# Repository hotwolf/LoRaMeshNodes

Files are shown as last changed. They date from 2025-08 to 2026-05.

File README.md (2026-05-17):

# LoRaMeshNodes
A collection of DIY LoRa mesh nodes:

- [MSNvA (Mobile Solar Node Variant A)](https://github.com/hotwolf/LoRaMeshNodes/tree/main/MSNvA)

  MSNvA
- [MSNvB (Mobile Solar Node Variant B)](https://github.com/hotwolf/LoRaMeshNodes/tree/main/MSNvB)

  MSNvB
- [MNvA  (Mobile Node Variant A)](https://github.com/hotwolf/LoRaMeshNodes/tree/main/MNvA)

  MNvA
- [MNvB  (Mobile Node Variant B)](https://github.com/hotwolf/LoRaMeshNodes/tree/main/MNvB)

  MNvB
- [SSNvA (Stationary Solar Node Variant A)](https://github.com/hotwolf/LoRaMeshNodes/tree/main/SSNvA)

  SSNvA
- [SSNvB (Stationary Solar Node Variant B)](https://github.com/hotwolf/LoRaMeshNodes/tree/main/SSNvB)

  SSNvB
- [SSNvD (Stationary Solar Node Variant D)](https://github.com/hotwolf/LoRaMeshNodes/tree/main/SSNvD)

  SSNvD

And tools:

- [LiFePo4Charger (A 1S 32700 LiFePO4 battery charger)](https://github.com/hotwolf/LoRaMeshNodes/tree/main/LiFePo4Charger)

  LiFePo4Charger

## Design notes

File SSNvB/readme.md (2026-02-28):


# LoRaMeshNodes
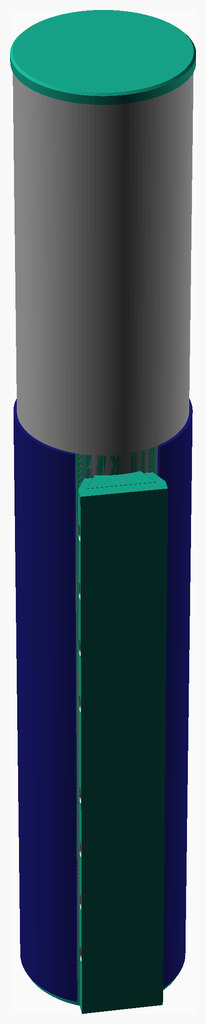
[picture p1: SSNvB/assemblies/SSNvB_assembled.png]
Main Assembly


<span></span>

---
## Table of Contents
1. [Parts list](#Parts_list)
1. [SSNvB Pipe Assembly](#SSNvB_pipe_assembly)
1. [SSNvB Solar Assembly](#SSNvB_solar_assembly)
1. [SSNvB Battery Cable Clamp Assembly](#SSNvB_battery_cable_clamp_assembly)
1. [SSNvB Battery Frame Assembly](#SSNvB_battery_frame_assembly)
1. [SSNvB Battery Assembly](#SSNvB_battery_assembly)
1. [SSNvB Radio Frame Assembly](#SSNvB_radio_frame_assembly)
1. [SSNvB Radio Assembly](#SSNvB_radio_assembly)
1. [SSNvB Antenna Assembly](#SSNvB_antenna_assembly)
1. [SSNvB Core Assembly](#SSNvB_core_assembly)
1. [SSNvB Assembly](#SSNvB_assembly)

<span></span>
[Top](#TOP)

---

## Parts list
| <span style="writing-mode: vertical-rl; text-orientation: mixed;">SSNvB&nbsp;Pipe</span> | <span style="writing-mode: vertical-rl; text-orientation: mixed;">SSNvB&nbsp;Solar</span> | <span style="writing-mode: vertical-rl; text-orientation: mixed;">SSNvB&nbsp;Battery&nbsp;Cable&nbsp;Clamp</span> | <span style="writing-mode: vertical-rl; text-orientation: mixed;">SSNvB&nbsp;Battery&nbsp;Frame</span> | <span style="writing-mode: vertical-rl; text-orientation: mixed;">SSNvB&nbsp;Battery</span> | <span style="writing-mode: vertical-rl; text-orientation: mixed;">SSNvB&nbsp;Radio&nbsp;Frame</span> | <span style="writing-mode: vertical-rl; text-orientation: mixed;">SSNvB&nbsp;Radio</span> | <span style="writing-mode: vertical-rl; text-orientation: mixed;">SSNvB&nbsp;Antenna</span> | <span style="writing-mode: vertical-rl; text-orientation: mixed;">SSNvB&nbsp;Core</span> | <span style="writing-mode: vertical-rl; text-orientation: mixed;">SSNvB</span> | <span style="writing-mode: vertical-rl; text-orientation: mixed;">TOTALS</span> |  |
|---:|---:|---:|---:|---:|---:|---:|---:|---:|---:|---:|:---|
|  |  |  |  |  |  |  |  |  |  | | **Vitamins** |
| &nbsp;&nbsp;.&nbsp; | &nbsp;&nbsp;.&nbsp; | &nbsp;&nbsp;.&nbsp; | &nbsp;&nbsp;.&nbsp; | &nbsp;&nbsp;1&nbsp; | &nbsp;&nbsp;.&nbsp; | &nbsp;&nbsp;.&nbsp; | &nbsp;&nbsp;.&nbsp; | &nbsp;&nbsp;.&nbsp; | &nbsp;&nbsp;.&nbsp; |  &nbsp;&nbsp;1&nbsp; | &nbsp;&nbsp; 1S 3.2V battery protection board |
| &nbsp;&nbsp;.&nbsp; | &nbsp;&nbsp;.&nbsp; | &nbsp;&nbsp;.&nbsp; | &nbsp;&nbsp;.&nbsp; | &nbsp;&nbsp;.&nbsp; | &nbsp;&nbsp;.&nbsp; | &nbsp;&nbsp;.&nbsp; | &nbsp;&nbsp;1&nbsp; | &nbsp;&nbsp;.&nbsp; | &nbsp;&nbsp;.&nbsp; |  &nbsp;&nbsp;1&nbsp; | &nbsp;&nbsp; Antenna with N-connector |
| &nbsp;&nbsp;.&nbsp; | &nbsp;&nbsp;.&nbsp; | &nbsp;&nbsp;.&nbsp; | &nbsp;&nbsp;.&nbsp; | &nbsp;&nbsp;1&nbsp; | &nbsp;&nbsp;.&nbsp; | &nbsp;&nbsp;.&nbsp; | &nbsp;&nbsp;.&nbsp; | &nbsp;&nbsp;.&nbsp; | &nbsp;&nbsp;.&nbsp; |  &nbsp;&nbsp;1&nbsp; | &nbsp;&nbsp; Battery negative contact |
| &nbsp;&nbsp;.&nbsp; | &nbsp;&nbsp;.&nbsp; | &nbsp;&nbsp;.&nbsp; | &nbsp;&nbsp;.&nbsp; | &nbsp;&nbsp;1&nbsp; | &nbsp;&nbsp;.&nbsp; | &nbsp;&nbsp;.&nbsp; | &nbsp;&nbsp;.&nbsp; | &nbsp;&nbsp;.&nbsp; | &nbsp;&nbsp;.&nbsp; |  &nbsp;&nbsp;1&nbsp; | &nbsp;&nbsp; Battery positive contact |
| &nbsp;&nbsp;1&nbsp; | &nbsp;&nbsp;.&nbsp; | &nbsp;&nbsp;.&nbsp; | &nbsp;&nbsp;.&nbsp; | &nbsp;&nbsp;.&nbsp; | &nbsp;&nbsp;.&nbsp; | &nbsp;&nbsp;.&nbsp; | &nbsp;&nbsp;.&nbsp; | &nbsp;&nbsp;.&nbsp; | &nbsp;&nbsp;.&nbsp; |  &nbsp;&nbsp;1&nbsp; | &nbsp;&nbsp; Conduit diameter 40mmlength 470mm |
| &nbsp;&nbsp;.&nbsp; | &nbsp;&nbsp;3&nbsp; | &nbsp;&nbsp;.&nbsp; | &nbsp;&nbsp;.&nbsp; | &nbsp;&nbsp;.&nbsp; | &nbsp;&nbsp;.&nbsp; | &nbsp;&nbsp;.&nbsp; | &nbsp;&nbsp;.&nbsp; | &nbsp;&nbsp;.&nbsp; | &nbsp;&nbsp;.&nbsp; |  &nbsp;&nbsp;3&nbsp; | &nbsp;&nbsp; Flexible Solar Panel 198x100mm² 6V 1W |
| &nbsp;&nbsp;.&nbsp; | &nbsp;&nbsp;.&nbsp; | &nbsp;&nbsp;.&nbsp; | &nbsp;&nbsp;.&nbsp; | &nbsp;&nbsp;.&nbsp; | &nbsp;&nbsp;.&nbsp; | &nbsp;&nbsp;1&nbsp; | &nbsp;&nbsp;.&nbsp; | &nbsp;&nbsp;.&nbsp; | &nbsp;&nbsp;.&nbsp; |  &nbsp;&nbsp;1&nbsp; | &nbsp;&nbsp; Heltec T144 |
| &nbsp;&nbsp;.&nbsp; | &nbsp;&nbsp;.&nbsp; | &nbsp;&nbsp;.&nbsp; | &nbsp;&nbsp;.&nbsp; | &nbsp;&nbsp;1&nbsp; | &nbsp;&nbsp;.&nbsp; | &nbsp;&nbsp;.&nbsp; | &nbsp;&nbsp;.&nbsp; | &nbsp;&nbsp;.&nbsp; | &nbsp;&nbsp;.&nbsp; |  &nbsp;&nbsp;1&nbsp; | &nbsp;&nbsp; Li-Ion/LiFePo4 32700 3.2v |
| &nbsp;&nbsp;.&nbsp; | &nbsp;&nbsp;.&nbsp; | &nbsp;&nbsp;.&nbsp; | &nbsp;&nbsp;.&nbsp; | &nbsp;&nbsp;1&nbsp; | &nbsp;&nbsp;.&nbsp; | &nbsp;&nbsp;.&nbsp; | &nbsp;&nbsp;.&nbsp; | &nbsp;&nbsp;.&nbsp; | &nbsp;&nbsp;.&nbsp; |  &nbsp;&nbsp;1&nbsp; | &nbsp;&nbsp; MPPT Solar Charge Controller |
| &nbsp;&nbsp;.&nbsp; | &nbsp;&nbsp;.&nbsp; | &nbsp;&nbsp;2&nbsp; | &nbsp;&nbsp;.&nbsp; | &nbsp;&nbsp;.&nbsp; | &nbsp;&nbsp;.&nbsp; | &nbsp;&nbsp;.&nbsp; | &nbsp;&nbsp;.&nbsp; | &nbsp;&nbsp;.&nbsp; | &nbsp;&nbsp;.&nbsp; |  &nbsp;&nbsp;2&nbsp; | &nbsp;&nbsp; Nut M3 x 2.4mm  |
| &nbsp;&nbsp;.&nbsp; | &nbsp;&nbsp;.&nbsp; | &nbsp;&nbsp;.&nbsp; | &nbsp;&nbsp;.&nbsp; | &nbsp;&nbsp;2&nbsp; | &nbsp;&nbsp;.&nbsp; | &nbsp;&nbsp;.&nbsp; | &nbsp;&nbsp;.&nbsp; | &nbsp;&nbsp;.&nbsp; | &nbsp;&nbsp;.&nbsp; |  &nbsp;&nbsp;2&nbsp; | &nbsp;&nbsp; Screw M3 pan x 10mm |
| &nbsp;&nbsp;.&nbsp; | &nbsp;&nbsp;.&nbsp; | &nbsp;&nbsp;.&nbsp; | &nbsp;&nbsp;.&nbsp; | &nbsp;&nbsp;2&nbsp; | &nbsp;&nbsp;.&nbsp; | &nbsp;&nbsp;.&nbsp; | &nbsp;&nbsp;.&nbsp; | &nbsp;&nbsp;.&nbsp; | &nbsp;&nbsp;.&nbsp; |  &nbsp;&nbsp;2&nbsp; | &nbsp;&nbsp; Washer  M3 x 7mm x 0.5mm |
| &nbsp;&nbsp;1&nbsp; | &nbsp;&nbsp;3&nbsp; | &nbsp;&nbsp;2&nbsp; | &nbsp;&nbsp;.&nbsp; | &nbsp;&nbsp;9&nbsp; | &nbsp;&nbsp;.&nbsp; | &nbsp;&nbsp;1&nbsp; | &nbsp;&nbsp;1&nbsp; | &nbsp;&nbsp;.&nbsp; | &nbsp;&nbsp;.&nbsp; | &nbsp;&nbsp;17&nbsp; | &nbsp;&nbsp;Total vitamins count |
|  |  |  |  |  |  |  |  |  |  | | **3D printed parts** |
| &nbsp;&nbsp;2&nbsp; | &nbsp;&nbsp;.&nbsp; | &nbsp;&nbsp;.&nbsp; | &nbsp;&nbsp;.&nbsp; | &nbsp;&nbsp;.&nbsp; | &nbsp;&nbsp;.&nbsp; | &nbsp;&nbsp;.&nbsp; | &nbsp;&nbsp;.&nbsp; | &nbsp;&nbsp;.&nbsp; | &nbsp;&nbsp;.&nbsp; |  &nbsp;&nbsp;2&nbsp; | &nbsp;&nbsp;SSNvB_EndcapThread.stl |
| &nbsp;&nbsp;1&nbsp; | &nbsp;&nbsp;.&nbsp; | &nbsp;&nbsp;.&nbsp; | &nbsp;&nbsp;.&nbsp; | &nbsp;&nbsp;.&nbsp; | &nbsp;&nbsp;.&nbsp; | &nbsp;&nbsp;.&nbsp; | &nbsp;&nbsp;.&nbsp; | &nbsp;&nbsp;.&nbsp; | &nbsp;&nbsp;.&nbsp; |  &nbsp;&nbsp;1&nbsp; | &nbsp;&nbsp;SSNvB_LIEncMount.stl |
| &nbsp;&nbsp;1&nbsp; | &nbsp;&nbsp;.&nbsp; | &nbsp;&nbsp;.&nbsp; | &nbsp;&nbsp;.&nbsp; | &nbsp;&nbsp;.&nbsp; | &nbsp;&nbsp;.&nbsp; | &nbsp;&nbsp;.&nbsp; | &nbsp;&nbsp;.&nbsp; | &nbsp;&nbsp;.&nbsp; | &nbsp;&nbsp;.&nbsp; |  &nbsp;&nbsp;1&nbsp; | &nbsp;&nbsp;SSNvB_LOEncMount.stl |
| &nbsp;&nbsp;1&nbsp; | &nbsp;&nbsp;.&nbsp; | &nbsp;&nbsp;.&nbsp; | &nbsp;&nbsp;.&nbsp; | &nbsp;&nbsp;.&nbsp; | &nbsp;&nbsp;.&nbsp; | &nbsp;&nbsp;.&nbsp; | &nbsp;&nbsp;.&nbsp; | &nbsp;&nbsp;.&nbsp; | &nbsp;&nbsp;.&nbsp; |  &nbsp;&nbsp;1&nbsp; | &nbsp;&nbsp;SSNvB_UIEncMount.stl |
| &nbsp;&nbsp;1&nbsp; | &nbsp;&nbsp;.&nbsp; | &nbsp;&nbsp;.&nbsp; | &nbsp;&nbsp;.&nbsp; | &nbsp;&nbsp;.&nbsp; | &nbsp;&nbsp;.&nbsp; | &nbsp;&nbsp;.&nbsp; | &nbsp;&nbsp;.&nbsp; | &nbsp;&nbsp;.&nbsp; | &nbsp;&nbsp;.&nbsp; |  &nbsp;&nbsp;1&nbsp; | &nbsp;&nbsp;SSNvB_UOEncMount.stl |
| &nbsp;&nbsp;.&nbsp; | &nbsp;&nbsp;.&nbsp; | &nbsp;&nbsp;.&nbsp; | &nbsp;&nbsp;.&nbsp; | &nbsp;&nbsp;.&nbsp; | &nbsp;&nbsp;.&nbsp; | &nbsp;&nbsp;.&nbsp; | &nbsp;&nbsp;1&nbsp; | &nbsp;&nbsp;.&nbsp; | &nbsp;&nbsp;.&nbsp; |  &nbsp;&nbsp;1&nbsp; | &nbsp;&nbsp;SSNvB_antenna.stl |
| &nbsp;&nbsp;.&nbsp; | &nbsp;&nbsp;.&nbsp; | &nbsp;&nbsp;.&nbsp; | &nbsp;&nbsp;.&nbsp; | &nbsp;&nbsp;.&nbsp; | &nbsp;&nbsp;.&nbsp; | &nbsp;&nbsp;.&nbsp; | &nbsp;&nbsp;.&nbsp; | &nbsp;&nbsp;.&nbsp; | &nbsp;&nbsp;1&nbsp; |  &nbsp;&nbsp;1&nbsp; | &nbsp;&nbsp;SSNvB_antennaMountFastener.stl |
| &nbsp;&nbsp;1&nbsp; | &nbsp;&nbsp;.&nbsp; | &nbsp;&nbsp;.&nbsp; | &nbsp;&nbsp;.&nbsp; | &nbsp;&nbsp;.&nbsp; | &nbsp;&nbsp;.&nbsp; | &nbsp;&nbsp;.&nbsp; | &nbsp;&nbsp;.&nbsp; | &nbsp;&nbsp;.&nbsp; | &nbsp;&nbsp;.&nbsp; |  &nbsp;&nbsp;1&nbsp; | &nbsp;&nbsp;SSNvB_antennaMountThread.stl |
| &nbsp;&nbsp;.&nbsp; | &nbsp;&nbsp;.&nbsp; | &nbsp;&nbsp;1&nbsp; | &nbsp;&nbsp;.&nbsp; | &nbsp;&nbsp;.&nbsp; | &nbsp;&nbsp;.&nbsp; | &nbsp;&nbsp;.&nbsp; | &nbsp;&nbsp;.&nbsp; | &nbsp;&nbsp;.&nbsp; | &nbsp;&nbsp;.&nbsp; |  &nbsp;&nbsp;1&nbsp; | &nbsp;&nbsp;SSNvB_battery_cable_clamp.stl |
| &nbsp;&nbsp;.&nbsp; | &nbsp;&nbsp;.&nbsp; | &nbsp;&nbsp;.&nbsp; | &nbsp;&nbsp;1&nbsp; | &nbsp;&nbsp;.&nbsp; | &nbsp;&nbsp;.&nbsp; | &nbsp;&nbsp;.&nbsp; | &nbsp;&nbsp;.&nbsp; | &nbsp;&nbsp;.&nbsp; | &nbsp;&nbsp;.&nbsp; |  &nbsp;&nbsp;1&nbsp; | &nbsp;&nbsp;SSNvB_battery_frame_part1.stl |
| &nbsp;&nbsp;.&nbsp; | &nbsp;&nbsp;.&nbsp; | &nbsp;&nbsp;.&nbsp; | &nbsp;&nbsp;1&nbsp; | &nbsp;&nbsp;.&nbsp; | &nbsp;&nbsp;.&nbsp; | &nbsp;&nbsp;.&nbsp; | &nbsp;&nbsp;.&nbsp; | &nbsp;&nbsp;.&nbsp; | &nbsp;&nbsp;.&nbsp; |  &nbsp;&nbsp;1&nbsp; | &nbsp;&nbsp;SSNvB_battery_frame_part2.stl |
| &nbsp;&nbsp;.&nbsp; | &nbsp;&nbsp;.&nbsp; | &nbsp;&nbsp;.&nbsp; | &nbsp;&nbsp;.&nbsp; | &nbsp;&nbsp;.&nbsp; | &nbsp;&nbsp;.&nbsp; | &nbsp;&nbsp;.&nbsp; | &nbsp;&nbsp;.&nbsp; | &nbsp;&nbsp;.&nbsp; | &nbsp;&nbsp;1&nbsp; |  &nbsp;&nbsp;1&nbsp; | &nbsp;&nbsp;SSNvB_lEndcap.stl |
| &nbsp;&nbsp;.&nbsp; | &nbsp;&nbsp;.&nbsp; | &nbsp;&nbsp;.&nbsp; | &nbsp;&nbsp;.&nbsp; | &nbsp;&nbsp;.&nbsp; | &nbsp;&nbsp;1&nbsp; | &nbsp;&nbsp;.&nbsp; | &nbsp;&nbsp;.&nbsp; | &nbsp;&nbsp;.&nbsp; | &nbsp;&nbsp;.&nbsp; |  &nbsp;&nbsp;1&nbsp; | &nbsp;&nbsp;SSNvB_radio_frame_part1.stl |
| &nbsp;&nbsp;.&nbsp; | &nbsp;&nbsp;.&nbsp; | &nbsp;&nbsp;.&nbsp; | &nbsp;&nbsp;.&nbsp; | &nbsp;&nbsp;.&nbsp; | &nbsp;&nbsp;1&nbsp; | &nbsp;&nbsp;.&nbsp; | &nbsp;&nbsp;.&nbsp; | &nbsp;&nbsp;.&nbsp; | &nbsp;&nbsp;.&nbsp; |  &nbsp;&nbsp;1&nbsp; | &nbsp;&nbsp;SSNvB_radio_frame_part2.stl |
| &nbsp;&nbsp;.&nbsp; | &nbsp;&nbsp;.&nbsp; | &nbsp;&nbsp;.&nbsp; | &nbsp;&nbsp;.&nbsp; | &nbsp;&nbsp;.&nbsp; | &nbsp;&nbsp;.&nbsp; | &nbsp;&nbsp;.&nbsp; | &nbsp;&nbsp;.&nbsp; | &nbsp;&nbsp;.&nbsp; | &nbsp;&nbsp;1&nbsp; |  &nbsp;&nbsp;1&nbsp; | &nbsp;&nbsp;SSNvB_uEndcap.stl |
| &nbsp;&nbsp;7&nbsp; | &nbsp;&nbsp;.&nbsp; | &nbsp;&nbsp;1&nbsp; | &nbsp;&nbsp;2&nbsp; | &nbsp;&nbsp;.&nbsp; | &nbsp;&nbsp;2&nbsp; | &nbsp;&nbsp;.&nbsp; | &nbsp;&nbsp;1&nbsp; | &nbsp;&nbsp;.&nbsp; | &nbsp;&nbsp;3&nbsp; | &nbsp;&nbsp;16&nbsp; | &nbsp;&nbsp;Total 3D printed parts count |

<span></span>
[Top](#TOP)

---

## SSNvB Pipe Assembly
### Vitamins
|Qty|Description|
|---:|:---|
|1| Conduit diameter 40mmlength 470mm|

### 3D Printed parts

| 2 x [SSNvB_EndcapThread.stl](stls/SSNvB_EndcapThread.stl) | 1 x [SSNvB_LIEncMount.stl](stls/SSNvB_LIEncMount.stl) | 1 x [SSNvB_LOEncMount.stl](stls/SSNvB_LOEncMount.stl) |
|---|---|---|
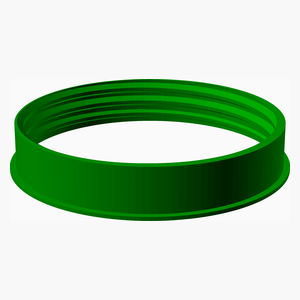
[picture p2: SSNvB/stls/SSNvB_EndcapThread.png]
SSNvB_EndcapThread.stl
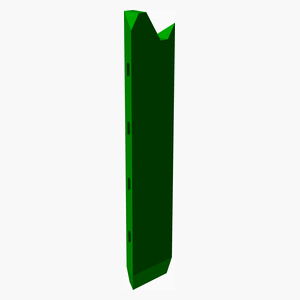
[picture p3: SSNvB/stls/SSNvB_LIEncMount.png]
SSNvB_LIEncMount.stl
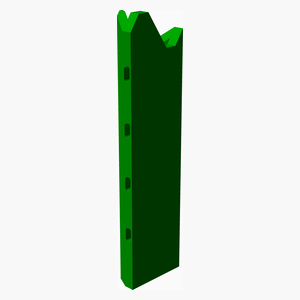
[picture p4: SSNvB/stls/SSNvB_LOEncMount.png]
SSNvB_LOEncMount.stl
|  |  |  

| 1 x [SSNvB_UIEncMount.stl](stls/SSNvB_UIEncMount.stl) | 1 x [SSNvB_UOEncMount.stl](stls/SSNvB_UOEncMount.stl) | 1 x [SSNvB_antennaMountThread.stl](stls/SSNvB_antennaMountThread.stl) |
|---|---|---|
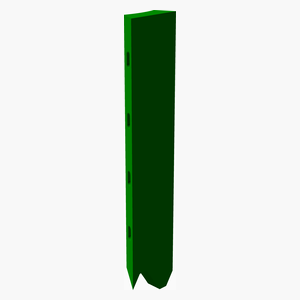
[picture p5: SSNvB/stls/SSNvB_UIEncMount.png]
SSNvB_UIEncMount.stl
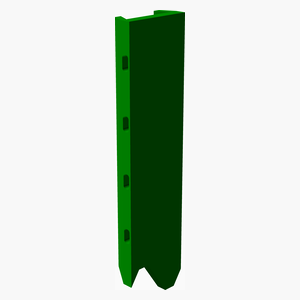
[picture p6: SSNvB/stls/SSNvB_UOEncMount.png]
SSNvB_UOEncMount.stl
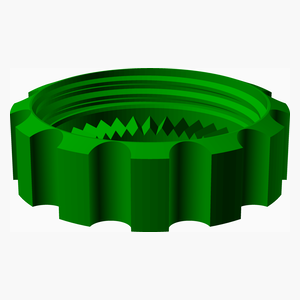
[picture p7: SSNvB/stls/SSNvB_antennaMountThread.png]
SSNvB_antennaMountThread.stl
|  |  |  

### Assembly instructions
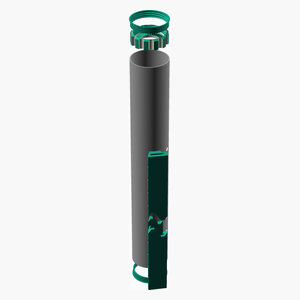
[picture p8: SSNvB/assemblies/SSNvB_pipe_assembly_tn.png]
SSNvB_pipe_assembly


1. Cut the DN75 pipe to the desired length
2. Drill 10mm holes for the solar panel connectors
3. Glue in the antenna holder and the two end cap threads
4. Glue on enclosure mount

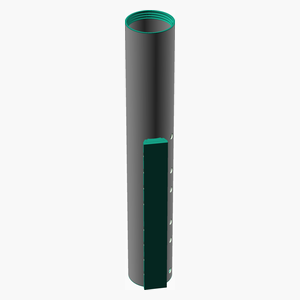
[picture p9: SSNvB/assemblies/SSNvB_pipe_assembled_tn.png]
SSNvB_pipe_assembled


<span></span>
[Top](#TOP)

---

## SSNvB Solar Assembly
### Vitamins
|Qty|Description|
|---:|:---|
|3| Flexible Solar Panel 198x100mm² 6V 1W|

### Sub-assemblies

| 1 x SSNvB_pipe_assembly |
|---|
| SSNvB_pipe_assembled 

### Assembly instructions
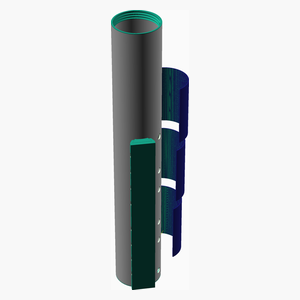
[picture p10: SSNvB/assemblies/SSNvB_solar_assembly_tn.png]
SSNvB_solar_assembly


1. Solder wires onto the solar panels terminals
2. Glue solar panels around the pipe 

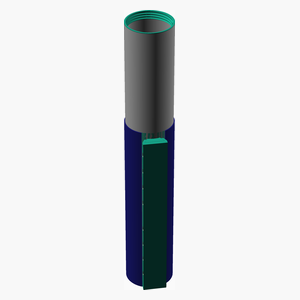
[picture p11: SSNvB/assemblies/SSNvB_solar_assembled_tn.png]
SSNvB_solar_assembled


<span></span>
[Top](#TOP)

---

## SSNvB Battery Cable Clamp Assembly
### Vitamins
|Qty|Description|
|---:|:---|
|2| Nut M3 x 2.4mm |

### 3D Printed parts

| 1 x [SSNvB_battery_cable_clamp.stl](stls/SSNvB_battery_cable_clamp.stl) |
|---|
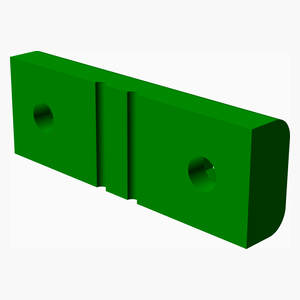
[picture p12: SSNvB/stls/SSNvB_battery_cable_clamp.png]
SSNvB_battery_cable_clamp.stl
|  

### Assembly instructions
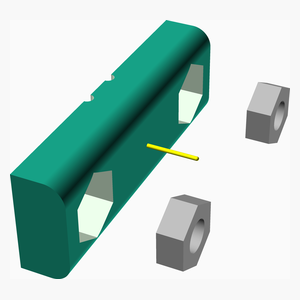
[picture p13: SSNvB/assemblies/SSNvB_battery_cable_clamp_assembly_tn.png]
SSNvB_battery_cable_clamp_assembly


Insert two M3 waschers into the cable clamp

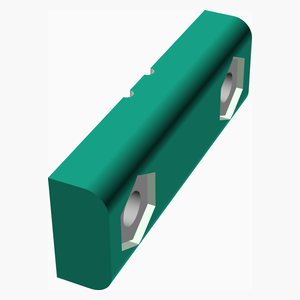
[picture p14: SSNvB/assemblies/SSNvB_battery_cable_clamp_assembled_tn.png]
SSNvB_battery_cable_clamp_assembled


<span></span>
[Top](#TOP)

---

## SSNvB Battery Frame Assembly
### 3D Printed parts

| 1 x [SSNvB_battery_frame_part1.stl](stls/SSNvB_battery_frame_part1.stl) | 1 x [SSNvB_battery_frame_part2.stl](stls/SSNvB_battery_frame_part2.stl) |
|---|---|
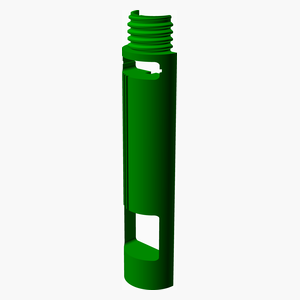
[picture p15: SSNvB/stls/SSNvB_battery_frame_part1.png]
SSNvB_battery_frame_part1.stl
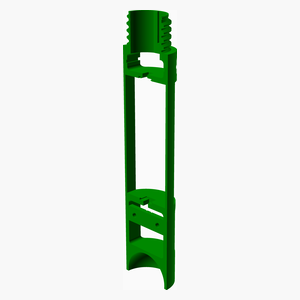
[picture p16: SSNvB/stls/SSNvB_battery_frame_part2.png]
SSNvB_battery_frame_part2.stl
|  |  

### Assembly instructions
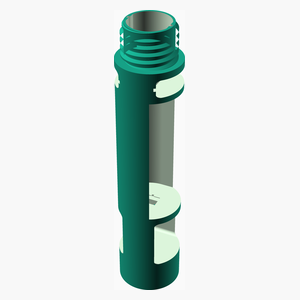
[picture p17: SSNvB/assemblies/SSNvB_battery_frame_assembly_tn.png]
SSNvB_battery_frame_assembly


Glue the two pieces of the frame together

SSNvB_battery_frame_assembled

<span></span>
[Top](#TOP)

---

## SSNvB Battery Assembly
### Vitamins
|Qty|Description|
|---:|:---|
|1| 1S 3.2V battery protection board|
|1| Battery negative contact|
|1| Battery positive contact|
|1| Li-Ion/LiFePo4 32700 3.2v|
|1| MPPT Solar Charge Controller|
|2| Screw M3 pan x 10mm|
|2| Washer  M3 x 7mm x 0.5mm|

### Sub-assemblies

| 1 x SSNvB_battery_cable_clamp_assembly | 1 x SSNvB_battery_frame_assembly |
|---|---|
| SSNvB_battery_cable_clamp_assembled | SSNvB_battery_frame_assembled 

### Assembly instructions
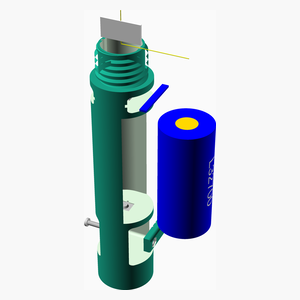
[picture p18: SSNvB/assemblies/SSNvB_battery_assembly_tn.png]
SSNvB_battery_assembly


Solder and assemble components

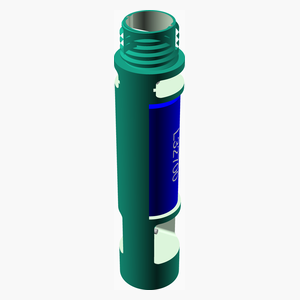
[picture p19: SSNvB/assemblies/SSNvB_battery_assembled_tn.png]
SSNvB_battery_assembled


<span></span>
[Top](#TOP)

---

## SSNvB Radio Frame Assembly
### 3D Printed parts

| 1 x [SSNvB_radio_frame_part1.stl](stls/SSNvB_radio_frame_part1.stl) | 1 x [SSNvB_radio_frame_part2.stl](stls/SSNvB_radio_frame_part2.stl) |
|---|---|
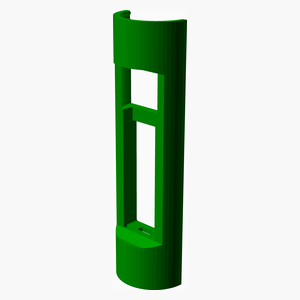
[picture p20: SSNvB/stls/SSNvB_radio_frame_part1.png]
SSNvB_radio_frame_part1.stl
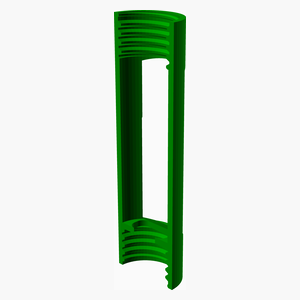
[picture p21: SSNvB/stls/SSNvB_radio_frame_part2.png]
SSNvB_radio_frame_part2.stl
|  |  

### Assembly instructions
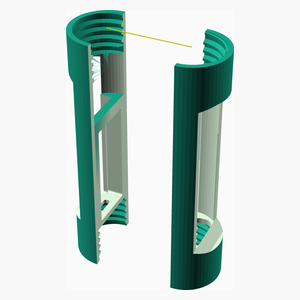
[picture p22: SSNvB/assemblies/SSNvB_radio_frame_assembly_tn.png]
SSNvB_radio_frame_assembly


1. Glue the two parts of the radio frame together

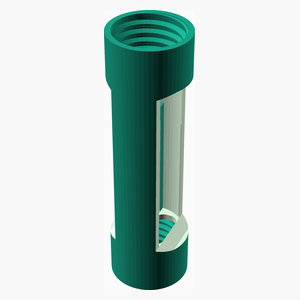
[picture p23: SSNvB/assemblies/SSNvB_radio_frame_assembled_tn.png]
SSNvB_radio_frame_assembled


<span></span>
[Top](#TOP)

---

## SSNvB Radio Assembly
### Vitamins
|Qty|Description|
|---:|:---|
|1| Heltec T144|

### Sub-assemblies

| 1 x SSNvB_radio_frame_assembly |
|---|
| SSNvB_radio_frame_assembled 

### Assembly instructions
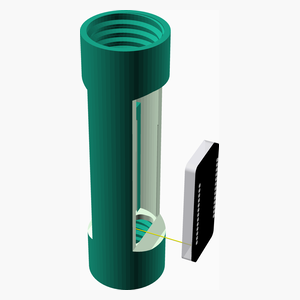
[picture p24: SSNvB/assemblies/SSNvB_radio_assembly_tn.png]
SSNvB_radio_assembly


1. Attach the cable clamp with two M3 screws
2. Insert the Heltec T114
3. Attach the power cable
4. Tighten cable clamp

SSNvB_radio_assembled

<span></span>
[Top](#TOP)

---

## SSNvB Antenna Assembly
### Vitamins
|Qty|Description|
|---:|:---|
|1| Antenna with N-connector|

### 3D Printed parts

| 1 x [SSNvB_antenna.stl](stls/SSNvB_antenna.stl) |
|---|
| SSNvB_antenna.stl 

### Assembly instructions
SSNvB_antenna_assembly

1. Attach the antenna to the frame.  

SSNvB_antenna_assembled

<span></span>
[Top](#TOP)

---

## SSNvB Core Assembly
### Sub-assemblies

| 1 x SSNvB_antenna_assembly | 1 x SSNvB_battery_assembly | 1 x SSNvB_radio_assembly |
|---|---|---|
| SSNvB_antenna_assembled | SSNvB_battery_assembled | SSNvB_radio_assembled 

### Assembly instructions
SSNvB_core_assembly

1. Attach antenna, radio and battery frame

SSNvB_core_assembled

<span></span>
[Top](#TOP)

---

## SSNvB Assembly
### 3D Printed parts

| 1 x [SSNvB_antennaMountFastener.stl](stls/SSNvB_antennaMountFastener.stl) | 1 x [SSNvB_lEndcap.stl](stls/SSNvB_lEndcap.stl) | 1 x [SSNvB_uEndcap.stl](stls/SSNvB_uEndcap.stl) |
|---|---|---|
| SSNvB_antennaMountFastener.stl | SSNvB_lEndcap.stl | SSNvB_uEndcap.stl 

### Sub-assemblies

| 1 x SSNvB_core_assembly | 1 x SSNvB_solar_assembly |
|---|---|
| SSNvB_core_assembled | SSNvB_solar_assembled 

### Assembly instructions
SSNvB_assembly

1. Slide the antenna and radio into the top end of the pole
2. Screw in antenna fastener
3. Attach the power cable of the antenna to the MPPT controller
4. Attach the end caps

SSNvB_assembled

<span></span>
[Top](#TOP)

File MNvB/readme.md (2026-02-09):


# LoRaMeshNodes
These are the assembly instructions for the Mobile Node (Variant A) (MNvA),
a portable [Meshtastic](https://meshtastic.org) or
[MeshCore](https://meshcore.co.uk) node.

Main Assembly

<span></span>

---
## Table of Contents
1. [Parts list](#Parts_list)
1. [MNvB LEnc Assembly](#MNvB_lEnc_assembly)
1. [MNvB Assembly](#MNvB_assembly)

<span></span>
[Top](#TOP)

---

## Parts list
| <span style="writing-mode: vertical-rl; text-orientation: mixed;">MNvB&nbsp;LEnc</span> | <span style="writing-mode: vertical-rl; text-orientation: mixed;">MNvB</span> | <span style="writing-mode: vertical-rl; text-orientation: mixed;">TOTALS</span> |  |
|---:|---:|---:|:---|
|  |  | | **Vitamins** |
| &nbsp;&nbsp;.&nbsp; | &nbsp;&nbsp;1&nbsp; |  &nbsp;&nbsp;1&nbsp; | &nbsp;&nbsp; 1S 3.7V battery protection board |
| &nbsp;&nbsp;.&nbsp; | &nbsp;&nbsp;1&nbsp; |  &nbsp;&nbsp;1&nbsp; | &nbsp;&nbsp; Antenna 20cm LoRa Antenna |
| &nbsp;&nbsp;.&nbsp; | &nbsp;&nbsp;1&nbsp; |  &nbsp;&nbsp;1&nbsp; | &nbsp;&nbsp; Cell Samsung 25R 18650 LION |
| &nbsp;&nbsp;.&nbsp; | &nbsp;&nbsp;1&nbsp; |  &nbsp;&nbsp;1&nbsp; | &nbsp;&nbsp; Heltec T144 |
| &nbsp;&nbsp;2&nbsp; | &nbsp;&nbsp;.&nbsp; |  &nbsp;&nbsp;2&nbsp; | &nbsp;&nbsp; Nut M3 x 2.4mm  |
| &nbsp;&nbsp;.&nbsp; | &nbsp;&nbsp;1&nbsp; |  &nbsp;&nbsp;1&nbsp; | &nbsp;&nbsp; Nut M6.25 x 1.8mm  |
| &nbsp;&nbsp;.&nbsp; | &nbsp;&nbsp;2&nbsp; |  &nbsp;&nbsp;2&nbsp; | &nbsp;&nbsp; Screw M3 dome x 10mm |
| &nbsp;&nbsp;.&nbsp; | &nbsp;&nbsp;1&nbsp; |  &nbsp;&nbsp;1&nbsp; | &nbsp;&nbsp; Washer star M6.4 x 0.6mm |
| &nbsp;&nbsp;2&nbsp; | &nbsp;&nbsp;8&nbsp; | &nbsp;&nbsp;10&nbsp; | &nbsp;&nbsp;Total vitamins count |
|  |  | | **3D printed parts** |
| &nbsp;&nbsp;.&nbsp; | &nbsp;&nbsp;1&nbsp; |  &nbsp;&nbsp;1&nbsp; | &nbsp;&nbsp;MNvB_buttons.stl |
| &nbsp;&nbsp;1&nbsp; | &nbsp;&nbsp;.&nbsp; |  &nbsp;&nbsp;1&nbsp; | &nbsp;&nbsp;MNvB_lEnc.stl |
| &nbsp;&nbsp;.&nbsp; | &nbsp;&nbsp;1&nbsp; |  &nbsp;&nbsp;1&nbsp; | &nbsp;&nbsp;MNvB_uEnc.stl |
| &nbsp;&nbsp;1&nbsp; | &nbsp;&nbsp;2&nbsp; | &nbsp;&nbsp;3&nbsp; | &nbsp;&nbsp;Total 3D printed parts count |

<span></span>
[Top](#TOP)

---

## MNvB LEnc Assembly
### Vitamins
|Qty|Description|
|---:|:---|
|2| Nut M3 x 2.4mm |

### 3D Printed parts

| 1 x [MNvB_lEnc.stl](stls/MNvB_lEnc.stl) |
|---|
| MNvB_lEnc.stl 

### Assembly instructions
MNvB_lEnc_assembly

Insert nuts during print

MNvB_lEnc_assembled

<span></span>
[Top](#TOP)

---

## MNvB Assembly
### Vitamins
|Qty|Description|
|---:|:---|
|1| 1S 3.7V battery protection board|
|1| Antenna 20cm LoRa Antenna|
|1| Cell Samsung 25R 18650 LION|
|1| Heltec T144|
|1| Nut M6.25 x 1.8mm |
|2| Screw M3 dome x 10mm|
|1| Washer star M6.4 x 0.6mm|

### 3D Printed parts

| 1 x [MNvB_buttons.stl](stls/MNvB_buttons.stl) | 1 x [MNvB_uEnc.stl](stls/MNvB_uEnc.stl) |
|---|---|
| MNvB_buttons.stl | MNvB_uEnc.stl 

### Sub-assemblies

| 1 x MNvB_lEnc_assembly |
|---|
| MNvB_lEnc_assembled 

### Assembly instructions
MNvB_assembly

Insert components, attach top and fasten screws.

MNvB_assembled

<span></span>
[Top](#TOP)

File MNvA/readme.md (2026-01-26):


# LoRaMeshNodes
These are the assembly instructions for the Mobile Node (Variant A) (MNvA),
a portable [Meshtastic](https://meshtastic.org) or
[MeshCore](https://meshcore.co.uk) node.

Main Assembly

<span></span>

---
## Table of Contents
1. [Parts list](#Parts_list)
1. [MNvA LEnc Assembly](#MNvA_lEnc_assembly)
1. [MNvA Assembly](#MNvA_assembly)

<span></span>
[Top](#TOP)

---

## Parts list
| <span style="writing-mode: vertical-rl; text-orientation: mixed;">MNvA&nbsp;LEnc</span> | <span style="writing-mode: vertical-rl; text-orientation: mixed;">MNvA</span> | <span style="writing-mode: vertical-rl; text-orientation: mixed;">TOTALS</span> |  |
|---:|---:|---:|:---|
|  |  | | **Vitamins** |
| &nbsp;&nbsp;.&nbsp; | &nbsp;&nbsp;1&nbsp; |  &nbsp;&nbsp;1&nbsp; | &nbsp;&nbsp; Antenna 20cm LoRa Antenna |
| &nbsp;&nbsp;.&nbsp; | &nbsp;&nbsp;1&nbsp; |  &nbsp;&nbsp;1&nbsp; | &nbsp;&nbsp; Heltec T144 |
| &nbsp;&nbsp;.&nbsp; | &nbsp;&nbsp;1&nbsp; |  &nbsp;&nbsp;1&nbsp; | &nbsp;&nbsp; Lithium-Polymer-Akku 3,7V 3000mAh |
| &nbsp;&nbsp;2&nbsp; | &nbsp;&nbsp;.&nbsp; |  &nbsp;&nbsp;2&nbsp; | &nbsp;&nbsp; Nut M3 x 2.4mm  |
| &nbsp;&nbsp;.&nbsp; | &nbsp;&nbsp;1&nbsp; |  &nbsp;&nbsp;1&nbsp; | &nbsp;&nbsp; Nut M6.25 x 1.8mm  |
| &nbsp;&nbsp;.&nbsp; | &nbsp;&nbsp;2&nbsp; |  &nbsp;&nbsp;2&nbsp; | &nbsp;&nbsp; Screw M3 dome x 10mm |
| &nbsp;&nbsp;.&nbsp; | &nbsp;&nbsp;1&nbsp; |  &nbsp;&nbsp;1&nbsp; | &nbsp;&nbsp; Washer star M6.4 x 0.6mm |
| &nbsp;&nbsp;2&nbsp; | &nbsp;&nbsp;7&nbsp; | &nbsp;&nbsp;9&nbsp; | &nbsp;&nbsp;Total vitamins count |
|  |  | | **3D printed parts** |
| &nbsp;&nbsp;.&nbsp; | &nbsp;&nbsp;1&nbsp; |  &nbsp;&nbsp;1&nbsp; | &nbsp;&nbsp;MNvA_buttons.stl |
| &nbsp;&nbsp;1&nbsp; | &nbsp;&nbsp;.&nbsp; |  &nbsp;&nbsp;1&nbsp; | &nbsp;&nbsp;MNvA_lEnc.stl |
| &nbsp;&nbsp;.&nbsp; | &nbsp;&nbsp;1&nbsp; |  &nbsp;&nbsp;1&nbsp; | &nbsp;&nbsp;MNvA_uEnc.stl |
| &nbsp;&nbsp;1&nbsp; | &nbsp;&nbsp;2&nbsp; | &nbsp;&nbsp;3&nbsp; | &nbsp;&nbsp;Total 3D printed parts count |

<span></span>
[Top](#TOP)

---

## MNvA LEnc Assembly
### Vitamins
|Qty|Description|
|---:|:---|
|2| Nut M3 x 2.4mm |

### 3D Printed parts

| 1 x [MNvA_lEnc.stl](stls/MNvA_lEnc.stl) |
|---|
| MNvA_lEnc.stl 

### Assembly instructions
MNvA_lEnc_assembly

Insert nuts during print

MNvA_lEnc_assembled

<span></span>
[Top](#TOP)

---

## MNvA Assembly
### Vitamins
|Qty|Description|
|---:|:---|
|1| Antenna 20cm LoRa Antenna|
|1| Heltec T144|
|1| Lithium-Polymer-Akku 3,7V 3000mAh|
|1| Nut M6.25 x 1.8mm |
|2| Screw M3 dome x 10mm|
|1| Washer star M6.4 x 0.6mm|

### 3D Printed parts

| 1 x [MNvA_buttons.stl](stls/MNvA_buttons.stl) | 1 x [MNvA_uEnc.stl](stls/MNvA_uEnc.stl) |
|---|---|
| MNvA_buttons.stl | MNvA_uEnc.stl 

### Sub-assemblies

| 1 x MNvA_lEnc_assembly |
|---|
| MNvA_lEnc_assembled 

### Assembly instructions
MNvA_assembly

Insert components, attach top and fasten screws.

MNvA_assembled

<span></span>
[Top](#TOP)

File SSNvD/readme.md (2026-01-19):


# LoRaMeshNodes
Main Assembly

<span></span>

---
## Table of Contents
1. [Parts list](#Parts_list)
1. [SSNvD Spacer Assembly](#SSNvD_spacer_assembly)
1. [SSNvD Solar Mount Assembly](#SSNvD_solar_mount_assembly)
1. [SSNvD Battery Cable Clamp Assembly](#SSNvD_battery_cable_clamp_assembly)
1. [SSNvD Battery Frame Assembly](#SSNvD_battery_frame_assembly)
1. [SSNvD Battery Assembly](#SSNvD_battery_assembly)
1. [SSNvD Radio Frame Assembly](#SSNvD_radio_frame_assembly)
1. [SSNvD Radio Assembly](#SSNvD_radio_assembly)
1. [SSNvD Antenna Frame Assembly](#SSNvD_antenna_frame_assembly)
1. [SSNvD Antenna Assembly](#SSNvD_antenna_assembly)
1. [SSNvD Top Assembly](#SSNvD_top_assembly)
1. [SSNvD Pole Assembly](#SSNvD_pole_assembly)
1. [SSNvD Assembly](#SSNvD_assembly)

<span></span>
[Top](#TOP)

---

## Parts list
| <span style="writing-mode: vertical-rl; text-orientation: mixed;">2 x SSNvD&nbsp;Spacer</span> | <span style="writing-mode: vertical-rl; text-orientation: mixed;">SSNvD&nbsp;Solar&nbsp;Mount</span> | <span style="writing-mode: vertical-rl; text-orientation: mixed;">SSNvD&nbsp;Battery&nbsp;Cable&nbsp;Clamp</span> | <span style="writing-mode: vertical-rl; text-orientation: mixed;">SSNvD&nbsp;Battery&nbsp;Frame</span> | <span style="writing-mode: vertical-rl; text-orientation: mixed;">SSNvD&nbsp;Battery</span> | <span style="writing-mode: vertical-rl; text-orientation: mixed;">SSNvD&nbsp;Radio&nbsp;Frame</span> | <span style="writing-mode: vertical-rl; text-orientation: mixed;">SSNvD&nbsp;Radio</span> | <span style="writing-mode: vertical-rl; text-orientation: mixed;">SSNvD&nbsp;Antenna&nbsp;Frame</span> | <span style="writing-mode: vertical-rl; text-orientation: mixed;">SSNvD&nbsp;Antenna</span> | <span style="writing-mode: vertical-rl; text-orientation: mixed;">SSNvD&nbsp;Top</span> | <span style="writing-mode: vertical-rl; text-orientation: mixed;">SSNvD&nbsp;Pole</span> | <span style="writing-mode: vertical-rl; text-orientation: mixed;">SSNvD</span> | <span style="writing-mode: vertical-rl; text-orientation: mixed;">TOTALS</span> |  |
|---:|---:|---:|---:|---:|---:|---:|---:|---:|---:|---:|---:|---:|:---|
|  |  |  |  |  |  |  |  |  |  |  |  | | **Vitamins** |
| &nbsp;&nbsp;.&nbsp; | &nbsp;&nbsp;.&nbsp; | &nbsp;&nbsp;.&nbsp; | &nbsp;&nbsp;.&nbsp; | &nbsp;&nbsp;1&nbsp; | &nbsp;&nbsp;.&nbsp; | &nbsp;&nbsp;.&nbsp; | &nbsp;&nbsp;.&nbsp; | &nbsp;&nbsp;.&nbsp; | &nbsp;&nbsp;.&nbsp; | &nbsp;&nbsp;.&nbsp; | &nbsp;&nbsp;.&nbsp; |  &nbsp;&nbsp;1&nbsp; | &nbsp;&nbsp; 1S 3.2V battery protection board |
| &nbsp;&nbsp;.&nbsp; | &nbsp;&nbsp;.&nbsp; | &nbsp;&nbsp;.&nbsp; | &nbsp;&nbsp;.&nbsp; | &nbsp;&nbsp;.&nbsp; | &nbsp;&nbsp;.&nbsp; | &nbsp;&nbsp;.&nbsp; | &nbsp;&nbsp;.&nbsp; | &nbsp;&nbsp;1&nbsp; | &nbsp;&nbsp;.&nbsp; | &nbsp;&nbsp;.&nbsp; | &nbsp;&nbsp;.&nbsp; |  &nbsp;&nbsp;1&nbsp; | &nbsp;&nbsp; Antenna with N-connector |
| &nbsp;&nbsp;.&nbsp; | &nbsp;&nbsp;.&nbsp; | &nbsp;&nbsp;.&nbsp; | &nbsp;&nbsp;.&nbsp; | &nbsp;&nbsp;1&nbsp; | &nbsp;&nbsp;.&nbsp; | &nbsp;&nbsp;.&nbsp; | &nbsp;&nbsp;.&nbsp; | &nbsp;&nbsp;.&nbsp; | &nbsp;&nbsp;.&nbsp; | &nbsp;&nbsp;.&nbsp; | &nbsp;&nbsp;.&nbsp; |  &nbsp;&nbsp;1&nbsp; | &nbsp;&nbsp; Battery negative contact |
| &nbsp;&nbsp;.&nbsp; | &nbsp;&nbsp;.&nbsp; | &nbsp;&nbsp;.&nbsp; | &nbsp;&nbsp;.&nbsp; | &nbsp;&nbsp;1&nbsp; | &nbsp;&nbsp;.&nbsp; | &nbsp;&nbsp;.&nbsp; | &nbsp;&nbsp;.&nbsp; | &nbsp;&nbsp;.&nbsp; | &nbsp;&nbsp;.&nbsp; | &nbsp;&nbsp;.&nbsp; | &nbsp;&nbsp;.&nbsp; |  &nbsp;&nbsp;1&nbsp; | &nbsp;&nbsp; Battery positive contact |
| &nbsp;&nbsp;.&nbsp; | &nbsp;&nbsp;.&nbsp; | &nbsp;&nbsp;.&nbsp; | &nbsp;&nbsp;.&nbsp; | &nbsp;&nbsp;.&nbsp; | &nbsp;&nbsp;.&nbsp; | &nbsp;&nbsp;.&nbsp; | &nbsp;&nbsp;.&nbsp; | &nbsp;&nbsp;.&nbsp; | &nbsp;&nbsp;.&nbsp; | &nbsp;&nbsp;1&nbsp; | &nbsp;&nbsp;.&nbsp; |  &nbsp;&nbsp;1&nbsp; | &nbsp;&nbsp; Conduit diameter 40mmlength 300mm |
| &nbsp;&nbsp;.&nbsp; | &nbsp;&nbsp;.&nbsp; | &nbsp;&nbsp;.&nbsp; | &nbsp;&nbsp;.&nbsp; | &nbsp;&nbsp;.&nbsp; | &nbsp;&nbsp;.&nbsp; | &nbsp;&nbsp;1&nbsp; | &nbsp;&nbsp;.&nbsp; | &nbsp;&nbsp;.&nbsp; | &nbsp;&nbsp;.&nbsp; | &nbsp;&nbsp;.&nbsp; | &nbsp;&nbsp;.&nbsp; |  &nbsp;&nbsp;1&nbsp; | &nbsp;&nbsp; Heltec T144 |
| &nbsp;&nbsp;.&nbsp; | &nbsp;&nbsp;.&nbsp; | &nbsp;&nbsp;.&nbsp; | &nbsp;&nbsp;.&nbsp; | &nbsp;&nbsp;1&nbsp; | &nbsp;&nbsp;.&nbsp; | &nbsp;&nbsp;.&nbsp; | &nbsp;&nbsp;.&nbsp; | &nbsp;&nbsp;.&nbsp; | &nbsp;&nbsp;.&nbsp; | &nbsp;&nbsp;.&nbsp; | &nbsp;&nbsp;.&nbsp; |  &nbsp;&nbsp;1&nbsp; | &nbsp;&nbsp; Li-Ion/LiFePo4 32700 3.2v |
| &nbsp;&nbsp;.&nbsp; | &nbsp;&nbsp;.&nbsp; | &nbsp;&nbsp;.&nbsp; | &nbsp;&nbsp;.&nbsp; | &nbsp;&nbsp;1&nbsp; | &nbsp;&nbsp;.&nbsp; | &nbsp;&nbsp;.&nbsp; | &nbsp;&nbsp;.&nbsp; | &nbsp;&nbsp;.&nbsp; | &nbsp;&nbsp;.&nbsp; | &nbsp;&nbsp;.&nbsp; | &nbsp;&nbsp;.&nbsp; |  &nbsp;&nbsp;1&nbsp; | &nbsp;&nbsp; MPPT Solar Charge Controller |
| &nbsp;&nbsp;.&nbsp; | &nbsp;&nbsp;.&nbsp; | &nbsp;&nbsp;2&nbsp; | &nbsp;&nbsp;.&nbsp; | &nbsp;&nbsp;.&nbsp; | &nbsp;&nbsp;.&nbsp; | &nbsp;&nbsp;.&nbsp; | &nbsp;&nbsp;.&nbsp; | &nbsp;&nbsp;.&nbsp; | &nbsp;&nbsp;.&nbsp; | &nbsp;&nbsp;.&nbsp; | &nbsp;&nbsp;.&nbsp; |  &nbsp;&nbsp;2&nbsp; | &nbsp;&nbsp; Nut M3 x 2.4mm  |
| &nbsp;&nbsp;.&nbsp; | &nbsp;&nbsp;3&nbsp; | &nbsp;&nbsp;.&nbsp; | &nbsp;&nbsp;.&nbsp; | &nbsp;&nbsp;.&nbsp; | &nbsp;&nbsp;.&nbsp; | &nbsp;&nbsp;.&nbsp; | &nbsp;&nbsp;.&nbsp; | &nbsp;&nbsp;.&nbsp; | &nbsp;&nbsp;.&nbsp; | &nbsp;&nbsp;.&nbsp; | &nbsp;&nbsp;.&nbsp; |  &nbsp;&nbsp;3&nbsp; | &nbsp;&nbsp; Nut M4 x 3.2mm  |
| &nbsp;&nbsp;.&nbsp; | &nbsp;&nbsp;.&nbsp; | &nbsp;&nbsp;.&nbsp; | &nbsp;&nbsp;.&nbsp; | &nbsp;&nbsp;2&nbsp; | &nbsp;&nbsp;.&nbsp; | &nbsp;&nbsp;.&nbsp; | &nbsp;&nbsp;.&nbsp; | &nbsp;&nbsp;.&nbsp; | &nbsp;&nbsp;.&nbsp; | &nbsp;&nbsp;.&nbsp; | &nbsp;&nbsp;.&nbsp; |  &nbsp;&nbsp;2&nbsp; | &nbsp;&nbsp; Screw M3 pan x 10mm |
| &nbsp;&nbsp;.&nbsp; | &nbsp;&nbsp;3&nbsp; | &nbsp;&nbsp;.&nbsp; | &nbsp;&nbsp;.&nbsp; | &nbsp;&nbsp;.&nbsp; | &nbsp;&nbsp;.&nbsp; | &nbsp;&nbsp;.&nbsp; | &nbsp;&nbsp;.&nbsp; | &nbsp;&nbsp;.&nbsp; | &nbsp;&nbsp;.&nbsp; | &nbsp;&nbsp;.&nbsp; | &nbsp;&nbsp;.&nbsp; |  &nbsp;&nbsp;3&nbsp; | &nbsp;&nbsp; Screw M4 pan x 16mm |
| &nbsp;&nbsp;.&nbsp; | &nbsp;&nbsp;.&nbsp; | &nbsp;&nbsp;.&nbsp; | &nbsp;&nbsp;.&nbsp; | &nbsp;&nbsp;2&nbsp; | &nbsp;&nbsp;.&nbsp; | &nbsp;&nbsp;.&nbsp; | &nbsp;&nbsp;.&nbsp; | &nbsp;&nbsp;.&nbsp; | &nbsp;&nbsp;.&nbsp; | &nbsp;&nbsp;.&nbsp; | &nbsp;&nbsp;.&nbsp; |  &nbsp;&nbsp;2&nbsp; | &nbsp;&nbsp; Washer  M3 x 7mm x 0.5mm |
| &nbsp;&nbsp;.&nbsp; | &nbsp;&nbsp;3&nbsp; | &nbsp;&nbsp;.&nbsp; | &nbsp;&nbsp;.&nbsp; | &nbsp;&nbsp;.&nbsp; | &nbsp;&nbsp;.&nbsp; | &nbsp;&nbsp;.&nbsp; | &nbsp;&nbsp;.&nbsp; | &nbsp;&nbsp;.&nbsp; | &nbsp;&nbsp;.&nbsp; | &nbsp;&nbsp;.&nbsp; | &nbsp;&nbsp;.&nbsp; |  &nbsp;&nbsp;3&nbsp; | &nbsp;&nbsp; Washer  M4 x 9mm x 0.8mm |
| &nbsp;&nbsp;.&nbsp; | &nbsp;&nbsp;2&nbsp; | &nbsp;&nbsp;.&nbsp; | &nbsp;&nbsp;.&nbsp; | &nbsp;&nbsp;.&nbsp; | &nbsp;&nbsp;.&nbsp; | &nbsp;&nbsp;.&nbsp; | &nbsp;&nbsp;.&nbsp; | &nbsp;&nbsp;.&nbsp; | &nbsp;&nbsp;.&nbsp; | &nbsp;&nbsp;.&nbsp; | &nbsp;&nbsp;.&nbsp; |  &nbsp;&nbsp;2&nbsp; | &nbsp;&nbsp; Ziptie 3.6mm x 178mm min length |
| &nbsp;&nbsp;2&nbsp; | &nbsp;&nbsp;.&nbsp; | &nbsp;&nbsp;.&nbsp; | &nbsp;&nbsp;.&nbsp; | &nbsp;&nbsp;.&nbsp; | &nbsp;&nbsp;.&nbsp; | &nbsp;&nbsp;.&nbsp; | &nbsp;&nbsp;.&nbsp; | &nbsp;&nbsp;.&nbsp; | &nbsp;&nbsp;.&nbsp; | &nbsp;&nbsp;.&nbsp; | &nbsp;&nbsp;.&nbsp; |  &nbsp;&nbsp;2&nbsp; | &nbsp;&nbsp; Ziptie 3.6mm x 197mm min length |
| &nbsp;&nbsp;2&nbsp; | &nbsp;&nbsp;11&nbsp; | &nbsp;&nbsp;2&nbsp; | &nbsp;&nbsp;.&nbsp; | &nbsp;&nbsp;9&nbsp; | &nbsp;&nbsp;.&nbsp; | &nbsp;&nbsp;1&nbsp; | &nbsp;&nbsp;.&nbsp; | &nbsp;&nbsp;1&nbsp; | &nbsp;&nbsp;.&nbsp; | &nbsp;&nbsp;1&nbsp; | &nbsp;&nbsp;.&nbsp; | &nbsp;&nbsp;27&nbsp; | &nbsp;&nbsp;Total vitamins count |
|  |  |  |  |  |  |  |  |  |  |  |  | | **3D printed parts** |
| &nbsp;&nbsp;.&nbsp; | &nbsp;&nbsp;.&nbsp; | &nbsp;&nbsp;.&nbsp; | &nbsp;&nbsp;.&nbsp; | &nbsp;&nbsp;.&nbsp; | &nbsp;&nbsp;.&nbsp; | &nbsp;&nbsp;.&nbsp; | &nbsp;&nbsp;1&nbsp; | &nbsp;&nbsp;.&nbsp; | &nbsp;&nbsp;.&nbsp; | &nbsp;&nbsp;.&nbsp; | &nbsp;&nbsp;.&nbsp; |  &nbsp;&nbsp;1&nbsp; | &nbsp;&nbsp;SSNvD_antenna_part1.stl |
| &nbsp;&nbsp;.&nbsp; | &nbsp;&nbsp;.&nbsp; | &nbsp;&nbsp;.&nbsp; | &nbsp;&nbsp;.&nbsp; | &nbsp;&nbsp;.&nbsp; | &nbsp;&nbsp;.&nbsp; | &nbsp;&nbsp;.&nbsp; | &nbsp;&nbsp;1&nbsp; | &nbsp;&nbsp;.&nbsp; | &nbsp;&nbsp;.&nbsp; | &nbsp;&nbsp;.&nbsp; | &nbsp;&nbsp;.&nbsp; |  &nbsp;&nbsp;1&nbsp; | &nbsp;&nbsp;SSNvD_antenna_part2.stl |
| &nbsp;&nbsp;.&nbsp; | &nbsp;&nbsp;.&nbsp; | &nbsp;&nbsp;.&nbsp; | &nbsp;&nbsp;.&nbsp; | &nbsp;&nbsp;.&nbsp; | &nbsp;&nbsp;.&nbsp; | &nbsp;&nbsp;.&nbsp; | &nbsp;&nbsp;.&nbsp; | &nbsp;&nbsp;1&nbsp; | &nbsp;&nbsp;.&nbsp; | &nbsp;&nbsp;.&nbsp; | &nbsp;&nbsp;.&nbsp; |  &nbsp;&nbsp;1&nbsp; | &nbsp;&nbsp;SSNvD_antenna_top.stl |
| &nbsp;&nbsp;.&nbsp; | &nbsp;&nbsp;.&nbsp; | &nbsp;&nbsp;1&nbsp; | &nbsp;&nbsp;.&nbsp; | &nbsp;&nbsp;.&nbsp; | &nbsp;&nbsp;.&nbsp; | &nbsp;&nbsp;.&nbsp; | &nbsp;&nbsp;.&nbsp; | &nbsp;&nbsp;.&nbsp; | &nbsp;&nbsp;.&nbsp; | &nbsp;&nbsp;.&nbsp; | &nbsp;&nbsp;.&nbsp; |  &nbsp;&nbsp;1&nbsp; | &nbsp;&nbsp;SSNvD_battery_cable_clamp.stl |
| &nbsp;&nbsp;.&nbsp; | &nbsp;&nbsp;.&nbsp; | &nbsp;&nbsp;.&nbsp; | &nbsp;&nbsp;1&nbsp; | &nbsp;&nbsp;.&nbsp; | &nbsp;&nbsp;.&nbsp; | &nbsp;&nbsp;.&nbsp; | &nbsp;&nbsp;.&nbsp; | &nbsp;&nbsp;.&nbsp; | &nbsp;&nbsp;.&nbsp; | &nbsp;&nbsp;.&nbsp; | &nbsp;&nbsp;.&nbsp; |  &nbsp;&nbsp;1&nbsp; | &nbsp;&nbsp;SSNvD_battery_frame_part1.stl |
| &nbsp;&nbsp;.&nbsp; | &nbsp;&nbsp;.&nbsp; | &nbsp;&nbsp;.&nbsp; | &nbsp;&nbsp;1&nbsp; | &nbsp;&nbsp;.&nbsp; | &nbsp;&nbsp;.&nbsp; | &nbsp;&nbsp;.&nbsp; | &nbsp;&nbsp;.&nbsp; | &nbsp;&nbsp;.&nbsp; | &nbsp;&nbsp;.&nbsp; | &nbsp;&nbsp;.&nbsp; | &nbsp;&nbsp;.&nbsp; |  &nbsp;&nbsp;1&nbsp; | &nbsp;&nbsp;SSNvD_battery_frame_part2.stl |
| &nbsp;&nbsp;.&nbsp; | &nbsp;&nbsp;.&nbsp; | &nbsp;&nbsp;.&nbsp; | &nbsp;&nbsp;.&nbsp; | &nbsp;&nbsp;.&nbsp; | &nbsp;&nbsp;.&nbsp; | &nbsp;&nbsp;.&nbsp; | &nbsp;&nbsp;.&nbsp; | &nbsp;&nbsp;.&nbsp; | &nbsp;&nbsp;.&nbsp; | &nbsp;&nbsp;.&nbsp; | &nbsp;&nbsp;1&nbsp; |  &nbsp;&nbsp;1&nbsp; | &nbsp;&nbsp;SSNvD_end_cap.stl |
| &nbsp;&nbsp;.&nbsp; | &nbsp;&nbsp;.&nbsp; | &nbsp;&nbsp;.&nbsp; | &nbsp;&nbsp;.&nbsp; | &nbsp;&nbsp;.&nbsp; | &nbsp;&nbsp;.&nbsp; | &nbsp;&nbsp;.&nbsp; | &nbsp;&nbsp;.&nbsp; | &nbsp;&nbsp;.&nbsp; | &nbsp;&nbsp;.&nbsp; | &nbsp;&nbsp;1&nbsp; | &nbsp;&nbsp;.&nbsp; |  &nbsp;&nbsp;1&nbsp; | &nbsp;&nbsp;SSNvD_end_cap_ring.stl |
| &nbsp;&nbsp;.&nbsp; | &nbsp;&nbsp;.&nbsp; | &nbsp;&nbsp;.&nbsp; | &nbsp;&nbsp;.&nbsp; | &nbsp;&nbsp;.&nbsp; | &nbsp;&nbsp;1&nbsp; | &nbsp;&nbsp;.&nbsp; | &nbsp;&nbsp;.&nbsp; | &nbsp;&nbsp;.&nbsp; | &nbsp;&nbsp;.&nbsp; | &nbsp;&nbsp;.&nbsp; | &nbsp;&nbsp;.&nbsp; |  &nbsp;&nbsp;1&nbsp; | &nbsp;&nbsp;SSNvD_radio_frame_part1.stl |
| &nbsp;&nbsp;.&nbsp; | &nbsp;&nbsp;.&nbsp; | &nbsp;&nbsp;.&nbsp; | &nbsp;&nbsp;.&nbsp; | &nbsp;&nbsp;.&nbsp; | &nbsp;&nbsp;1&nbsp; | &nbsp;&nbsp;.&nbsp; | &nbsp;&nbsp;.&nbsp; | &nbsp;&nbsp;.&nbsp; | &nbsp;&nbsp;.&nbsp; | &nbsp;&nbsp;.&nbsp; | &nbsp;&nbsp;.&nbsp; |  &nbsp;&nbsp;1&nbsp; | &nbsp;&nbsp;SSNvD_radio_frame_part2.stl |
| &nbsp;&nbsp;.&nbsp; | &nbsp;&nbsp;1&nbsp; | &nbsp;&nbsp;.&nbsp; | &nbsp;&nbsp;.&nbsp; | &nbsp;&nbsp;.&nbsp; | &nbsp;&nbsp;.&nbsp; | &nbsp;&nbsp;.&nbsp; | &nbsp;&nbsp;.&nbsp; | &nbsp;&nbsp;.&nbsp; | &nbsp;&nbsp;.&nbsp; | &nbsp;&nbsp;.&nbsp; | &nbsp;&nbsp;.&nbsp; |  &nbsp;&nbsp;1&nbsp; | &nbsp;&nbsp;SSNvD_solar_mount.stl |
| &nbsp;&nbsp;2&nbsp; | &nbsp;&nbsp;.&nbsp; | &nbsp;&nbsp;.&nbsp; | &nbsp;&nbsp;.&nbsp; | &nbsp;&nbsp;.&nbsp; | &nbsp;&nbsp;.&nbsp; | &nbsp;&nbsp;.&nbsp; | &nbsp;&nbsp;.&nbsp; | &nbsp;&nbsp;.&nbsp; | &nbsp;&nbsp;.&nbsp; | &nbsp;&nbsp;.&nbsp; | &nbsp;&nbsp;.&nbsp; |  &nbsp;&nbsp;2&nbsp; | &nbsp;&nbsp;SSNvD_spacer.stl |
| &nbsp;&nbsp;2&nbsp; | &nbsp;&nbsp;1&nbsp; | &nbsp;&nbsp;1&nbsp; | &nbsp;&nbsp;2&nbsp; | &nbsp;&nbsp;.&nbsp; | &nbsp;&nbsp;2&nbsp; | &nbsp;&nbsp;.&nbsp; | &nbsp;&nbsp;2&nbsp; | &nbsp;&nbsp;1&nbsp; | &nbsp;&nbsp;.&nbsp; | &nbsp;&nbsp;1&nbsp; | &nbsp;&nbsp;1&nbsp; | &nbsp;&nbsp;13&nbsp; | &nbsp;&nbsp;Total 3D printed parts count |

<span></span>
[Top](#TOP)

---

## 2 x SSNvD Spacer Assembly
### Vitamins
|Qty|Description|
|---:|:---|
|2| Ziptie 3.6mm x 197mm min length|

### 3D Printed parts

| 2 x [SSNvD_spacer.stl](stls/SSNvD_spacer.stl) |
|---|
| SSNvD_spacer.stl 

### Assembly instructions
SSNvD_spacer_assembly

1. Insert spacer when mounting the router with zipties

SSNvD_spacer_assembled

<span></span>
[Top](#TOP)

---

## SSNvD Solar Mount Assembly
### Vitamins
|Qty|Description|
|---:|:---|
|3| Nut M4 x 3.2mm |
|3| Screw M4 pan x 16mm|
|3| Washer  M4 x 9mm x 0.8mm|
|2| Ziptie 3.6mm x 178mm min length|

### 3D Printed parts

| 1 x [SSNvD_solar_mount.stl](stls/SSNvD_solar_mount.stl) |
|---|
| SSNvD_solar_mount.stl 

### Assembly instructions
SSNvD_solar_mount_assembly

1. Inset M4 nuts
2. Attach solar penel
3. Insert zipties

SSNvD_solar_mount_assembled

<span></span>
[Top](#TOP)

---

## SSNvD Battery Cable Clamp Assembly
### Vitamins
|Qty|Description|
|---:|:---|
|2| Nut M3 x 2.4mm |

### 3D Printed parts

| 1 x [SSNvD_battery_cable_clamp.stl](stls/SSNvD_battery_cable_clamp.stl) |
|---|
| SSNvD_battery_cable_clamp.stl 

### Assembly instructions
SSNvD_battery_cable_clamp_assembly

Insert two M3 waschers into the cable clamp

SSNvD_battery_cable_clamp_assembled

<span></span>
[Top](#TOP)

---

## SSNvD Battery Frame Assembly
### 3D Printed parts

| 1 x [SSNvD_battery_frame_part1.stl](stls/SSNvD_battery_frame_part1.stl) | 1 x [SSNvD_battery_frame_part2.stl](stls/SSNvD_battery_frame_part2.stl) |
|---|---|
| SSNvD_battery_frame_part1.stl | SSNvD_battery_frame_part2.stl 

### Assembly instructions
SSNvD_battery_frame_assembly

Glue the two pieces of the frame together

SSNvD_battery_frame_assembled

<span></span>
[Top](#TOP)

---

## SSNvD Battery Assembly
### Vitamins
|Qty|Description|
|---:|:---|
|1| 1S 3.2V battery protection board|
|1| Battery negative contact|
|1| Battery positive contact|
|1| Li-Ion/LiFePo4 32700 3.2v|
|1| MPPT Solar Charge Controller|
|2| Screw M3 pan x 10mm|
|2| Washer  M3 x 7mm x 0.5mm|

### Sub-assemblies

| 1 x SSNvD_battery_cable_clamp_assembly | 1 x SSNvD_battery_frame_assembly |
|---|---|
| SSNvD_battery_cable_clamp_assembled | SSNvD_battery_frame_assembled 

### Assembly instructions
SSNvD_battery_assembly

Solder and assemble components

SSNvD_battery_assembled

<span></span>
[Top](#TOP)

---

## SSNvD Radio Frame Assembly
### 3D Printed parts

| 1 x [SSNvD_radio_frame_part1.stl](stls/SSNvD_radio_frame_part1.stl) | 1 x [SSNvD_radio_frame_part2.stl](stls/SSNvD_radio_frame_part2.stl) |
|---|---|
| SSNvD_radio_frame_part1.stl | SSNvD_radio_frame_part2.stl 

### Assembly instructions
SSNvD_radio_frame_assembly

1. Glue the two parts of the radio frame together

SSNvD_radio_frame_assembled

<span></span>
[Top](#TOP)

---

## SSNvD Radio Assembly
### Vitamins
|Qty|Description|
|---:|:---|
|1| Heltec T144|

### Sub-assemblies

| 1 x SSNvD_radio_frame_assembly |
|---|
| SSNvD_radio_frame_assembled 

### Assembly instructions
SSNvD_radio_assembly

1. Attach the cable clamp with two M3 screws
2. Insert the Heltec T114
3. Attach the power cable
4. Tighten cable clamp

SSNvD_radio_assembled

<span></span>
[Top](#TOP)

---

## SSNvD Antenna Frame Assembly
### 3D Printed parts

| 1 x [SSNvD_antenna_part1.stl](stls/SSNvD_antenna_part1.stl) | 1 x [SSNvD_antenna_part2.stl](stls/SSNvD_antenna_part2.stl) |
|---|---|
| SSNvD_antenna_part1.stl | SSNvD_antenna_part2.stl 

### Assembly instructions
SSNvD_antenna_frame_assembly

1. Glue the two parts of the antenna frame together

SSNvD_antenna_frame_assembled

<span></span>
[Top](#TOP)

---

## SSNvD Antenna Assembly
### Vitamins
|Qty|Description|
|---:|:---|
|1| Antenna with N-connector|

### 3D Printed parts

| 1 x [SSNvD_antenna_top.stl](stls/SSNvD_antenna_top.stl) |
|---|
| SSNvD_antenna_top.stl 

### Sub-assemblies

| 1 x SSNvD_antenna_frame_assembly |
|---|
| SSNvD_antenna_frame_assembled 

### Assembly instructions
SSNvD_antenna_assembly

1. Attach the antenna to the frame.  
2. Wrap teflon tape around the bottom of the antenna rod.  
3. Push the top cover over the antenna.  

SSNvD_antenna_assembled

<span></span>
[Top](#TOP)

---

## SSNvD Top Assembly
### Sub-assemblies

| 1 x SSNvD_antenna_assembly | 1 x SSNvD_battery_assembly | 1 x SSNvD_radio_assembly |
|---|---|---|
| SSNvD_antenna_assembled | SSNvD_battery_assembled | SSNvD_radio_assembled 

### Assembly instructions
SSNvD_top_assembly

SSNvD_top_assembled

<span></span>
[Top](#TOP)

---

## SSNvD Pole Assembly
### Vitamins
|Qty|Description|
|---:|:---|
|1| Conduit diameter 40mmlength 300mm|

### 3D Printed parts

| 1 x [SSNvD_end_cap_ring.stl](stls/SSNvD_end_cap_ring.stl) |
|---|
| SSNvD_end_cap_ring.stl 

### Assembly instructions
SSNvD_pole_assembly

1. Cut the M40 counduit to the desired length (mun. 30cm)
2. Glue the end cap ring into the bottom of the conduit 

SSNvD_pole_assembled

<span></span>
[Top](#TOP)

---

## SSNvD Assembly
### 3D Printed parts

| 1 x [SSNvD_end_cap.stl](stls/SSNvD_end_cap.stl) |
|---|
| SSNvD_end_cap.stl 

### Sub-assemblies

| 1 x SSNvD_pole_assembly | 1 x SSNvD_solar_mount_assembly | 2 x SSNvD_spacer_assembly |
|---|---|---|
| SSNvD_pole_assembled | SSNvD_solar_mount_assembled | SSNvD_spacer_assembled 

| 1 x SSNvD_top_assembly |
|---|
| SSNvD_top_assembled 

### Assembly instructions
SSNvD_assembly

1. Slide the antenna and radio into the top end of the pole
2. Attach the power cable of the antenna to the battery assembly
3. Slide the battery assembly into the bottom end of the pole
4. Attach the solar panel to the MPPT controller
5. Attach the panel to the panel mount
6. Attach the panel mount to the pole with zipties

SSNvD_assembled

<span></span>
[Top](#TOP)

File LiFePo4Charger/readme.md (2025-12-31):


# LoRaMeshNodes
Main Assembly

<span></span>

---
## Table of Contents
1. [Parts list](#Parts_list)
1. [LiFePo4Charger Assembly](#LiFePo4Charger_assembly)

<span></span>
[Top](#TOP)

---

## Parts list
| <span style="writing-mode: vertical-rl; text-orientation: mixed;">LiFePo4Charger</span> | <span style="writing-mode: vertical-rl; text-orientation: mixed;">TOTALS</span> |  |
|---:|---:|:---|
|  | | **Vitamins** |
| &nbsp;&nbsp;1&nbsp; |  &nbsp;&nbsp;1&nbsp; | &nbsp;&nbsp; Battery negative contact |
| &nbsp;&nbsp;1&nbsp; |  &nbsp;&nbsp;1&nbsp; | &nbsp;&nbsp; Battery positive contact |
| &nbsp;&nbsp;1&nbsp; |  &nbsp;&nbsp;1&nbsp; | &nbsp;&nbsp; Li-Ion/LiFePo4 32700 3.2v |
| &nbsp;&nbsp;1&nbsp; |  &nbsp;&nbsp;1&nbsp; | &nbsp;&nbsp; LiFePo4 USB Charger |
| &nbsp;&nbsp;2&nbsp; |  &nbsp;&nbsp;2&nbsp; | &nbsp;&nbsp; Nut M3 x 2.4mm  |
| &nbsp;&nbsp;2&nbsp; |  &nbsp;&nbsp;2&nbsp; | &nbsp;&nbsp; Screw M3 dome x 20mm |
| &nbsp;&nbsp;8&nbsp; | &nbsp;&nbsp;8&nbsp; | &nbsp;&nbsp;Total vitamins count |
|  | | **3D printed parts** |
| &nbsp;&nbsp;1&nbsp; |  &nbsp;&nbsp;1&nbsp; | &nbsp;&nbsp;LiFePoCharger_frame_part1.stl |
| &nbsp;&nbsp;1&nbsp; |  &nbsp;&nbsp;1&nbsp; | &nbsp;&nbsp;LiFePoCharger_frame_part2.stl |
| &nbsp;&nbsp;2&nbsp; | &nbsp;&nbsp;2&nbsp; | &nbsp;&nbsp;Total 3D printed parts count |

<span></span>
[Top](#TOP)

---

## LiFePo4Charger Assembly
### Vitamins
|Qty|Description|
|---:|:---|
|1| Battery negative contact|
|1| Battery positive contact|
|1| Li-Ion/LiFePo4 32700 3.2v|
|1| LiFePo4 USB Charger|
|2| Nut M3 x 2.4mm |
|2| Screw M3 dome x 20mm|

### 3D Printed parts

| 1 x [LiFePoCharger_frame_part1.stl](stls/LiFePoCharger_frame_part1.stl) | 1 x [LiFePoCharger_frame_part2.stl](stls/LiFePoCharger_frame_part2.stl) |
|---|---|
| LiFePoCharger_frame_part1.stl | LiFePoCharger_frame_part2.stl 

### Assembly instructions
LiFePo4Charger_assembly

Assemble as shown

LiFePo4Charger_assembled

<span></span>
[Top](#TOP)

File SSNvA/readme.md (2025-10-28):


# LoRaMeshNodes
Main Assembly

<span></span>

---
## Table of Contents
1. [Parts list](#Parts_list)
1. [SSNvA Solar Mount Assembly](#SSNvA_solar_mount_assembly)
1. [SSNvA Battery Cable Clamp Assembly](#SSNvA_battery_cable_clamp_assembly)
1. [SSNvA Battery Frame Assembly](#SSNvA_battery_frame_assembly)
1. [SSNvA Battery Assembly](#SSNvA_battery_assembly)
1. [SSNvA Radio Frame Assembly](#SSNvA_radio_frame_assembly)
1. [SSNvA Radio Assembly](#SSNvA_radio_assembly)
1. [SSNvA Antenna Frame Assembly](#SSNvA_antenna_frame_assembly)
1. [SSNvA Antenna Assembly](#SSNvA_antenna_assembly)
1. [SSNvA Top Assembly](#SSNvA_top_assembly)
1. [SSNvA Pole Assembly](#SSNvA_pole_assembly)
1. [SSNvA Assembly](#SSNvA_assembly)

<span></span>
[Top](#TOP)

---

## Parts list
| <span style="writing-mode: vertical-rl; text-orientation: mixed;">SSNvA&nbsp;Solar&nbsp;Mount</span> | <span style="writing-mode: vertical-rl; text-orientation: mixed;">2 x SSNvA&nbsp;Battery&nbsp;Cable&nbsp;Clamp</span> | <span style="writing-mode: vertical-rl; text-orientation: mixed;">SSNvA&nbsp;Battery&nbsp;Frame</span> | <span style="writing-mode: vertical-rl; text-orientation: mixed;">SSNvA&nbsp;Battery</span> | <span style="writing-mode: vertical-rl; text-orientation: mixed;">SSNvA&nbsp;Radio&nbsp;Frame</span> | <span style="writing-mode: vertical-rl; text-orientation: mixed;">SSNvA&nbsp;Radio</span> | <span style="writing-mode: vertical-rl; text-orientation: mixed;">SSNvA&nbsp;Antenna&nbsp;Frame</span> | <span style="writing-mode: vertical-rl; text-orientation: mixed;">SSNvA&nbsp;Antenna</span> | <span style="writing-mode: vertical-rl; text-orientation: mixed;">SSNvA&nbsp;Top</span> | <span style="writing-mode: vertical-rl; text-orientation: mixed;">SSNvA&nbsp;Pole</span> | <span style="writing-mode: vertical-rl; text-orientation: mixed;">SSNvA</span> | <span style="writing-mode: vertical-rl; text-orientation: mixed;">TOTALS</span> |  |
|---:|---:|---:|---:|---:|---:|---:|---:|---:|---:|---:|---:|:---|
|  |  |  |  |  |  |  |  |  |  |  | | **Vitamins** |
| &nbsp;&nbsp;.&nbsp; | &nbsp;&nbsp;.&nbsp; | &nbsp;&nbsp;.&nbsp; | &nbsp;&nbsp;1&nbsp; | &nbsp;&nbsp;.&nbsp; | &nbsp;&nbsp;.&nbsp; | &nbsp;&nbsp;.&nbsp; | &nbsp;&nbsp;.&nbsp; | &nbsp;&nbsp;.&nbsp; | &nbsp;&nbsp;.&nbsp; | &nbsp;&nbsp;.&nbsp; |  &nbsp;&nbsp;1&nbsp; | &nbsp;&nbsp; 1S 3.2V battery protection board |
| &nbsp;&nbsp;.&nbsp; | &nbsp;&nbsp;.&nbsp; | &nbsp;&nbsp;.&nbsp; | &nbsp;&nbsp;.&nbsp; | &nbsp;&nbsp;.&nbsp; | &nbsp;&nbsp;.&nbsp; | &nbsp;&nbsp;.&nbsp; | &nbsp;&nbsp;1&nbsp; | &nbsp;&nbsp;.&nbsp; | &nbsp;&nbsp;.&nbsp; | &nbsp;&nbsp;.&nbsp; |  &nbsp;&nbsp;1&nbsp; | &nbsp;&nbsp; Antenna with N-connector |
| &nbsp;&nbsp;.&nbsp; | &nbsp;&nbsp;.&nbsp; | &nbsp;&nbsp;.&nbsp; | &nbsp;&nbsp;1&nbsp; | &nbsp;&nbsp;.&nbsp; | &nbsp;&nbsp;.&nbsp; | &nbsp;&nbsp;.&nbsp; | &nbsp;&nbsp;.&nbsp; | &nbsp;&nbsp;.&nbsp; | &nbsp;&nbsp;.&nbsp; | &nbsp;&nbsp;.&nbsp; |  &nbsp;&nbsp;1&nbsp; | &nbsp;&nbsp; Battery negative contact |
| &nbsp;&nbsp;.&nbsp; | &nbsp;&nbsp;.&nbsp; | &nbsp;&nbsp;.&nbsp; | &nbsp;&nbsp;1&nbsp; | &nbsp;&nbsp;.&nbsp; | &nbsp;&nbsp;.&nbsp; | &nbsp;&nbsp;.&nbsp; | &nbsp;&nbsp;.&nbsp; | &nbsp;&nbsp;.&nbsp; | &nbsp;&nbsp;.&nbsp; | &nbsp;&nbsp;.&nbsp; |  &nbsp;&nbsp;1&nbsp; | &nbsp;&nbsp; Battery positive contact |
| &nbsp;&nbsp;.&nbsp; | &nbsp;&nbsp;.&nbsp; | &nbsp;&nbsp;.&nbsp; | &nbsp;&nbsp;.&nbsp; | &nbsp;&nbsp;.&nbsp; | &nbsp;&nbsp;.&nbsp; | &nbsp;&nbsp;.&nbsp; | &nbsp;&nbsp;.&nbsp; | &nbsp;&nbsp;.&nbsp; | &nbsp;&nbsp;1&nbsp; | &nbsp;&nbsp;.&nbsp; |  &nbsp;&nbsp;1&nbsp; | &nbsp;&nbsp; Conduit diameter 40mmlength 2000mm |
| &nbsp;&nbsp;.&nbsp; | &nbsp;&nbsp;.&nbsp; | &nbsp;&nbsp;.&nbsp; | &nbsp;&nbsp;.&nbsp; | &nbsp;&nbsp;.&nbsp; | &nbsp;&nbsp;1&nbsp; | &nbsp;&nbsp;.&nbsp; | &nbsp;&nbsp;.&nbsp; | &nbsp;&nbsp;.&nbsp; | &nbsp;&nbsp;.&nbsp; | &nbsp;&nbsp;.&nbsp; |  &nbsp;&nbsp;1&nbsp; | &nbsp;&nbsp; Heltec T144 |
| &nbsp;&nbsp;.&nbsp; | &nbsp;&nbsp;.&nbsp; | &nbsp;&nbsp;.&nbsp; | &nbsp;&nbsp;1&nbsp; | &nbsp;&nbsp;.&nbsp; | &nbsp;&nbsp;.&nbsp; | &nbsp;&nbsp;.&nbsp; | &nbsp;&nbsp;.&nbsp; | &nbsp;&nbsp;.&nbsp; | &nbsp;&nbsp;.&nbsp; | &nbsp;&nbsp;.&nbsp; |  &nbsp;&nbsp;1&nbsp; | &nbsp;&nbsp; Li-Ion/LiFePo4 32700 3.2v |
| &nbsp;&nbsp;.&nbsp; | &nbsp;&nbsp;.&nbsp; | &nbsp;&nbsp;.&nbsp; | &nbsp;&nbsp;1&nbsp; | &nbsp;&nbsp;.&nbsp; | &nbsp;&nbsp;.&nbsp; | &nbsp;&nbsp;.&nbsp; | &nbsp;&nbsp;.&nbsp; | &nbsp;&nbsp;.&nbsp; | &nbsp;&nbsp;.&nbsp; | &nbsp;&nbsp;.&nbsp; |  &nbsp;&nbsp;1&nbsp; | &nbsp;&nbsp; MPPT Solar Charge Controller |
| &nbsp;&nbsp;.&nbsp; | &nbsp;&nbsp;4&nbsp; | &nbsp;&nbsp;.&nbsp; | &nbsp;&nbsp;.&nbsp; | &nbsp;&nbsp;.&nbsp; | &nbsp;&nbsp;2&nbsp; | &nbsp;&nbsp;.&nbsp; | &nbsp;&nbsp;.&nbsp; | &nbsp;&nbsp;.&nbsp; | &nbsp;&nbsp;.&nbsp; | &nbsp;&nbsp;.&nbsp; |  &nbsp;&nbsp;6&nbsp; | &nbsp;&nbsp; Nut M3 x 2.4mm  |
| &nbsp;&nbsp;3&nbsp; | &nbsp;&nbsp;.&nbsp; | &nbsp;&nbsp;.&nbsp; | &nbsp;&nbsp;.&nbsp; | &nbsp;&nbsp;.&nbsp; | &nbsp;&nbsp;.&nbsp; | &nbsp;&nbsp;.&nbsp; | &nbsp;&nbsp;.&nbsp; | &nbsp;&nbsp;.&nbsp; | &nbsp;&nbsp;.&nbsp; | &nbsp;&nbsp;.&nbsp; |  &nbsp;&nbsp;3&nbsp; | &nbsp;&nbsp; Nut M4 x 3.2mm  |
| &nbsp;&nbsp;.&nbsp; | &nbsp;&nbsp;.&nbsp; | &nbsp;&nbsp;.&nbsp; | &nbsp;&nbsp;1&nbsp; | &nbsp;&nbsp;.&nbsp; | &nbsp;&nbsp;.&nbsp; | &nbsp;&nbsp;.&nbsp; | &nbsp;&nbsp;.&nbsp; | &nbsp;&nbsp;.&nbsp; | &nbsp;&nbsp;.&nbsp; | &nbsp;&nbsp;.&nbsp; |  &nbsp;&nbsp;1&nbsp; | &nbsp;&nbsp; Nut M6 x 5mm  |
| &nbsp;&nbsp;.&nbsp; | &nbsp;&nbsp;.&nbsp; | &nbsp;&nbsp;.&nbsp; | &nbsp;&nbsp;2&nbsp; | &nbsp;&nbsp;.&nbsp; | &nbsp;&nbsp;.&nbsp; | &nbsp;&nbsp;.&nbsp; | &nbsp;&nbsp;.&nbsp; | &nbsp;&nbsp;.&nbsp; | &nbsp;&nbsp;.&nbsp; | &nbsp;&nbsp;.&nbsp; |  &nbsp;&nbsp;2&nbsp; | &nbsp;&nbsp; Screw M3 pan x 12mm |
| &nbsp;&nbsp;.&nbsp; | &nbsp;&nbsp;.&nbsp; | &nbsp;&nbsp;.&nbsp; | &nbsp;&nbsp;.&nbsp; | &nbsp;&nbsp;.&nbsp; | &nbsp;&nbsp;2&nbsp; | &nbsp;&nbsp;.&nbsp; | &nbsp;&nbsp;.&nbsp; | &nbsp;&nbsp;.&nbsp; | &nbsp;&nbsp;.&nbsp; | &nbsp;&nbsp;.&nbsp; |  &nbsp;&nbsp;2&nbsp; | &nbsp;&nbsp; Screw M3 pan x 16mm |
| &nbsp;&nbsp;.&nbsp; | &nbsp;&nbsp;.&nbsp; | &nbsp;&nbsp;.&nbsp; | &nbsp;&nbsp;2&nbsp; | &nbsp;&nbsp;.&nbsp; | &nbsp;&nbsp;.&nbsp; | &nbsp;&nbsp;.&nbsp; | &nbsp;&nbsp;.&nbsp; | &nbsp;&nbsp;.&nbsp; | &nbsp;&nbsp;.&nbsp; | &nbsp;&nbsp;.&nbsp; |  &nbsp;&nbsp;2&nbsp; | &nbsp;&nbsp; Screw M3 pan x 18mm |
| &nbsp;&nbsp;3&nbsp; | &nbsp;&nbsp;.&nbsp; | &nbsp;&nbsp;.&nbsp; | &nbsp;&nbsp;.&nbsp; | &nbsp;&nbsp;.&nbsp; | &nbsp;&nbsp;.&nbsp; | &nbsp;&nbsp;.&nbsp; | &nbsp;&nbsp;.&nbsp; | &nbsp;&nbsp;.&nbsp; | &nbsp;&nbsp;.&nbsp; | &nbsp;&nbsp;.&nbsp; |  &nbsp;&nbsp;3&nbsp; | &nbsp;&nbsp; Screw M4 pan x 16mm |
| &nbsp;&nbsp;.&nbsp; | &nbsp;&nbsp;.&nbsp; | &nbsp;&nbsp;.&nbsp; | &nbsp;&nbsp;1&nbsp; | &nbsp;&nbsp;.&nbsp; | &nbsp;&nbsp;.&nbsp; | &nbsp;&nbsp;.&nbsp; | &nbsp;&nbsp;.&nbsp; | &nbsp;&nbsp;.&nbsp; | &nbsp;&nbsp;.&nbsp; | &nbsp;&nbsp;.&nbsp; |  &nbsp;&nbsp;1&nbsp; | &nbsp;&nbsp; Screw M6 hex x 50mm |
| &nbsp;&nbsp;.&nbsp; | &nbsp;&nbsp;.&nbsp; | &nbsp;&nbsp;.&nbsp; | &nbsp;&nbsp;4&nbsp; | &nbsp;&nbsp;.&nbsp; | &nbsp;&nbsp;2&nbsp; | &nbsp;&nbsp;.&nbsp; | &nbsp;&nbsp;.&nbsp; | &nbsp;&nbsp;.&nbsp; | &nbsp;&nbsp;.&nbsp; | &nbsp;&nbsp;.&nbsp; |  &nbsp;&nbsp;6&nbsp; | &nbsp;&nbsp; Washer  M3 x 7mm x 0.5mm |
| &nbsp;&nbsp;3&nbsp; | &nbsp;&nbsp;.&nbsp; | &nbsp;&nbsp;.&nbsp; | &nbsp;&nbsp;.&nbsp; | &nbsp;&nbsp;.&nbsp; | &nbsp;&nbsp;.&nbsp; | &nbsp;&nbsp;.&nbsp; | &nbsp;&nbsp;.&nbsp; | &nbsp;&nbsp;.&nbsp; | &nbsp;&nbsp;.&nbsp; | &nbsp;&nbsp;.&nbsp; |  &nbsp;&nbsp;3&nbsp; | &nbsp;&nbsp; Washer  M4 x 9mm x 0.8mm |
| &nbsp;&nbsp;2&nbsp; | &nbsp;&nbsp;.&nbsp; | &nbsp;&nbsp;.&nbsp; | &nbsp;&nbsp;.&nbsp; | &nbsp;&nbsp;.&nbsp; | &nbsp;&nbsp;.&nbsp; | &nbsp;&nbsp;.&nbsp; | &nbsp;&nbsp;.&nbsp; | &nbsp;&nbsp;.&nbsp; | &nbsp;&nbsp;.&nbsp; | &nbsp;&nbsp;.&nbsp; |  &nbsp;&nbsp;2&nbsp; | &nbsp;&nbsp; Ziptie 3.6mm x 178mm min length |
| &nbsp;&nbsp;11&nbsp; | &nbsp;&nbsp;4&nbsp; | &nbsp;&nbsp;.&nbsp; | &nbsp;&nbsp;15&nbsp; | &nbsp;&nbsp;.&nbsp; | &nbsp;&nbsp;7&nbsp; | &nbsp;&nbsp;.&nbsp; | &nbsp;&nbsp;1&nbsp; | &nbsp;&nbsp;.&nbsp; | &nbsp;&nbsp;1&nbsp; | &nbsp;&nbsp;.&nbsp; | &nbsp;&nbsp;39&nbsp; | &nbsp;&nbsp;Total vitamins count |
|  |  |  |  |  |  |  |  |  |  |  | | **3D printed parts** |
| &nbsp;&nbsp;.&nbsp; | &nbsp;&nbsp;.&nbsp; | &nbsp;&nbsp;.&nbsp; | &nbsp;&nbsp;.&nbsp; | &nbsp;&nbsp;.&nbsp; | &nbsp;&nbsp;.&nbsp; | &nbsp;&nbsp;1&nbsp; | &nbsp;&nbsp;.&nbsp; | &nbsp;&nbsp;.&nbsp; | &nbsp;&nbsp;.&nbsp; | &nbsp;&nbsp;.&nbsp; |  &nbsp;&nbsp;1&nbsp; | &nbsp;&nbsp;SSNvA_antenna_part1.stl |
| &nbsp;&nbsp;.&nbsp; | &nbsp;&nbsp;.&nbsp; | &nbsp;&nbsp;.&nbsp; | &nbsp;&nbsp;.&nbsp; | &nbsp;&nbsp;.&nbsp; | &nbsp;&nbsp;.&nbsp; | &nbsp;&nbsp;1&nbsp; | &nbsp;&nbsp;.&nbsp; | &nbsp;&nbsp;.&nbsp; | &nbsp;&nbsp;.&nbsp; | &nbsp;&nbsp;.&nbsp; |  &nbsp;&nbsp;1&nbsp; | &nbsp;&nbsp;SSNvA_antenna_part2.stl |
| &nbsp;&nbsp;.&nbsp; | &nbsp;&nbsp;.&nbsp; | &nbsp;&nbsp;.&nbsp; | &nbsp;&nbsp;.&nbsp; | &nbsp;&nbsp;.&nbsp; | &nbsp;&nbsp;.&nbsp; | &nbsp;&nbsp;.&nbsp; | &nbsp;&nbsp;1&nbsp; | &nbsp;&nbsp;.&nbsp; | &nbsp;&nbsp;.&nbsp; | &nbsp;&nbsp;.&nbsp; |  &nbsp;&nbsp;1&nbsp; | &nbsp;&nbsp;SSNvA_antenna_top.stl |
| &nbsp;&nbsp;.&nbsp; | &nbsp;&nbsp;2&nbsp; | &nbsp;&nbsp;.&nbsp; | &nbsp;&nbsp;.&nbsp; | &nbsp;&nbsp;.&nbsp; | &nbsp;&nbsp;.&nbsp; | &nbsp;&nbsp;.&nbsp; | &nbsp;&nbsp;.&nbsp; | &nbsp;&nbsp;.&nbsp; | &nbsp;&nbsp;.&nbsp; | &nbsp;&nbsp;.&nbsp; |  &nbsp;&nbsp;2&nbsp; | &nbsp;&nbsp;SSNvA_battery_cable_clamp.stl |
| &nbsp;&nbsp;.&nbsp; | &nbsp;&nbsp;.&nbsp; | &nbsp;&nbsp;1&nbsp; | &nbsp;&nbsp;.&nbsp; | &nbsp;&nbsp;.&nbsp; | &nbsp;&nbsp;.&nbsp; | &nbsp;&nbsp;.&nbsp; | &nbsp;&nbsp;.&nbsp; | &nbsp;&nbsp;.&nbsp; | &nbsp;&nbsp;.&nbsp; | &nbsp;&nbsp;.&nbsp; |  &nbsp;&nbsp;1&nbsp; | &nbsp;&nbsp;SSNvA_battery_frame_part1.stl |
| &nbsp;&nbsp;.&nbsp; | &nbsp;&nbsp;.&nbsp; | &nbsp;&nbsp;1&nbsp; | &nbsp;&nbsp;.&nbsp; | &nbsp;&nbsp;.&nbsp; | &nbsp;&nbsp;.&nbsp; | &nbsp;&nbsp;.&nbsp; | &nbsp;&nbsp;.&nbsp; | &nbsp;&nbsp;.&nbsp; | &nbsp;&nbsp;.&nbsp; | &nbsp;&nbsp;.&nbsp; |  &nbsp;&nbsp;1&nbsp; | &nbsp;&nbsp;SSNvA_battery_frame_part2.stl |
| &nbsp;&nbsp;.&nbsp; | &nbsp;&nbsp;.&nbsp; | &nbsp;&nbsp;.&nbsp; | &nbsp;&nbsp;2&nbsp; | &nbsp;&nbsp;.&nbsp; | &nbsp;&nbsp;.&nbsp; | &nbsp;&nbsp;.&nbsp; | &nbsp;&nbsp;.&nbsp; | &nbsp;&nbsp;.&nbsp; | &nbsp;&nbsp;.&nbsp; | &nbsp;&nbsp;.&nbsp; |  &nbsp;&nbsp;2&nbsp; | &nbsp;&nbsp;SSNvA_battery_screw_handle.stl |
| &nbsp;&nbsp;.&nbsp; | &nbsp;&nbsp;.&nbsp; | &nbsp;&nbsp;.&nbsp; | &nbsp;&nbsp;.&nbsp; | &nbsp;&nbsp;.&nbsp; | &nbsp;&nbsp;1&nbsp; | &nbsp;&nbsp;.&nbsp; | &nbsp;&nbsp;.&nbsp; | &nbsp;&nbsp;.&nbsp; | &nbsp;&nbsp;.&nbsp; | &nbsp;&nbsp;.&nbsp; |  &nbsp;&nbsp;1&nbsp; | &nbsp;&nbsp;SSNvA_cable_clamp.stl |
| &nbsp;&nbsp;.&nbsp; | &nbsp;&nbsp;.&nbsp; | &nbsp;&nbsp;.&nbsp; | &nbsp;&nbsp;.&nbsp; | &nbsp;&nbsp;1&nbsp; | &nbsp;&nbsp;.&nbsp; | &nbsp;&nbsp;.&nbsp; | &nbsp;&nbsp;.&nbsp; | &nbsp;&nbsp;.&nbsp; | &nbsp;&nbsp;.&nbsp; | &nbsp;&nbsp;.&nbsp; |  &nbsp;&nbsp;1&nbsp; | &nbsp;&nbsp;SSNvA_radio_frame_part1.stl |
| &nbsp;&nbsp;.&nbsp; | &nbsp;&nbsp;.&nbsp; | &nbsp;&nbsp;.&nbsp; | &nbsp;&nbsp;.&nbsp; | &nbsp;&nbsp;1&nbsp; | &nbsp;&nbsp;.&nbsp; | &nbsp;&nbsp;.&nbsp; | &nbsp;&nbsp;.&nbsp; | &nbsp;&nbsp;.&nbsp; | &nbsp;&nbsp;.&nbsp; | &nbsp;&nbsp;.&nbsp; |  &nbsp;&nbsp;1&nbsp; | &nbsp;&nbsp;SSNvA_radio_frame_part2.stl |
| &nbsp;&nbsp;.&nbsp; | &nbsp;&nbsp;.&nbsp; | &nbsp;&nbsp;.&nbsp; | &nbsp;&nbsp;.&nbsp; | &nbsp;&nbsp;.&nbsp; | &nbsp;&nbsp;.&nbsp; | &nbsp;&nbsp;.&nbsp; | &nbsp;&nbsp;.&nbsp; | &nbsp;&nbsp;.&nbsp; | &nbsp;&nbsp;2&nbsp; | &nbsp;&nbsp;.&nbsp; |  &nbsp;&nbsp;2&nbsp; | &nbsp;&nbsp;SSNvA_scrutonM40.stl |
| &nbsp;&nbsp;1&nbsp; | &nbsp;&nbsp;.&nbsp; | &nbsp;&nbsp;.&nbsp; | &nbsp;&nbsp;.&nbsp; | &nbsp;&nbsp;.&nbsp; | &nbsp;&nbsp;.&nbsp; | &nbsp;&nbsp;.&nbsp; | &nbsp;&nbsp;.&nbsp; | &nbsp;&nbsp;.&nbsp; | &nbsp;&nbsp;.&nbsp; | &nbsp;&nbsp;.&nbsp; |  &nbsp;&nbsp;1&nbsp; | &nbsp;&nbsp;SSNvA_solar_mount.stl |
| &nbsp;&nbsp;1&nbsp; | &nbsp;&nbsp;2&nbsp; | &nbsp;&nbsp;2&nbsp; | &nbsp;&nbsp;2&nbsp; | &nbsp;&nbsp;2&nbsp; | &nbsp;&nbsp;1&nbsp; | &nbsp;&nbsp;2&nbsp; | &nbsp;&nbsp;1&nbsp; | &nbsp;&nbsp;.&nbsp; | &nbsp;&nbsp;2&nbsp; | &nbsp;&nbsp;.&nbsp; | &nbsp;&nbsp;15&nbsp; | &nbsp;&nbsp;Total 3D printed parts count |

<span></span>
[Top](#TOP)

---

## SSNvA Solar Mount Assembly
### Vitamins
|Qty|Description|
|---:|:---|
|3| Nut M4 x 3.2mm |
|3| Screw M4 pan x 16mm|
|3| Washer  M4 x 9mm x 0.8mm|
|2| Ziptie 3.6mm x 178mm min length|

### 3D Printed parts

| 1 x [SSNvA_solar_mount.stl](stls/SSNvA_solar_mount.stl) |
|---|
| SSNvA_solar_mount.stl 

### Assembly instructions
SSNvA_solar_mount_assembly

1. Inset M4 nuts
2. Attach solar penel
3. Insert zipties

SSNvA_solar_mount_assembled

<span></span>
[Top](#TOP)

---

## 2 x SSNvA Battery Cable Clamp Assembly
### Vitamins
|Qty|Description|
|---:|:---|
|4| Nut M3 x 2.4mm |

### 3D Printed parts

| 2 x [SSNvA_battery_cable_clamp.stl](stls/SSNvA_battery_cable_clamp.stl) |
|---|
| SSNvA_battery_cable_clamp.stl 

### Assembly instructions
SSNvA_battery_cable_clamp_assembly

Insert two M3 waschers into the cable clamp

SSNvA_battery_cable_clamp_assembled

<span></span>
[Top](#TOP)

---

## SSNvA Battery Frame Assembly
### 3D Printed parts

| 1 x [SSNvA_battery_frame_part1.stl](stls/SSNvA_battery_frame_part1.stl) | 1 x [SSNvA_battery_frame_part2.stl](stls/SSNvA_battery_frame_part2.stl) |
|---|---|
| SSNvA_battery_frame_part1.stl | SSNvA_battery_frame_part2.stl 

### Assembly instructions
SSNvA_battery_frame_assembly

Glue the two pieces of the frame together

SSNvA_battery_frame_assembled

<span></span>
[Top](#TOP)

---

## SSNvA Battery Assembly
### Vitamins
|Qty|Description|
|---:|:---|
|1| 1S 3.2V battery protection board|
|1| Battery negative contact|
|1| Battery positive contact|
|1| Li-Ion/LiFePo4 32700 3.2v|
|1| MPPT Solar Charge Controller|
|1| Nut M6 x 5mm |
|2| Screw M3 pan x 12mm|
|2| Screw M3 pan x 18mm|
|1| Screw M6 hex x 50mm|
|4| Washer  M3 x 7mm x 0.5mm|

### 3D Printed parts

| 2 x [SSNvA_battery_screw_handle.stl](stls/SSNvA_battery_screw_handle.stl) |
|---|
| SSNvA_battery_screw_handle.stl 

### Sub-assemblies

| 2 x SSNvA_battery_cable_clamp_assembly | 1 x SSNvA_battery_frame_assembly |
|---|---|
| SSNvA_battery_cable_clamp_assembled | SSNvA_battery_frame_assembled 

### Assembly instructions
SSNvA_battery_assembly

Solder and assemble components

SSNvA_battery_assembled

<span></span>
[Top](#TOP)

---

## SSNvA Radio Frame Assembly
### 3D Printed parts

| 1 x [SSNvA_radio_frame_part1.stl](stls/SSNvA_radio_frame_part1.stl) | 1 x [SSNvA_radio_frame_part2.stl](stls/SSNvA_radio_frame_part2.stl) |
|---|---|
| SSNvA_radio_frame_part1.stl | SSNvA_radio_frame_part2.stl 

### Assembly instructions
SSNvA_radio_frame_assembly

1. Glue the two parts of the radio frame together

SSNvA_radio_frame_assembled

<span></span>
[Top](#TOP)

---

## SSNvA Radio Assembly
### Vitamins
|Qty|Description|
|---:|:---|
|1| Heltec T144|
|2| Nut M3 x 2.4mm |
|2| Screw M3 pan x 16mm|
|2| Washer  M3 x 7mm x 0.5mm|

### 3D Printed parts

| 1 x [SSNvA_cable_clamp.stl](stls/SSNvA_cable_clamp.stl) |
|---|
| SSNvA_cable_clamp.stl 

### Sub-assemblies

| 1 x SSNvA_radio_frame_assembly |
|---|
| SSNvA_radio_frame_assembled 

### Assembly instructions
SSNvA_radio_assembly

1. Attach the cable clamp with two M3 screws
2. Insert the Heltec T114
3. Attach the power cable
4. Tighten cable clamp

SSNvA_radio_assembled

<span></span>
[Top](#TOP)

---

## SSNvA Antenna Frame Assembly
### 3D Printed parts

| 1 x [SSNvA_antenna_part1.stl](stls/SSNvA_antenna_part1.stl) | 1 x [SSNvA_antenna_part2.stl](stls/SSNvA_antenna_part2.stl) |
|---|---|
| SSNvA_antenna_part1.stl | SSNvA_antenna_part2.stl 

### Assembly instructions
SSNvA_antenna_frame_assembly

1. Glue the two parts of the antenna frame together

SSNvA_antenna_frame_assembled

<span></span>
[Top](#TOP)

---

## SSNvA Antenna Assembly
### Vitamins
|Qty|Description|
|---:|:---|
|1| Antenna with N-connector|

### 3D Printed parts

| 1 x [SSNvA_antenna_top.stl](stls/SSNvA_antenna_top.stl) |
|---|
| SSNvA_antenna_top.stl 

### Sub-assemblies

| 1 x SSNvA_antenna_frame_assembly |
|---|
| SSNvA_antenna_frame_assembled 

### Assembly instructions
SSNvA_antenna_assembly

1. Attach the antenna to the frame.  
2. Wrap teflon tape around the bottom of the antenna rod.  
3. Push the top cover over the antenna.  

SSNvA_antenna_assembled

<span></span>
[Top](#TOP)

---

## SSNvA Top Assembly
### Sub-assemblies

| 1 x SSNvA_antenna_assembly | 1 x SSNvA_radio_assembly |
|---|---|
| SSNvA_antenna_assembled | SSNvA_radio_assembled 

### Assembly instructions
SSNvA_top_assembly

SSNvA_top_assembled

<span></span>
[Top](#TOP)

---

## SSNvA Pole Assembly
### Vitamins
|Qty|Description|
|---:|:---|
|1| Conduit diameter 40mmlength 2000mm|

### 3D Printed parts

| 2 x [SSNvA_scrutonM40.stl](stls/SSNvA_scrutonM40.stl) |
|---|
| SSNvA_scrutonM40.stl 

### Assembly instructions
SSNvA_pole_assembly

1. Cut the M40 counduit to the desired length
2. Drill a 6mm hole through the pole, approx. 10mm above the bottom end
3. Slide helix segments over the pole

SSNvA_pole_assembled

<span></span>
[Top](#TOP)

---

## SSNvA Assembly
### Sub-assemblies

| 1 x SSNvA_battery_assembly | 1 x SSNvA_pole_assembly | 1 x SSNvA_solar_mount_assembly |
|---|---|---|
| SSNvA_battery_assembled | SSNvA_pole_assembled | SSNvA_solar_mount_assembled 

| 1 x SSNvA_top_assembly |
|---|
| SSNvA_top_assembled 

### Assembly instructions
SSNvA_assembly

1. Slide the antenna and radio into the top end of the pole
2. Attach the power cable of the antenna to the battery assembly
3. Slide the battery assembly into the bottom end of the pole
4. Attach the solar panel to the MPPT controller
5. Attach the panel to the panel mount
6. Attach the panel mount to the pole with zipties

SSNvA_assembled

<span></span>
[Top](#TOP)

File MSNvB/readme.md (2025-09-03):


# LoRaMeshNodes
These are the assembly instructions for the Mobile Solar Node (Variant A) (MSNvB),
a portable solar powered [Meshtastic](https://meshtastic.org) or
[MeshCore](https://meshcore.co.uk) node.

Main Assembly

<span></span>

---
## Table of Contents
1. [Parts list](#Parts_list)
1. [MSNvB LEnc Assembly](#MSNvB_lEnc_assembly)
1. [MSNvB Enc Assembly](#MSNvB_enc_assembly)
1. [MSNvB Assembly](#MSNvB_assembly)

<span></span>
[Top](#TOP)

---

## Parts list
| <span style="writing-mode: vertical-rl; text-orientation: mixed;">MSNvB&nbsp;LEnc</span> | <span style="writing-mode: vertical-rl; text-orientation: mixed;">MSNvB&nbsp;Enc</span> | <span style="writing-mode: vertical-rl; text-orientation: mixed;">MSNvB</span> | <span style="writing-mode: vertical-rl; text-orientation: mixed;">TOTALS</span> |  |
|---:|---:|---:|---:|:---|
|  |  |  | | **Vitamins** |
| &nbsp;&nbsp;1&nbsp; | &nbsp;&nbsp;.&nbsp; | &nbsp;&nbsp;.&nbsp; |  &nbsp;&nbsp;1&nbsp; | &nbsp;&nbsp; 1S 3.7V battery protection board |
| &nbsp;&nbsp;1&nbsp; | &nbsp;&nbsp;.&nbsp; | &nbsp;&nbsp;.&nbsp; |  &nbsp;&nbsp;1&nbsp; | &nbsp;&nbsp; Antenna 20cm LoRa Antenna |
| &nbsp;&nbsp;1&nbsp; | &nbsp;&nbsp;.&nbsp; | &nbsp;&nbsp;.&nbsp; |  &nbsp;&nbsp;1&nbsp; | &nbsp;&nbsp; Battery negative contact |
| &nbsp;&nbsp;1&nbsp; | &nbsp;&nbsp;.&nbsp; | &nbsp;&nbsp;.&nbsp; |  &nbsp;&nbsp;1&nbsp; | &nbsp;&nbsp; Battery positive contact |
| &nbsp;&nbsp;1&nbsp; | &nbsp;&nbsp;.&nbsp; | &nbsp;&nbsp;.&nbsp; |  &nbsp;&nbsp;1&nbsp; | &nbsp;&nbsp; Cell Samsung 25R 18650 LION |
| &nbsp;&nbsp;1&nbsp; | &nbsp;&nbsp;.&nbsp; | &nbsp;&nbsp;.&nbsp; |  &nbsp;&nbsp;1&nbsp; | &nbsp;&nbsp; Heltec L76K_GNSS Module |
| &nbsp;&nbsp;1&nbsp; | &nbsp;&nbsp;.&nbsp; | &nbsp;&nbsp;.&nbsp; |  &nbsp;&nbsp;1&nbsp; | &nbsp;&nbsp; Heltec T144 |
| &nbsp;&nbsp;1&nbsp; | &nbsp;&nbsp;.&nbsp; | &nbsp;&nbsp;.&nbsp; |  &nbsp;&nbsp;1&nbsp; | &nbsp;&nbsp; Nut M6.25 x 1.8mm  |
| &nbsp;&nbsp;1&nbsp; | &nbsp;&nbsp;1&nbsp; | &nbsp;&nbsp;.&nbsp; |  &nbsp;&nbsp;2&nbsp; | &nbsp;&nbsp; Solar Panel 100x100mm² 5V 3W |
| &nbsp;&nbsp;1&nbsp; | &nbsp;&nbsp;.&nbsp; | &nbsp;&nbsp;.&nbsp; |  &nbsp;&nbsp;1&nbsp; | &nbsp;&nbsp; Washer star M6.4 x 0.6mm |
| &nbsp;&nbsp;10&nbsp; | &nbsp;&nbsp;1&nbsp; | &nbsp;&nbsp;.&nbsp; | &nbsp;&nbsp;11&nbsp; | &nbsp;&nbsp;Total vitamins count |
|  |  |  | | **3D printed parts** |
| &nbsp;&nbsp;1&nbsp; | &nbsp;&nbsp;.&nbsp; | &nbsp;&nbsp;.&nbsp; |  &nbsp;&nbsp;1&nbsp; | &nbsp;&nbsp;MSNvB_buttons.stl |
| &nbsp;&nbsp;.&nbsp; | &nbsp;&nbsp;.&nbsp; | &nbsp;&nbsp;1&nbsp; |  &nbsp;&nbsp;1&nbsp; | &nbsp;&nbsp;MSNvB_cov.stl |
| &nbsp;&nbsp;1&nbsp; | &nbsp;&nbsp;.&nbsp; | &nbsp;&nbsp;.&nbsp; |  &nbsp;&nbsp;1&nbsp; | &nbsp;&nbsp;MSNvB_lEnc.stl |
| &nbsp;&nbsp;1&nbsp; | &nbsp;&nbsp;.&nbsp; | &nbsp;&nbsp;.&nbsp; |  &nbsp;&nbsp;1&nbsp; | &nbsp;&nbsp;MSNvB_stand.stl |
| &nbsp;&nbsp;.&nbsp; | &nbsp;&nbsp;1&nbsp; | &nbsp;&nbsp;.&nbsp; |  &nbsp;&nbsp;1&nbsp; | &nbsp;&nbsp;MSNvB_top.stl |
| &nbsp;&nbsp;3&nbsp; | &nbsp;&nbsp;1&nbsp; | &nbsp;&nbsp;1&nbsp; | &nbsp;&nbsp;5&nbsp; | &nbsp;&nbsp;Total 3D printed parts count |

<span></span>
[Top](#TOP)

---

## MSNvB LEnc Assembly
### Vitamins
|Qty|Description|
|---:|:---|
|1| 1S 3.7V battery protection board|
|1| Antenna 20cm LoRa Antenna|
|1| Battery negative contact|
|1| Battery positive contact|
|1| Cell Samsung 25R 18650 LION|
|1| Heltec L76K_GNSS Module|
|1| Heltec T144|
|1| Nut M6.25 x 1.8mm |
|1| Solar Panel 100x100mm² 5V 3W|
|1| Washer star M6.4 x 0.6mm|

### 3D Printed parts

| 1 x [MSNvB_buttons.stl](stls/MSNvB_buttons.stl) | 1 x [MSNvB_lEnc.stl](stls/MSNvB_lEnc.stl) | 1 x [MSNvB_stand.stl](stls/MSNvB_stand.stl) |
|---|---|---|
| MSNvB_buttons.stl | MSNvB_lEnc.stl | MSNvB_stand.stl 

### Assembly instructions
MSNvB_lEnc_assembly

1. Clamp the stand on to the enclosure 
1. Attach the antenna to the enclosure 
2. Connect it to the Heltec T114 board
3. Insert buttons
4. Insert Heltec T114 board
5. Connect and insert the GNSS module (optional)
6. Attach the battery with two zip ties
7. Connect the battery to the Heltec T114 board

MSNvB_lEnc_assembled

<span></span>
[Top](#TOP)

---

## MSNvB Enc Assembly
### Vitamins
|Qty|Description|
|---:|:---|
|1| Solar Panel 100x100mm² 5V 3W|

### 3D Printed parts

| 1 x [MSNvB_top.stl](stls/MSNvB_top.stl) |
|---|
| MSNvB_top.stl 

### Sub-assemblies

| 1 x MSNvB_lEnc_assembly |
|---|
| MSNvB_lEnc_assembled 

### Assembly instructions
MSNvB_enc_assembly

1. Connect the solar panel to the Heltec T114 board
2. Place the solar panel on the enclosure
3. Attach the top frame

MSNvB_enc_assembled

<span></span>
[Top](#TOP)

---

## MSNvB Assembly
### 3D Printed parts

| 1 x [MSNvB_cov.stl](stls/MSNvB_cov.stl) |
|---|
| MSNvB_cov.stl 

### Sub-assemblies

| 1 x MSNvB_enc_assembly |
|---|
| MSNvB_enc_assembled 

### Assembly instructions
MSNvB_assembly

Slide on the protective cover for transportation.

MSNvB_assembled

<span></span>
[Top](#TOP)

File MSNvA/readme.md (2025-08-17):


# LoRaMeshNodes
These are the assembly instructions for the Mobile Solar Node (Variant A) (MSNvA),
a portable solar powered [Meshtastic](https://meshtastic.org) or
[MeshCore](https://meshcore.co.uk) node.

Main Assembly

<span></span>

---
## Table of Contents
1. [Parts list](#Parts_list)
1. [MSNvA LEnc Assembly](#MSNvA_lEnc_assembly)
1. [MSNvA Enc Assembly](#MSNvA_enc_assembly)
1. [MSNvA Assembly](#MSNvA_assembly)

<span></span>
[Top](#TOP)

---

## Parts list
| <span style="writing-mode: vertical-rl; text-orientation: mixed;">MSNvA&nbsp;LEnc</span> | <span style="writing-mode: vertical-rl; text-orientation: mixed;">MSNvA&nbsp;Enc</span> | <span style="writing-mode: vertical-rl; text-orientation: mixed;">MSNvA</span> | <span style="writing-mode: vertical-rl; text-orientation: mixed;">TOTALS</span> |  |
|---:|---:|---:|---:|:---|
|  |  |  | | **Vitamins** |
| &nbsp;&nbsp;1&nbsp; | &nbsp;&nbsp;.&nbsp; | &nbsp;&nbsp;.&nbsp; |  &nbsp;&nbsp;1&nbsp; | &nbsp;&nbsp; Antenna 20cm LoRa Antenna |
| &nbsp;&nbsp;1&nbsp; | &nbsp;&nbsp;.&nbsp; | &nbsp;&nbsp;.&nbsp; |  &nbsp;&nbsp;1&nbsp; | &nbsp;&nbsp; Heltec L76K_GNSS Module |
| &nbsp;&nbsp;1&nbsp; | &nbsp;&nbsp;.&nbsp; | &nbsp;&nbsp;.&nbsp; |  &nbsp;&nbsp;1&nbsp; | &nbsp;&nbsp; Heltec T144 |
| &nbsp;&nbsp;1&nbsp; | &nbsp;&nbsp;.&nbsp; | &nbsp;&nbsp;.&nbsp; |  &nbsp;&nbsp;1&nbsp; | &nbsp;&nbsp; Lithium-Polymer-Akku 3,7V 2500mAh |
| &nbsp;&nbsp;1&nbsp; | &nbsp;&nbsp;.&nbsp; | &nbsp;&nbsp;.&nbsp; |  &nbsp;&nbsp;1&nbsp; | &nbsp;&nbsp; Nut M6.25 x 1.8mm  |
| &nbsp;&nbsp;1&nbsp; | &nbsp;&nbsp;1&nbsp; | &nbsp;&nbsp;.&nbsp; |  &nbsp;&nbsp;2&nbsp; | &nbsp;&nbsp; Solar Panel 100x100mm² 5V 3W |
| &nbsp;&nbsp;1&nbsp; | &nbsp;&nbsp;.&nbsp; | &nbsp;&nbsp;.&nbsp; |  &nbsp;&nbsp;1&nbsp; | &nbsp;&nbsp; Washer star M6.4 x 0.6mm |
| &nbsp;&nbsp;7&nbsp; | &nbsp;&nbsp;1&nbsp; | &nbsp;&nbsp;.&nbsp; | &nbsp;&nbsp;8&nbsp; | &nbsp;&nbsp;Total vitamins count |
|  |  |  | | **3D printed parts** |
| &nbsp;&nbsp;1&nbsp; | &nbsp;&nbsp;.&nbsp; | &nbsp;&nbsp;.&nbsp; |  &nbsp;&nbsp;1&nbsp; | &nbsp;&nbsp;MSNvA_buttons.stl |
| &nbsp;&nbsp;.&nbsp; | &nbsp;&nbsp;.&nbsp; | &nbsp;&nbsp;1&nbsp; |  &nbsp;&nbsp;1&nbsp; | &nbsp;&nbsp;MSNvA_cov.stl |
| &nbsp;&nbsp;1&nbsp; | &nbsp;&nbsp;.&nbsp; | &nbsp;&nbsp;.&nbsp; |  &nbsp;&nbsp;1&nbsp; | &nbsp;&nbsp;MSNvA_lEnc.stl |
| &nbsp;&nbsp;1&nbsp; | &nbsp;&nbsp;.&nbsp; | &nbsp;&nbsp;.&nbsp; |  &nbsp;&nbsp;1&nbsp; | &nbsp;&nbsp;MSNvA_stand.stl |
| &nbsp;&nbsp;.&nbsp; | &nbsp;&nbsp;1&nbsp; | &nbsp;&nbsp;.&nbsp; |  &nbsp;&nbsp;1&nbsp; | &nbsp;&nbsp;MSNvA_top.stl |
| &nbsp;&nbsp;3&nbsp; | &nbsp;&nbsp;1&nbsp; | &nbsp;&nbsp;1&nbsp; | &nbsp;&nbsp;5&nbsp; | &nbsp;&nbsp;Total 3D printed parts count |

<span></span>
[Top](#TOP)

---

## MSNvA LEnc Assembly
### Vitamins
|Qty|Description|
|---:|:---|
|1| Antenna 20cm LoRa Antenna|
|1| Heltec L76K_GNSS Module|
|1| Heltec T144|
|1| Lithium-Polymer-Akku 3,7V 2500mAh|
|1| Nut M6.25 x 1.8mm |
|1| Solar Panel 100x100mm² 5V 3W|
|1| Washer star M6.4 x 0.6mm|

### 3D Printed parts

| 1 x [MSNvA_buttons.stl](stls/MSNvA_buttons.stl) | 1 x [MSNvA_lEnc.stl](stls/MSNvA_lEnc.stl) | 1 x [MSNvA_stand.stl](stls/MSNvA_stand.stl) |
|---|---|---|
| MSNvA_buttons.stl | MSNvA_lEnc.stl | MSNvA_stand.stl 

### Assembly instructions
MSNvA_lEnc_assembly

1. Attach the antenna to the enclosure 
2. Connect it to the Heltec T114 board
3. Insert buttons
4. Insert Heltec T114 board
5. Connect and insert the GNSS module (optional)
6. Attach the battery with two zip ties
7. Connect the battery to the Heltec T114 board

MSNvA_lEnc_assembled

<span></span>
[Top](#TOP)

---

## MSNvA Enc Assembly
### Vitamins
|Qty|Description|
|---:|:---|
|1| Solar Panel 100x100mm² 5V 3W|

### 3D Printed parts

| 1 x [MSNvA_top.stl](stls/MSNvA_top.stl) |
|---|
| MSNvA_top.stl 

### Sub-assemblies

| 1 x MSNvA_lEnc_assembly |
|---|
| MSNvA_lEnc_assembled 

### Assembly instructions
MSNvA_enc_assembly

1. Connect the solar panel to the Heltec T114 board
2. Place the solar panel on the enclosure
3. Attach the top frame

MSNvA_enc_assembled

<span></span>
[Top](#TOP)

---

## MSNvA Assembly
### 3D Printed parts

| 1 x [MSNvA_cov.stl](stls/MSNvA_cov.stl) |
|---|
| MSNvA_cov.stl 

### Sub-assemblies

| 1 x MSNvA_enc_assembly |
|---|
| MSNvA_enc_assembled 

### Assembly instructions
MSNvA_assembly

Slide on the protective cover for transportation.

MSNvA_assembled

<span></span>
[Top](#TOP)

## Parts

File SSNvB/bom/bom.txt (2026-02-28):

Vitamins:
          S                  
          s                  
          n                  
          v                  
          b                  
                             
          b  S               
          a  s               
          t  n           S   
          t  v           s   
          e  b           n   
          r              v   
 S     S  y  b           b   
 s     s     a               
 n     n  c  t        S  r  S
 v     v  a  t  S  S  s  a  s
 b     b  b  e  s  s  n  d  n
          l  r  n  n  v  i  v
 a     b  e  y  v  v  b  o  b
 n     a        b  b         
 t  S  t  c  f        r  f  s
 e  s  t  l  r  c  p  a  r  o
 n  n  e  a  a  o  i  d  a  l
 n  v  r  m  m  r  p  i  m  a
 a  b  y  p  e  e  e  o  e  r
 1|  |  |  |  |  |  |  |  |  |  1 Antenna with N-connector
  |  | 1|  |  |  |  |  |  |  |  1 Li-Ion/LiFePo4 32700 3.2v
  |  | 1|  |  |  |  |  |  |  |  1 Battery negative contact
  |  | 1|  |  |  |  |  |  |  |  1 Battery positive contact
  |  |  |  |  |  | 1|  |  |  |  1 Conduit diameter 40mmlength 470mm
  |  |  |  |  |  |  |  |  | 3|  3 Flexible Solar Panel 198x100mm² 6V 1W
  |  |  | 2|  |  |  |  |  |  |  2 Nut M3 x 2.4mm 
  |  |  |  |  |  |  | 1|  |  |  1 Heltec T144
  |  | 1|  |  |  |  |  |  |  |  1 1S 3.2V battery protection board
  |  | 1|  |  |  |  |  |  |  |  1 MPPT Solar Charge Controller
  |  | 2|  |  |  |  |  |  |  |  2 Screw M3 pan x 10mm
  |  | 2|  |  |  |  |  |  |  |  2 Washer  M3 x 7mm x 0.5mm

Printed:
  |  |  |  |  |  | 2|  |  |  |  2 SSNvB_EndcapThread.stl
  |  |  |  |  |  | 1|  |  |  |  1 SSNvB_LIEncMount.stl
  |  |  |  |  |  | 1|  |  |  |  1 SSNvB_LOEncMount.stl
  |  |  |  |  |  | 1|  |  |  |  1 SSNvB_UIEncMount.stl
  |  |  |  |  |  | 1|  |  |  |  1 SSNvB_UOEncMount.stl
 1|  |  |  |  |  |  |  |  |  |  1 SSNvB_antenna.stl
  | 1|  |  |  |  |  |  |  |  |  1 SSNvB_antennaMountFastener.stl
  |  |  |  |  |  | 1|  |  |  |  1 SSNvB_antennaMountThread.stl
  |  |  | 1|  |  |  |  |  |  |  1 SSNvB_battery_cable_clamp.stl
  |  |  |  | 1|  |  |  |  |  |  1 SSNvB_battery_frame_part1.stl
  |  |  |  | 1|  |  |  |  |  |  1 SSNvB_battery_frame_part2.stl
  | 1|  |  |  |  |  |  |  |  |  1 SSNvB_lEndcap.stl
  |  |  |  |  |  |  |  | 1|  |  1 SSNvB_radio_frame_part1.stl
  |  |  |  |  |  |  |  | 1|  |  1 SSNvB_radio_frame_part2.stl
  | 1|  |  |  |  |  |  |  |  |  1 SSNvB_uEndcap.stl

Assemblies:
  1 SSNvB_antenna_assembly
  1 SSNvB_assembly
  1 SSNvB_battery_assembly
  1 SSNvB_battery_cable_clamp_assembly
  1 SSNvB_battery_frame_assembly
  1 SSNvB_core_assembly
  1 SSNvB_pipe_assembly
  1 SSNvB_radio_assembly
  1 SSNvB_radio_frame_assembly
  1 SSNvB_solar_assembly

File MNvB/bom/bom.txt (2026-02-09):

Vitamins:
    M
    n
    v
    b
     
 M  l
 n  e
 v  n
 b  c
 1|  |  1 Antenna 20cm LoRa Antenna
 1|  |  1 Cell Samsung 25R 18650 LION
  | 2|  2 Nut M3 x 2.4mm 
 1|  |  1 Nut M6.25 x 1.8mm 
 1|  |  1 Heltec T144
 1|  |  1 1S 3.7V battery protection board
 2|  |  2 Screw M3 dome x 10mm
 1|  |  1 Washer star M6.4 x 0.6mm

Printed:
 1|  |  1 MNvB_buttons.stl
  | 1|  1 MNvB_lEnc.stl
 1|  |  1 MNvB_uEnc.stl

Assemblies:
  1 MNvB_assembly
  1 MNvB_lEnc_assembly

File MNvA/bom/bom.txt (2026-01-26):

Vitamins:
    M
    n
    v
    a
     
 M  l
 n  e
 v  n
 a  c
 1|  |  1 Antenna 20cm LoRa Antenna
 1|  |  1 Lithium-Polymer-Akku 3,7V 3000mAh
  | 2|  2 Nut M3 x 2.4mm 
 1|  |  1 Nut M6.25 x 1.8mm 
 1|  |  1 Heltec T144
 2|  |  2 Screw M3 dome x 10mm
 1|  |  1 Washer star M6.4 x 0.6mm

Printed:
 1|  |  1 MNvA_buttons.stl
  | 1|  1 MNvA_lEnc.stl
 1|  |  1 MNvA_uEnc.stl

Assemblies:
  1 MNvA_assembly
  1 MNvA_lEnc_assembly

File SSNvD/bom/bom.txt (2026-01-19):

Vitamins:
             S                     
             s                     
             n                     
             v                     
             d                     
                                   
    S        b  S                  
    s        a  s                  
    n        t  n        S  S      
    v        t  v        s  s      
    d        e  d        n  n      
             r           v  v      
 S  a     S  y  b        d  d      
 s  n     s     a              S   
 n  t     n  c  t     S  r  s  s   
 v  e     v  a  t  S  s  a  o  n   
 d  n     d  b  e  s  n  d  l  v  S
    n        l  r  n  v  i  a  d  s
 a  a     b  e  y  v  d  o  r     n
 n        a        d           s  v
 t  f  S  t  c  f     r  f  m  p  d
 e  r  s  t  l  r  p  a  r  o  a   
 n  a  n  e  a  a  o  d  a  u  c  t
 n  m  v  r  m  m  l  i  m  n  e  o
 a  e  d  y  p  e  e  o  e  t  r  p
 1|  |  |  |  |  |  |  |  |  |  |  |  1 Antenna with N-connector
  |  |  | 1|  |  |  |  |  |  |  |  |  1 Li-Ion/LiFePo4 32700 3.2v
  |  |  | 1|  |  |  |  |  |  |  |  |  1 Battery negative contact
  |  |  | 1|  |  |  |  |  |  |  |  |  1 Battery positive contact
  |  |  |  |  |  | 1|  |  |  |  |  |  1 Conduit diameter 40mmlength 300mm
  |  |  |  | 2|  |  |  |  |  |  |  |  2 Nut M3 x 2.4mm 
  |  |  |  |  |  |  |  |  | 3|  |  |  3 Nut M4 x 3.2mm 
  |  |  |  |  |  |  | 1|  |  |  |  |  1 Heltec T144
  |  |  | 1|  |  |  |  |  |  |  |  |  1 1S 3.2V battery protection board
  |  |  | 1|  |  |  |  |  |  |  |  |  1 MPPT Solar Charge Controller
  |  |  | 2|  |  |  |  |  |  |  |  |  2 Screw M3 pan x 10mm
  |  |  |  |  |  |  |  |  | 3|  |  |  3 Screw M4 pan x 16mm
  |  |  | 2|  |  |  |  |  |  |  |  |  2 Washer  M3 x 7mm x 0.5mm
  |  |  |  |  |  |  |  |  | 3|  |  |  3 Washer  M4 x 9mm x 0.8mm
  |  |  |  |  |  |  |  |  | 2|  |  |  2 Ziptie 3.6mm x 178mm min length
  |  |  |  |  |  |  |  |  |  | 2|  |  2 Ziptie 3.6mm x 197mm min length

Printed:
  | 1|  |  |  |  |  |  |  |  |  |  |  1 SSNvD_antenna_part1.stl
  | 1|  |  |  |  |  |  |  |  |  |  |  1 SSNvD_antenna_part2.stl
 1|  |  |  |  |  |  |  |  |  |  |  |  1 SSNvD_antenna_top.stl
  |  |  |  | 1|  |  |  |  |  |  |  |  1 SSNvD_battery_cable_clamp.stl
  |  |  |  |  | 1|  |  |  |  |  |  |  1 SSNvD_battery_frame_part1.stl
  |  |  |  |  | 1|  |  |  |  |  |  |  1 SSNvD_battery_frame_part2.stl
  |  | 1|  |  |  |  |  |  |  |  |  |  1 SSNvD_end_cap.stl
  |  |  |  |  |  | 1|  |  |  |  |  |  1 SSNvD_end_cap_ring.stl
  |  |  |  |  |  |  |  | 1|  |  |  |  1 SSNvD_radio_frame_part1.stl
  |  |  |  |  |  |  |  | 1|  |  |  |  1 SSNvD_radio_frame_part2.stl
  |  |  |  |  |  |  |  |  | 1|  |  |  1 SSNvD_solar_mount.stl
  |  |  |  |  |  |  |  |  |  | 2|  |  2 SSNvD_spacer.stl

Assemblies:
  1 SSNvD_antenna_assembly
  1 SSNvD_antenna_frame_assembly
  1 SSNvD_assembly
  1 SSNvD_battery_assembly
  1 SSNvD_battery_cable_clamp_assembly
  1 SSNvD_battery_frame_assembly
  1 SSNvD_pole_assembly
  1 SSNvD_radio_assembly
  1 SSNvD_radio_frame_assembly
  1 SSNvD_solar_mount_assembly
  2 SSNvD_spacer_assemblies
  1 SSNvD_top_assembly

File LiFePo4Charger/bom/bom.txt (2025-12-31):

Vitamins:
 L
 i
 f
 e
 p
 o
 4
 c
 h
 a
 r
 g
 e
 r
 1|  1 Li-Ion/LiFePo4 32700 3.2v
 1|  1 Battery negative contact
 1|  1 Battery positive contact
 2|  2 Nut M3 x 2.4mm 
 1|  1 LiFePo4 USB Charger
 2|  2 Screw M3 dome x 20mm

Printed:
 1|  1 LiFePoCharger_frame_part1.stl
 1|  1 LiFePoCharger_frame_part2.stl

Assemblies:
  1 LiFePo4Charger_assembly

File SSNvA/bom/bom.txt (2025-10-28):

Vitamins:
             S                  
             s                  
             n                  
             v                  
             a                  
                                
    S        b  S               
    s        a  s               
    n        t  n        S  S   
    v        t  v        s  s   
    a        e  a        n  n   
             r           v  v   
 S  a     S  y  b        a  a   
 s  n     s     a               
 n  t     n  c  t     S  r  s   
 v  e     v  a  t  S  s  a  o   
 a  n     a  b  e  s  n  d  l  S
    n        l  r  n  v  i  a  s
 a  a     b  e  y  v  a  o  r  n
 n        a        a           v
 t  f  S  t  c  f     r  f  m  a
 e  r  s  t  l  r  p  a  r  o   
 n  a  n  e  a  a  o  d  a  u  t
 n  m  v  r  m  m  l  i  m  n  o
 a  e  a  y  p  e  e  o  e  t  p
 1|  |  |  |  |  |  |  |  |  |  |  1 Antenna with N-connector
  |  |  | 1|  |  |  |  |  |  |  |  1 Li-Ion/LiFePo4 32700 3.2v
  |  |  | 1|  |  |  |  |  |  |  |  1 Battery negative contact
  |  |  | 1|  |  |  |  |  |  |  |  1 Battery positive contact
  |  |  |  |  |  | 1|  |  |  |  |  1 Conduit diameter 40mmlength 2000mm
  |  |  |  | 4|  |  | 2|  |  |  |  6 Nut M3 x 2.4mm 
  |  |  |  |  |  |  |  |  | 3|  |  3 Nut M4 x 3.2mm 
  |  |  | 1|  |  |  |  |  |  |  |  1 Nut M6 x 5mm 
  |  |  |  |  |  |  | 1|  |  |  |  1 Heltec T144
  |  |  | 1|  |  |  |  |  |  |  |  1 1S 3.2V battery protection board
  |  |  | 1|  |  |  |  |  |  |  |  1 MPPT Solar Charge Controller
  |  |  | 2|  |  |  |  |  |  |  |  2 Screw M3 pan x 12mm
  |  |  |  |  |  |  | 2|  |  |  |  2 Screw M3 pan x 16mm
  |  |  | 2|  |  |  |  |  |  |  |  2 Screw M3 pan x 18mm
  |  |  |  |  |  |  |  |  | 3|  |  3 Screw M4 pan x 16mm
  |  |  | 1|  |  |  |  |  |  |  |  1 Screw M6 hex x 50mm
  |  |  | 4|  |  |  | 2|  |  |  |  6 Washer  M3 x 7mm x 0.5mm
  |  |  |  |  |  |  |  |  | 3|  |  3 Washer  M4 x 9mm x 0.8mm
  |  |  |  |  |  |  |  |  | 2|  |  2 Ziptie 3.6mm x 178mm min length

Printed:
  | 1|  |  |  |  |  |  |  |  |  |  1 SSNvA_antenna_part1.stl
  | 1|  |  |  |  |  |  |  |  |  |  1 SSNvA_antenna_part2.stl
 1|  |  |  |  |  |  |  |  |  |  |  1 SSNvA_antenna_top.stl
  |  |  |  | 2|  |  |  |  |  |  |  2 SSNvA_battery_cable_clamp.stl
  |  |  |  |  | 1|  |  |  |  |  |  1 SSNvA_battery_frame_part1.stl
  |  |  |  |  | 1|  |  |  |  |  |  1 SSNvA_battery_frame_part2.stl
  |  |  | 2|  |  |  |  |  |  |  |  2 SSNvA_battery_screw_handle.stl
  |  |  |  |  |  |  | 1|  |  |  |  1 SSNvA_cable_clamp.stl
  |  |  |  |  |  |  |  | 1|  |  |  1 SSNvA_radio_frame_part1.stl
  |  |  |  |  |  |  |  | 1|  |  |  1 SSNvA_radio_frame_part2.stl
  |  |  |  |  |  | 2|  |  |  |  |  2 SSNvA_scrutonM40.stl
  |  |  |  |  |  |  |  |  | 1|  |  1 SSNvA_solar_mount.stl

Assemblies:
  1 SSNvA_antenna_assembly
  1 SSNvA_antenna_frame_assembly
  1 SSNvA_assembly
  1 SSNvA_battery_assembly
  2 SSNvA_battery_cable_clamp_assemblies
  1 SSNvA_battery_frame_assembly
  1 SSNvA_pole_assembly
  1 SSNvA_radio_assembly
  1 SSNvA_radio_frame_assembly
  1 SSNvA_solar_mount_assembly
  1 SSNvA_top_assembly

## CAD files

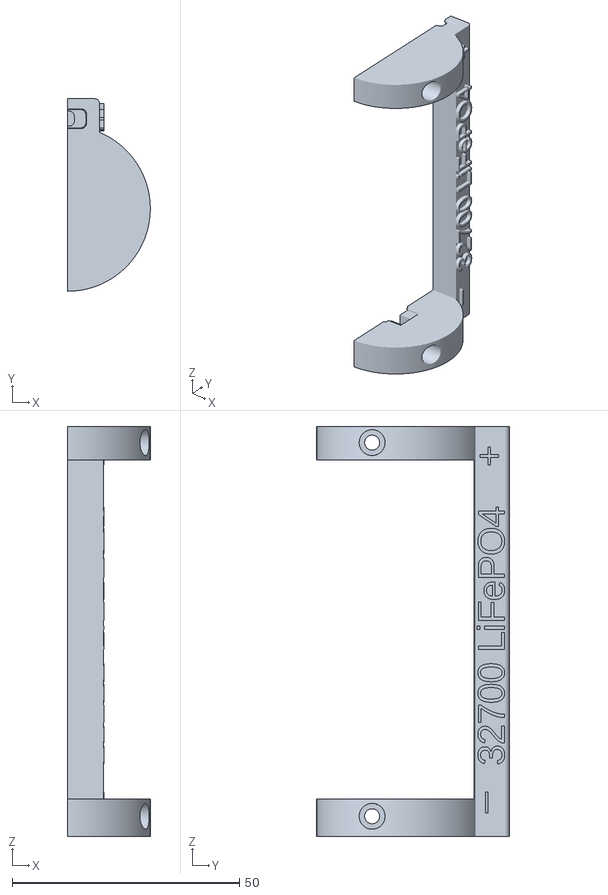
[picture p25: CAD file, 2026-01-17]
LiFePo4Charger/stls/LiFePoCharger_frame_part2.stl
18.2 x 42.4 x 90.3

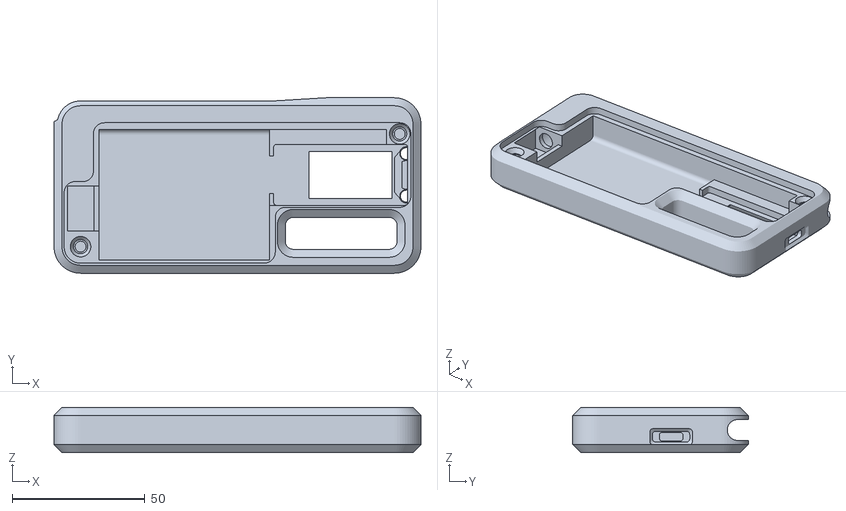
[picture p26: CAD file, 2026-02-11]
MNvA/stls/MNvA_lEnc.stl
138.0 x 66.0 x 17.0

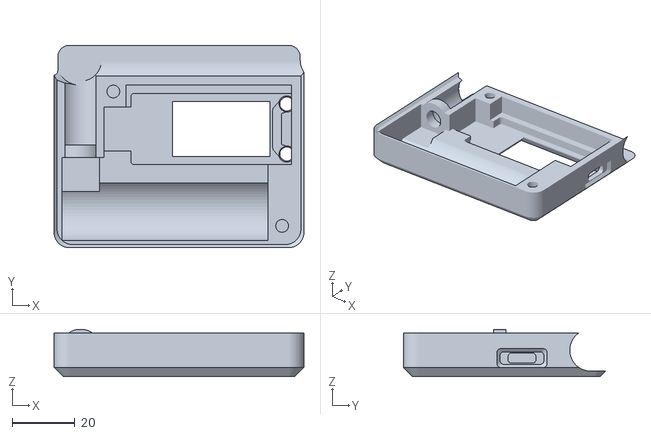
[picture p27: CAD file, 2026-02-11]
MNvB/stls/MNvB_lEnc.stl
80.0 x 64.8 x 15.2

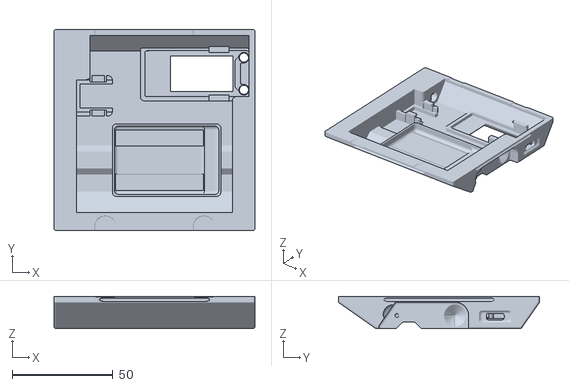
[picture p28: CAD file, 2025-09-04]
MSNvA/stls/LMA_MSNvA_lEnc.stl
100.0 x 100.0 x 16.0

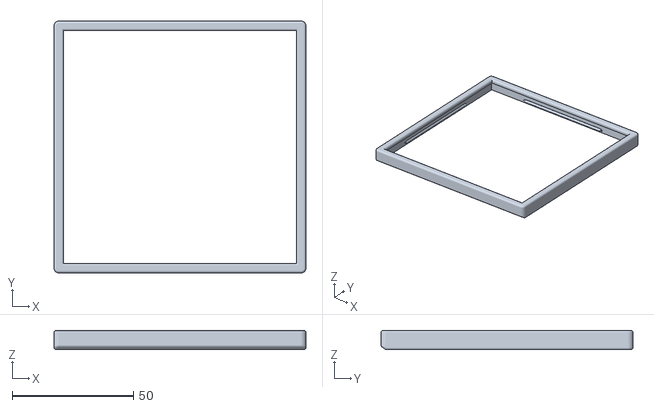
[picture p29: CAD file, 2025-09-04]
MSNvB/stls/MSNvB_top.stl
104.0 x 104.0 x 8.00

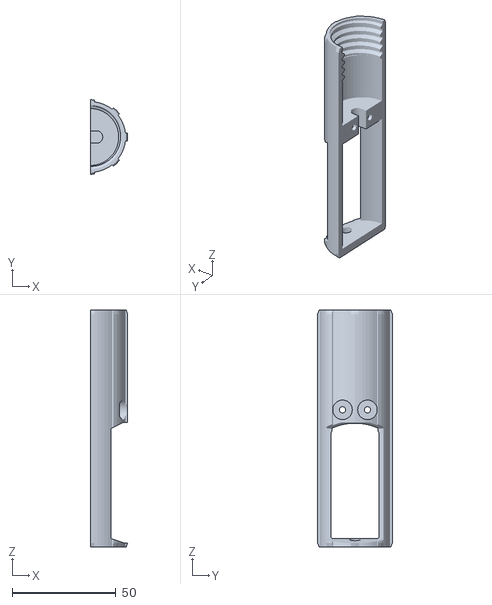
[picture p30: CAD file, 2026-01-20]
SSNvA/stls/SSNvA_radio_frame_part2.stl
18.0 x 36.0 x 114.0

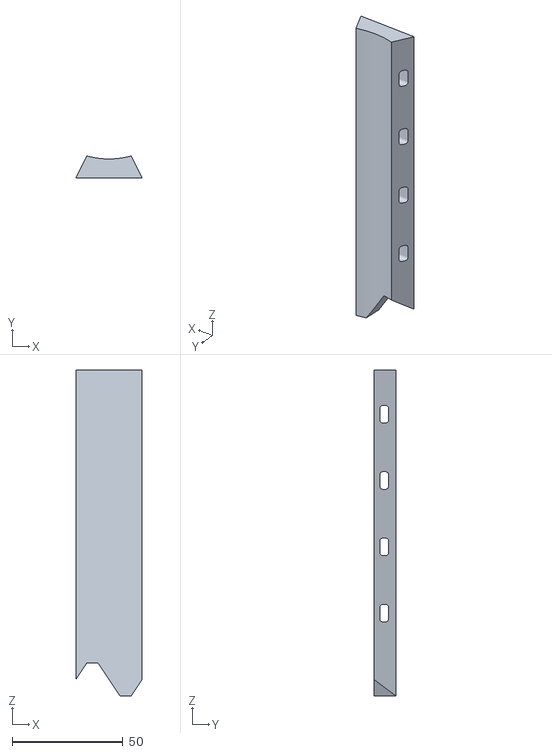
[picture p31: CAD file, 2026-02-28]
SSNvB/stls/SSNvB_UIEncMount.stl
30.0 x 10.0 x 147.5

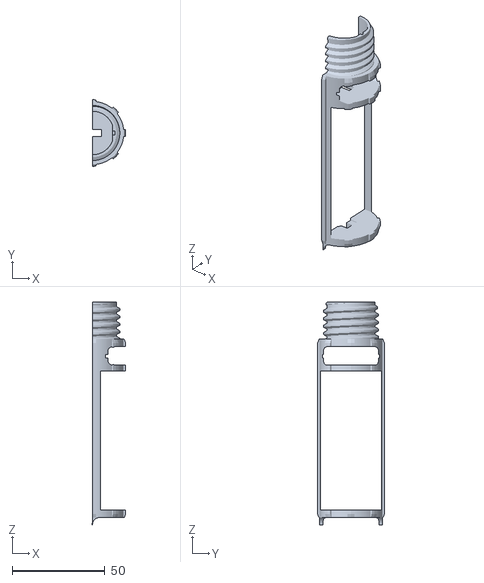
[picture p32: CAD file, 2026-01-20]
SSNvD/stls/SSNvD_battery_frame_part2.stl
18.0 x 36.0 x 120.0

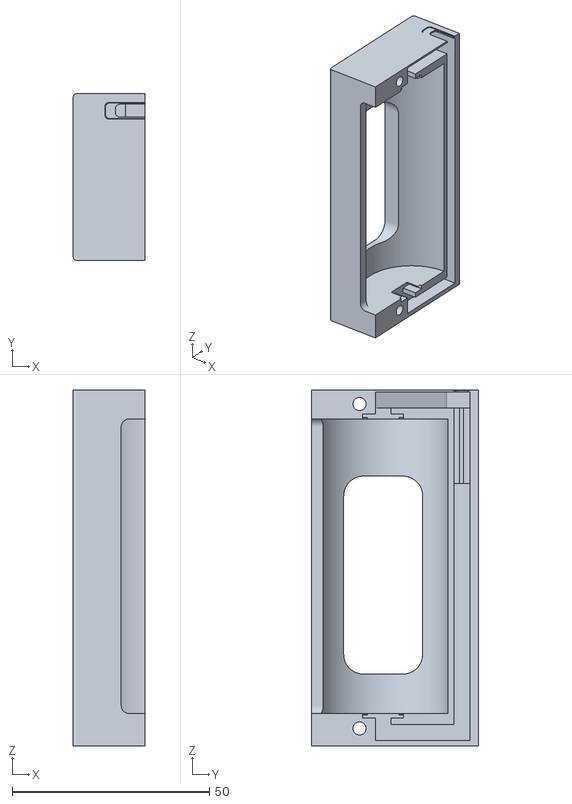
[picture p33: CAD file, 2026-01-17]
LiFePo4Charger/stls/LiFePoCharger_frame_part1.stl
18.2 x 42.4 x 90.3

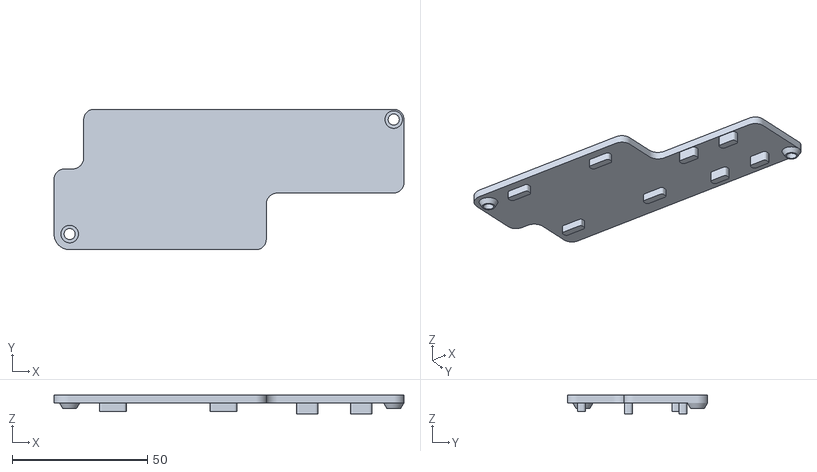
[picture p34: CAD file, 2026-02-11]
MNvA/stls/MNvA_uEnc.stl
129.6 x 52.0 x 7.00

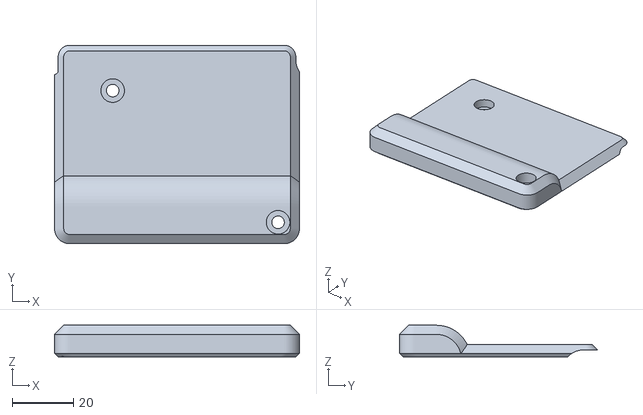
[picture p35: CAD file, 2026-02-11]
MNvB/stls/MNvB_uEnc.stl
80.0 x 64.8 x 10.3

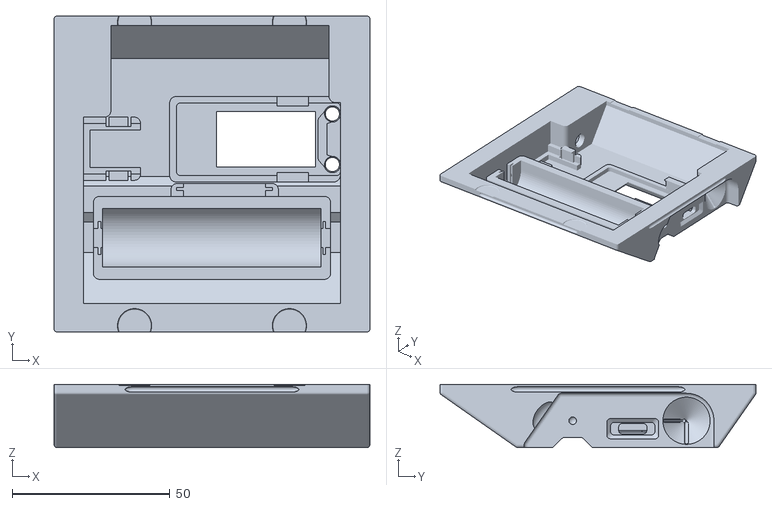
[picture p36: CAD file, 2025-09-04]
MSNvB/stls/MSNvB_lEnc.stl
100.0 x 100.0 x 20.0

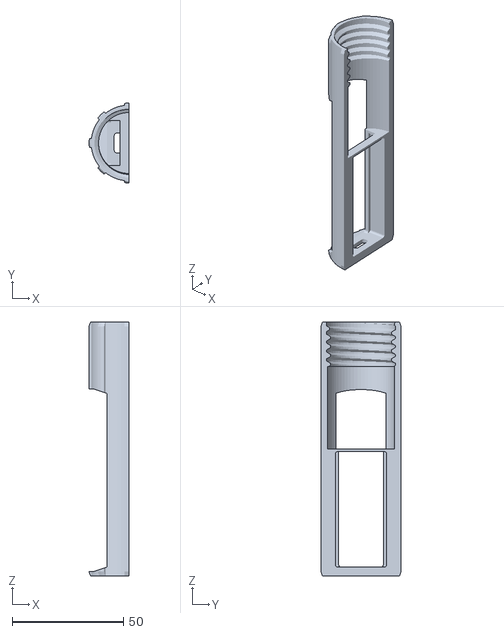
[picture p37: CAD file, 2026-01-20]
SSNvA/stls/SSNvA_radio_frame_part1.stl
18.0 x 36.0 x 114.0

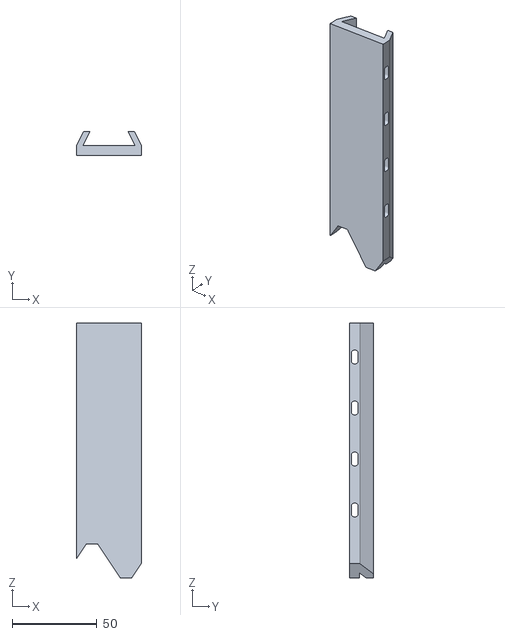
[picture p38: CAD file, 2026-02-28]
SSNvB/stls/SSNvB_UOEncMount.stl
38.0 x 14.0 x 150.0

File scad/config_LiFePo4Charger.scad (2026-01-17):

//###############################################################################
//# LoRaMeshNodes - LiFePo4 Battery Charger                                     #
//###############################################################################
//#    Copyright 2025 Dirk Heisswolf                                            #
//#    This file is part of the LoRaMeshNodes project.                          #
//#                                                                             #
//#    This project is free software: you can redistribute it and/or modify     #
//#    it under the terms of the GNU General Public License as published by     #
//#    the Free Software Foundation, either version 3 of the License, or        #
//#    (at your option) any later version.                                      #
//#                                                                             #
//#    This project is distributed in the hope that it will be useful,          #
//#    but WITHOUT ANY WARRANTY; without even the implied warranty of           #
//#    MERCHANTABILITY or FITNESS FOR A PARTICULAR PURPOSE.  See the            #
//#    GNU General Public License for more details.                             #
//#                                                                             #
//#    You should have received a copy of the GNU General Public License        #
//#    along with this project.  If not, see <http://www.gnu.org/licenses/>.    #
//#                                                                             #
//#    This project makes use of the NopSCADlib library                         #
//#    (see https://github.com/nophead/NopSCADlib).                             #
//#                                                                             #
//###############################################################################
//# Description:                                                                #
//#   Variant specific configuration                                            #
//#                                                                             #
//###############################################################################
//# Version History:                                                            #
//#   December 29, 2025                                                         #
//#      - Initial release                                                      #
//#                                                                             #
//###############################################################################

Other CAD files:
MSNvA/stls/MSNvA_top.stl
SSNvD/stls/SSNvD_battery_frame_part1.stl
MNvA/stls/MNvA_buttons.stl
MNvB/stls/MNvB_buttons.stl
scad/config_MNvA.scad
scad/config_MNvB.scad
scad/config_MSNvA.scad
MSNvA/stls/MSNvA_buttons.stl
MSNvA/stls/MSNvA_cov.stl
MSNvA/stls/MSNvA_stand.stl
MSNvB/stls/MSNvB_buttons.stl
MSNvB/stls/MSNvB_cov.stl
MSNvB/stls/MSNvB_stand.stl
SSNvA/stls/SSNvA_antenna_part1.stl
SSNvA/stls/SSNvA_antenna_part2.stl
SSNvA/stls/SSNvA_antenna_top.stl
SSNvA/stls/SSNvA_battery_cable_clamp.stl
SSNvA/stls/SSNvA_battery_frame_part1.stl
SSNvA/stls/SSNvA_battery_frame_part2.stl
SSNvA/stls/SSNvA_battery_screw_handle.stl
SSNvA/stls/SSNvA_cable_clamp.stl
SSNvA/stls/SSNvA_scrutonM40.stl
SSNvA/stls/SSNvA_solar_mount.stl
SSNvB/stls/SSNvB_EndcapThread.stl
SSNvB/stls/SSNvB_LIEncMount.stl
SSNvB/stls/SSNvB_LOEncMount.stl
SSNvB/stls/SSNvB_antenna.stl
SSNvB/stls/SSNvB_antennaMountFastener.stl
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

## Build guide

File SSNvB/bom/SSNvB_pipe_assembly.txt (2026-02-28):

SSNvB_pipe_assembly:
Vitamins:
  1 Conduit diameter 40mmlength 470mm

Printed:
  2 SSNvB_EndcapThread.stl
  1 SSNvB_LIEncMount.stl
  1 SSNvB_LOEncMount.stl
  1 SSNvB_UIEncMount.stl
  1 SSNvB_UOEncMount.stl
  1 SSNvB_antennaMountThread.stl

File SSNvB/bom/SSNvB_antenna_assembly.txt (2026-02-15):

SSNvB_antenna_assembly:
Vitamins:
  1 Antenna with N-connector

Printed:
  1 SSNvB_antenna.stl

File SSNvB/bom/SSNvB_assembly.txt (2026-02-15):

SSNvB_assembly:
Printed:
  1 SSNvB_antennaMountFastener.stl
  1 SSNvB_lEndcap.stl
  1 SSNvB_uEndcap.stl

Assemblies:
  1 SSNvB_core_assembly
  1 SSNvB_solar_assembly

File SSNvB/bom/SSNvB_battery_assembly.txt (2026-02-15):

SSNvB_battery_assembly:
Vitamins:
  1 Li-Ion/LiFePo4 32700 3.2v
  1 Battery negative contact
  1 Battery positive contact
  1 1S 3.2V battery protection board
  1 MPPT Solar Charge Controller
  2 Screw M3 pan x 10mm
  2 Washer  M3 x 7mm x 0.5mm

Assemblies:
  1 SSNvB_battery_cable_clamp_assembly
  1 SSNvB_battery_frame_assembly

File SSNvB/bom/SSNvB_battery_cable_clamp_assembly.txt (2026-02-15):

SSNvB_battery_cable_clamp_assembly:
Vitamins:
  2 Nut M3 x 2.4mm 

Printed:
  1 SSNvB_battery_cable_clamp.stl

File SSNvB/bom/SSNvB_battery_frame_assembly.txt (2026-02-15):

SSNvB_battery_frame_assembly:
Printed:
  1 SSNvB_battery_frame_part1.stl
  1 SSNvB_battery_frame_part2.stl

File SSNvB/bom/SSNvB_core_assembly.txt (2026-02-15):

SSNvB_core_assembly:

Assemblies:
  1 SSNvB_antenna_assembly
  1 SSNvB_battery_assembly
  1 SSNvB_radio_assembly

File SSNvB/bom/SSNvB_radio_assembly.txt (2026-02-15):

SSNvB_radio_assembly:
Vitamins:
  1 Heltec T144

Assemblies:
  1 SSNvB_radio_frame_assembly

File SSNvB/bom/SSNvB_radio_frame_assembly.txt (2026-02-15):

SSNvB_radio_frame_assembly:
Printed:
  1 SSNvB_radio_frame_part1.stl
  1 SSNvB_radio_frame_part2.stl

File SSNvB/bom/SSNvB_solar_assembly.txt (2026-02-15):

SSNvB_solar_assembly:
Vitamins:
  3 Flexible Solar Panel 198x100mm² 6V 1W

Assemblies:
  1 SSNvB_pipe_assembly

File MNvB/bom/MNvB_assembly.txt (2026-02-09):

MNvB_assembly:
Vitamins:
  1 Antenna 20cm LoRa Antenna
  1 Cell Samsung 25R 18650 LION
  1 Nut M6.25 x 1.8mm 
  1 Heltec T144
  1 1S 3.7V battery protection board
  2 Screw M3 dome x 10mm
  1 Washer star M6.4 x 0.6mm

Printed:
  1 MNvB_buttons.stl
  1 MNvB_uEnc.stl

Assemblies:
  1 MNvB_lEnc_assembly

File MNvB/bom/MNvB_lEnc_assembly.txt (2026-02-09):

MNvB_lEnc_assembly:
Vitamins:
  2 Nut M3 x 2.4mm 

Printed:
  1 MNvB_lEnc.stl

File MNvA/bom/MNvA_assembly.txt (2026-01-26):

MNvA_assembly:
Vitamins:
  1 Antenna 20cm LoRa Antenna
  1 Lithium-Polymer-Akku 3,7V 3000mAh
  1 Nut M6.25 x 1.8mm 
  1 Heltec T144
  2 Screw M3 dome x 10mm
  1 Washer star M6.4 x 0.6mm

Printed:
  1 MNvA_buttons.stl
  1 MNvA_uEnc.stl

Assemblies:
  1 MNvA_lEnc_assembly

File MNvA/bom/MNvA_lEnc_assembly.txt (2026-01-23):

MNvA_lEnc_assembly:
Vitamins:
  2 Nut M3 x 2.4mm 

Printed:
  1 MNvA_lEnc.stl

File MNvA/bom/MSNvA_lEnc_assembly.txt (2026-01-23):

MSNvA_lEnc_assembly:
Vitamins:
  2 Nut M3 x 2.4mm 

Printed:
  1 MNvA_lEnc.stl

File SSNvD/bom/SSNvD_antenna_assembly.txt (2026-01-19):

SSNvD_antenna_assembly:
Vitamins:
  1 Antenna with N-connector

Printed:
  1 SSNvD_antenna_top.stl

Assemblies:
  1 SSNvD_antenna_frame_assembly

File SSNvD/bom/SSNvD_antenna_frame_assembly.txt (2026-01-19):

SSNvD_antenna_frame_assembly:
Printed:
  1 SSNvD_antenna_part1.stl
  1 SSNvD_antenna_part2.stl

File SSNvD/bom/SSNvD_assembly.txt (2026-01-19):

SSNvD_assembly:
Printed:
  1 SSNvD_end_cap.stl

Assemblies:
  1 SSNvD_pole_assembly
  1 SSNvD_solar_mount_assembly
  2 SSNvD_spacer_assemblies
  1 SSNvD_top_assembly

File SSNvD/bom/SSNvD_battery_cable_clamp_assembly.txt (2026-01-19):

SSNvD_battery_cable_clamp_assembly:
Vitamins:
  2 Nut M3 x 2.4mm 

Printed:
  1 SSNvD_battery_cable_clamp.stl

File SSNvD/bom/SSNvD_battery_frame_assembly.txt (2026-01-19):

SSNvD_battery_frame_assembly:
Printed:
  1 SSNvD_battery_frame_part1.stl
  1 SSNvD_battery_frame_part2.stl

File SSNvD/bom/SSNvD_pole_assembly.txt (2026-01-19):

SSNvD_pole_assembly:
Vitamins:
  1 Conduit diameter 40mmlength 300mm

Printed:
  1 SSNvD_end_cap_ring.stl

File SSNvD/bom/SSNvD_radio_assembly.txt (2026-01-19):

SSNvD_radio_assembly:
Vitamins:
  1 Heltec T144

Assemblies:
  1 SSNvD_radio_frame_assembly

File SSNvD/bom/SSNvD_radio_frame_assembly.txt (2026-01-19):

SSNvD_radio_frame_assembly:
Printed:
  1 SSNvD_radio_frame_part1.stl
  1 SSNvD_radio_frame_part2.stl

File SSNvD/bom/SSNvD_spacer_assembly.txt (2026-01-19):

SSNvD_spacer_assemblies:
Vitamins:
  2 Ziptie 3.6mm x 197mm min length

Printed:
  2 SSNvD_spacer.stl

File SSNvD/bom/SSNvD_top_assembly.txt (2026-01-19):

SSNvD_top_assembly:

Assemblies:
  1 SSNvD_antenna_assembly
  1 SSNvD_battery_assembly
  1 SSNvD_radio_assembly

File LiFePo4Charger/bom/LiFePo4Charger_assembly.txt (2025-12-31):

LiFePo4Charger_assembly:
Vitamins:
  1 Li-Ion/LiFePo4 32700 3.2v
  1 Battery negative contact
  1 Battery positive contact
  2 Nut M3 x 2.4mm 
  1 LiFePo4 USB Charger
  2 Screw M3 dome x 20mm

Printed:
  1 LiFePoCharger_frame_part1.stl
  1 LiFePoCharger_frame_part2.stl

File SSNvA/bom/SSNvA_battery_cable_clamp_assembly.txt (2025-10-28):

SSNvA_battery_cable_clamp_assemblies:
Vitamins:
  4 Nut M3 x 2.4mm 

Printed:
  2 SSNvA_battery_cable_clamp.stl

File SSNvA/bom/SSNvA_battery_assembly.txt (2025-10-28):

SSNvA_battery_assembly:
Vitamins:
  1 Li-Ion/LiFePo4 32700 3.2v
  1 Battery negative contact
  1 Battery positive contact
  1 Nut M6 x 5mm 
  1 1S 3.2V battery protection board
  1 MPPT Solar Charge Controller
  2 Screw M3 pan x 12mm
  2 Screw M3 pan x 18mm
  1 Screw M6 hex x 50mm
  4 Washer  M3 x 7mm x 0.5mm

Printed:
  2 SSNvA_battery_screw_handle.stl

Assemblies:
  2 SSNvA_battery_cable_clamp_assemblies
  1 SSNvA_battery_frame_assembly

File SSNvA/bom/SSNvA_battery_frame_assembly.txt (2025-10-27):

SSNvA_battery_frame_assembly:
Printed:
  1 SSNvA_battery_frame_part1.stl
  1 SSNvA_battery_frame_part2.stl

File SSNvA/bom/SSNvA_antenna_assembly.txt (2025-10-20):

SSNvA_antenna_assembly:
Vitamins:
  1 Antenna with N-connector

Printed:
  1 SSNvA_antenna_top.stl

Assemblies:
  1 SSNvA_antenna_frame_assembly

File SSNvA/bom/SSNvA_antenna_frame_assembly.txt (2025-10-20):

SSNvA_antenna_frame_assembly:
Printed:
  1 SSNvA_antenna_part1.stl
  1 SSNvA_antenna_part2.stl

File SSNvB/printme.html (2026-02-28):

# LoRaMeshNodes

Main Assembly

## Table of Contents

1. Parts list
2. SSNvB Pipe Assembly
3. SSNvB Solar Assembly
4. SSNvB Battery Cable Clamp Assembly
5. SSNvB Battery Frame Assembly
6. SSNvB Battery Assembly
7. SSNvB Radio Frame Assembly
8. SSNvB Radio Assembly
9. SSNvB Antenna Assembly
10. SSNvB Core Assembly
11. SSNvB Assembly

## Parts list

SSNvB Pipe | SSNvB Solar | SSNvB Battery Cable Clamp | SSNvB Battery Frame | SSNvB Battery | SSNvB Radio Frame | SSNvB Radio | SSNvB Antenna | SSNvB Core | SSNvB | TOTALS
| | | | | | | | | | | Vitamins
. | . | . | . | 1 | . | . | . | . | . | 1 | 1S 3.2V battery protection board
. | . | . | . | . | . | . | 1 | . | . | 1 | Antenna with N-connector
. | . | . | . | 1 | . | . | . | . | . | 1 | Battery negative contact
. | . | . | . | 1 | . | . | . | . | . | 1 | Battery positive contact
1 | . | . | . | . | . | . | . | . | . | 1 | Conduit diameter 40mmlength 470mm
. | 3 | . | . | . | . | . | . | . | . | 3 | Flexible Solar Panel 198x100mm² 6V 1W
. | . | . | . | . | . | 1 | . | . | . | 1 | Heltec T144
. | . | . | . | 1 | . | . | . | . | . | 1 | Li-Ion/LiFePo4 32700 3.2v
. | . | . | . | 1 | . | . | . | . | . | 1 | MPPT Solar Charge Controller
. | . | 2 | . | . | . | . | . | . | . | 2 | Nut M3 x 2.4mm
. | . | . | . | 2 | . | . | . | . | . | 2 | Screw M3 pan x 10mm
. | . | . | . | 2 | . | . | . | . | . | 2 | Washer M3 x 7mm x 0.5mm
1 | 3 | 2 | . | 9 | . | 1 | 1 | . | . | 17 | Total vitamins count
| | | | | | | | | | | 3D printed parts
2 | . | . | . | . | . | . | . | . | . | 2 | SSNvB_EndcapThread.stl
1 | . | . | . | . | . | . | . | . | . | 1 | SSNvB_LIEncMount.stl
1 | . | . | . | . | . | . | . | . | . | 1 | SSNvB_LOEncMount.stl
1 | . | . | . | . | . | . | . | . | . | 1 | SSNvB_UIEncMount.stl
1 | . | . | . | . | . | . | . | . | . | 1 | SSNvB_UOEncMount.stl
. | . | . | . | . | . | . | 1 | . | . | 1 | SSNvB_antenna.stl
. | . | . | . | . | . | . | . | . | 1 | 1 | SSNvB_antennaMountFastener.stl
1 | . | . | . | . | . | . | . | . | . | 1 | SSNvB_antennaMountThread.stl
. | . | 1 | . | . | . | . | . | . | . | 1 | SSNvB_battery_cable_clamp.stl
. | . | . | 1 | . | . | . | . | . | . | 1 | SSNvB_battery_frame_part1.stl
. | . | . | 1 | . | . | . | . | . | . | 1 | SSNvB_battery_frame_part2.stl
. | . | . | . | . | . | . | . | . | 1 | 1 | SSNvB_lEndcap.stl
. | . | . | . | . | 1 | . | . | . | . | 1 | SSNvB_radio_frame_part1.stl
. | . | . | . | . | 1 | . | . | . | . | 1 | SSNvB_radio_frame_part2.stl
. | . | . | . | . | . | . | . | . | 1 | 1 | SSNvB_uEndcap.stl
7 | . | 1 | 2 | . | 2 | . | 1 | . | 3 | 16 | Total 3D printed parts count

## SSNvB Pipe Assembly

### Vitamins

Qty | Description
1 | Conduit diameter 40mmlength 470mm

### 3D Printed parts

2 x SSNvB_EndcapThread.stl | 1 x SSNvB_LIEncMount.stl | 1 x SSNvB_LOEncMount.stl
SSNvB_EndcapThread.stl | SSNvB_LIEncMount.stl | SSNvB_LOEncMount.stl

1 x SSNvB_UIEncMount.stl | 1 x SSNvB_UOEncMount.stl | 1 x SSNvB_antennaMountThread.stl
SSNvB_UIEncMount.stl | SSNvB_UOEncMount.stl | SSNvB_antennaMountThread.stl

### Assembly instructions

SSNvB_pipe_assembly

1. Cut the DN75 pipe to the desired length
2. Drill 10mm holes for the solar panel connectors
3. Glue in the antenna holder and the two end cap threads
4. Glue on enclosure mount

SSNvB_pipe_assembled

## SSNvB Solar Assembly

### Vitamins

Qty | Description
3 | Flexible Solar Panel 198x100mm² 6V 1W

### Sub-assemblies

1 x SSNvB_pipe_assembly

SSNvB_pipe_assembled

### Assembly instructions

SSNvB_solar_assembly

1. Solder wires onto the solar panels terminals
2. Glue solar panels around the pipe

SSNvB_solar_assembled

## SSNvB Battery Cable Clamp Assembly

### Vitamins

Qty | Description
2 | Nut M3 x 2.4mm

### 3D Printed parts

1 x SSNvB_battery_cable_clamp.stl

SSNvB_battery_cable_clamp.stl

### Assembly instructions

SSNvB_battery_cable_clamp_assembly

Insert two M3 waschers into the cable clamp

SSNvB_battery_cable_clamp_assembled

## SSNvB Battery Frame Assembly

### 3D Printed parts

1 x SSNvB_battery_frame_part1.stl | 1 x SSNvB_battery_frame_part2.stl
SSNvB_battery_frame_part1.stl | SSNvB_battery_frame_part2.stl

### Assembly instructions

SSNvB_battery_frame_assembly

Glue the two pieces of the frame together

SSNvB_battery_frame_assembled

## SSNvB Battery Assembly

### Vitamins

Qty | Description
1 | 1S 3.2V battery protection board
1 | Battery negative contact
1 | Battery positive contact
1 | Li-Ion/LiFePo4 32700 3.2v
1 | MPPT Solar Charge Controller
2 | Screw M3 pan x 10mm
2 | Washer M3 x 7mm x 0.5mm

### Sub-assemblies

1 x SSNvB_battery_cable_clamp_assembly | 1 x SSNvB_battery_frame_assembly
SSNvB_battery_cable_clamp_assembled | SSNvB_battery_frame_assembled

### Assembly instructions

SSNvB_battery_assembly

Solder and assemble components

SSNvB_battery_assembled

## SSNvB Radio Frame Assembly

### 3D Printed parts

1 x SSNvB_radio_frame_part1.stl | 1 x SSNvB_radio_frame_part2.stl
SSNvB_radio_frame_part1.stl | SSNvB_radio_frame_part2.stl

### Assembly instructions

SSNvB_radio_frame_assembly

1. Glue the two parts of the radio frame together

SSNvB_radio_frame_assembled

## SSNvB Radio Assembly

### Vitamins

Qty | Description
1 | Heltec T144

### Sub-assemblies

1 x SSNvB_radio_frame_assembly

SSNvB_radio_frame_assembled

### Assembly instructions

SSNvB_radio_assembly

1. Attach the cable clamp with two M3 screws
2. Insert the Heltec T114
3. Attach the power cable
4. Tighten cable clamp

SSNvB_radio_assembled

## SSNvB Antenna Assembly

### Vitamins

Qty | Description
1 | Antenna with N-connector

### 3D Printed parts

1 x SSNvB_antenna.stl

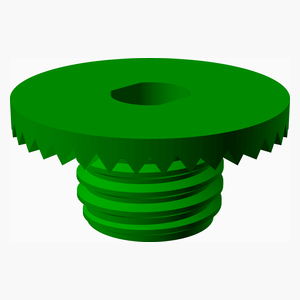
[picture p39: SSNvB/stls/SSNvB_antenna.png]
SSNvB_antenna.stl


### Assembly instructions

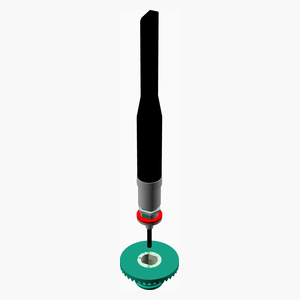
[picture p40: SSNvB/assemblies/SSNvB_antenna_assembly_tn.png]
SSNvB_antenna_assembly


1. Attach the antenna to the frame.

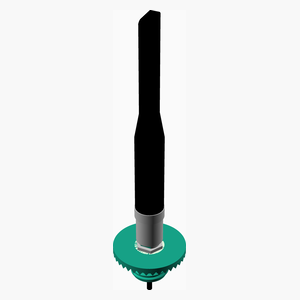
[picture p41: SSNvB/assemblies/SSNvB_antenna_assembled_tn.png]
SSNvB_antenna_assembled


## SSNvB Core Assembly

### Sub-assemblies

1 x SSNvB_antenna_assembly | 1 x SSNvB_battery_assembly | 1 x SSNvB_radio_assembly
SSNvB_antenna_assembled | SSNvB_battery_assembled | SSNvB_radio_assembled

### Assembly instructions

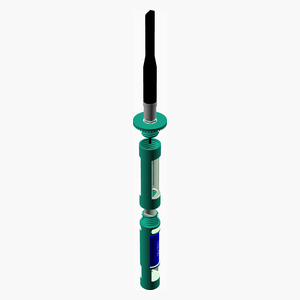
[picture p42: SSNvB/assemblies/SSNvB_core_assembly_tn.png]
SSNvB_core_assembly


1. Attach antenna, radio and battery frame

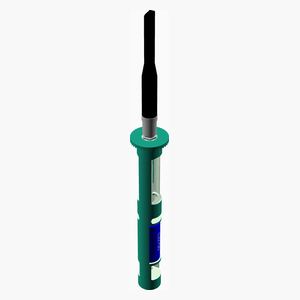
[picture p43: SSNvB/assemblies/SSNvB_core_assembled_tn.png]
SSNvB_core_assembled


## SSNvB Assembly

### 3D Printed parts

1 x SSNvB_antennaMountFastener.stl | 1 x SSNvB_lEndcap.stl | 1 x SSNvB_uEndcap.stl
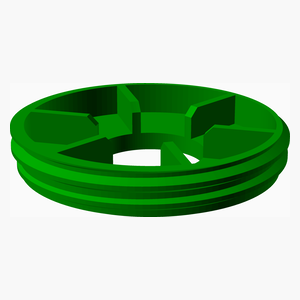
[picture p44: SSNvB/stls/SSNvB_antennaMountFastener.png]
SSNvB_antennaMountFastener.stl
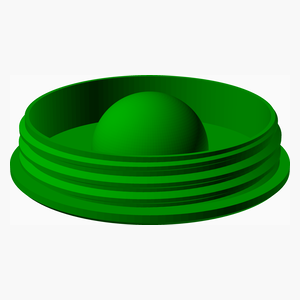
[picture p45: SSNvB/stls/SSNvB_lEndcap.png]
SSNvB_lEndcap.stl
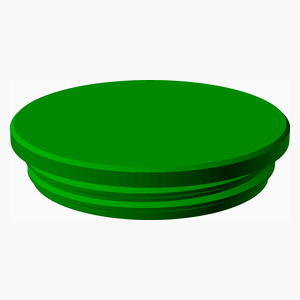
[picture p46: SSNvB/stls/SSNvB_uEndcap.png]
SSNvB_uEndcap.stl
 |  | 

### Sub-assemblies

1 x SSNvB_core_assembly | 1 x SSNvB_solar_assembly
SSNvB_core_assembled | SSNvB_solar_assembled

### Assembly instructions

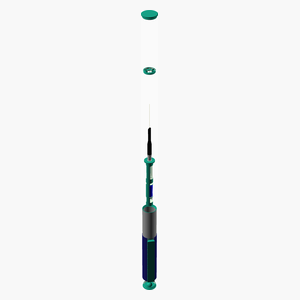
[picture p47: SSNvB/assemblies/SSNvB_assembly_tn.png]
SSNvB_assembly


1. Slide the antenna and radio into the top end of the pole
2. Screw in antenna fastener
3. Attach the power cable of the antenna to the MPPT controller
4. Attach the end caps

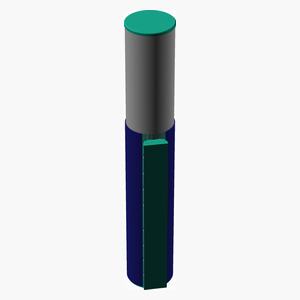
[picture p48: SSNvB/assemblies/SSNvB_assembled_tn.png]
SSNvB_assembled


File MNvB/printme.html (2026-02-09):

# LoRaMeshNodes

These are the assembly instructions for the Mobile Node (Variant A) (MNvA), a portable Meshtastic (https://meshtastic.org) or MeshCore (https://meshcore.co.uk) node.

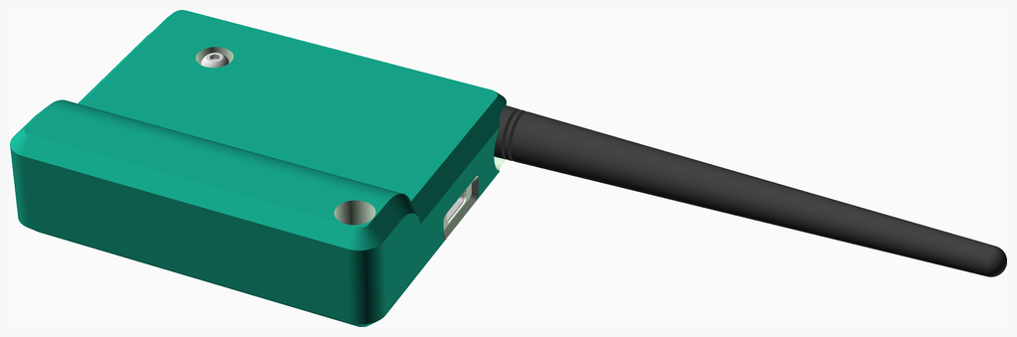
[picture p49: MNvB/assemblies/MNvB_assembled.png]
Main Assembly


## Table of Contents

1. Parts list
2. MNvB LEnc Assembly
3. MNvB Assembly

## Parts list

MNvB LEnc | MNvB | TOTALS
| | | Vitamins
. | 1 | 1 | 1S 3.7V battery protection board
. | 1 | 1 | Antenna 20cm LoRa Antenna
. | 1 | 1 | Cell Samsung 25R 18650 LION
. | 1 | 1 | Heltec T144
2 | . | 2 | Nut M3 x 2.4mm
. | 1 | 1 | Nut M6.25 x 1.8mm
. | 2 | 2 | Screw M3 dome x 10mm
. | 1 | 1 | Washer star M6.4 x 0.6mm
2 | 8 | 10 | Total vitamins count
| | | 3D printed parts
. | 1 | 1 | MNvB_buttons.stl
1 | . | 1 | MNvB_lEnc.stl
. | 1 | 1 | MNvB_uEnc.stl
1 | 2 | 3 | Total 3D printed parts count

## MNvB LEnc Assembly

### Vitamins

Qty | Description
2 | Nut M3 x 2.4mm

### 3D Printed parts

1 x MNvB_lEnc.stl

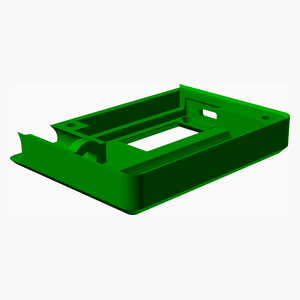
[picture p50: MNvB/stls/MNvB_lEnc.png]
MNvB_lEnc.stl


### Assembly instructions

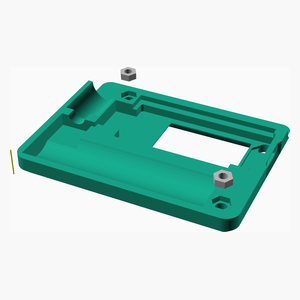
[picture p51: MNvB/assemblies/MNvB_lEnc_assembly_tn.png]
MNvB_lEnc_assembly


Insert nuts during print

MNvB_lEnc_assembled

## MNvB Assembly

### Vitamins

Qty | Description
1 | 1S 3.7V battery protection board
1 | Antenna 20cm LoRa Antenna
1 | Cell Samsung 25R 18650 LION
1 | Heltec T144
1 | Nut M6.25 x 1.8mm
2 | Screw M3 dome x 10mm
1 | Washer star M6.4 x 0.6mm

### 3D Printed parts

1 x MNvB_buttons.stl | 1 x MNvB_uEnc.stl
MNvB_buttons.stl | MNvB_uEnc.stl

### Sub-assemblies

1 x MNvB_lEnc_assembly

MNvB_lEnc_assembled

### Assembly instructions

MNvB_assembly

Insert components, attach top and fasten screws.

MNvB_assembled

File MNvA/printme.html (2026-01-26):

# LoRaMeshNodes

These are the assembly instructions for the Mobile Node (Variant A) (MNvA), a portable Meshtastic (https://meshtastic.org) or MeshCore (https://meshcore.co.uk) node.

Main Assembly

## Table of Contents

1. Parts list
2. MNvA LEnc Assembly
3. MNvA Assembly

## Parts list

MNvA LEnc | MNvA | TOTALS
| | | Vitamins
. | 1 | 1 | Antenna 20cm LoRa Antenna
. | 1 | 1 | Heltec T144
. | 1 | 1 | Lithium-Polymer-Akku 3,7V 3000mAh
2 | . | 2 | Nut M3 x 2.4mm
. | 1 | 1 | Nut M6.25 x 1.8mm
. | 2 | 2 | Screw M3 dome x 10mm
. | 1 | 1 | Washer star M6.4 x 0.6mm
2 | 7 | 9 | Total vitamins count
| | | 3D printed parts
. | 1 | 1 | MNvA_buttons.stl
1 | . | 1 | MNvA_lEnc.stl
. | 1 | 1 | MNvA_uEnc.stl
1 | 2 | 3 | Total 3D printed parts count

## MNvA LEnc Assembly

### Vitamins

Qty | Description
2 | Nut M3 x 2.4mm

### 3D Printed parts

1 x MNvA_lEnc.stl

MNvA_lEnc.stl

### Assembly instructions

MNvA_lEnc_assembly

Insert nuts during print

MNvA_lEnc_assembled

## MNvA Assembly

### Vitamins

Qty | Description
1 | Antenna 20cm LoRa Antenna
1 | Heltec T144
1 | Lithium-Polymer-Akku 3,7V 3000mAh
1 | Nut M6.25 x 1.8mm
2 | Screw M3 dome x 10mm
1 | Washer star M6.4 x 0.6mm

### 3D Printed parts

1 x MNvA_buttons.stl | 1 x MNvA_uEnc.stl
MNvA_buttons.stl | MNvA_uEnc.stl

### Sub-assemblies

1 x MNvA_lEnc_assembly

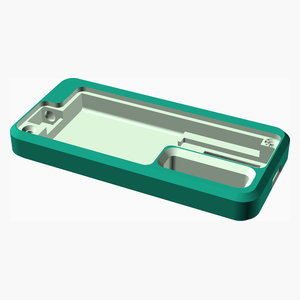
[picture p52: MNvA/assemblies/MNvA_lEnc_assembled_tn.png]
MNvA_lEnc_assembled


### Assembly instructions

MNvA_assembly

Insert components, attach top and fasten screws.

MNvA_assembled

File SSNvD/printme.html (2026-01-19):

# LoRaMeshNodes

Main Assembly

## Table of Contents

1. Parts list
2. SSNvD Spacer Assembly
3. SSNvD Solar Mount Assembly
4. SSNvD Battery Cable Clamp Assembly
5. SSNvD Battery Frame Assembly
6. SSNvD Battery Assembly
7. SSNvD Radio Frame Assembly
8. SSNvD Radio Assembly
9. SSNvD Antenna Frame Assembly
10. SSNvD Antenna Assembly
11. SSNvD Top Assembly
12. SSNvD Pole Assembly
13. SSNvD Assembly

## Parts list

2 x SSNvD Spacer | SSNvD Solar Mount | SSNvD Battery Cable Clamp | SSNvD Battery Frame | SSNvD Battery | SSNvD Radio Frame | SSNvD Radio | SSNvD Antenna Frame | SSNvD Antenna | SSNvD Top | SSNvD Pole | SSNvD | TOTALS
| | | | | | | | | | | | | Vitamins
. | . | . | . | 1 | . | . | . | . | . | . | . | 1 | 1S 3.2V battery protection board
. | . | . | . | . | . | . | . | 1 | . | . | . | 1 | Antenna with N-connector
. | . | . | . | 1 | . | . | . | . | . | . | . | 1 | Battery negative contact
. | . | . | . | 1 | . | . | . | . | . | . | . | 1 | Battery positive contact
. | . | . | . | . | . | . | . | . | . | 1 | . | 1 | Conduit diameter 40mmlength 300mm
. | . | . | . | . | . | 1 | . | . | . | . | . | 1 | Heltec T144
. | . | . | . | 1 | . | . | . | . | . | . | . | 1 | Li-Ion/LiFePo4 32700 3.2v
. | . | . | . | 1 | . | . | . | . | . | . | . | 1 | MPPT Solar Charge Controller
. | . | 2 | . | . | . | . | . | . | . | . | . | 2 | Nut M3 x 2.4mm
. | 3 | . | . | . | . | . | . | . | . | . | . | 3 | Nut M4 x 3.2mm
. | . | . | . | 2 | . | . | . | . | . | . | . | 2 | Screw M3 pan x 10mm
. | 3 | . | . | . | . | . | . | . | . | . | . | 3 | Screw M4 pan x 16mm
. | . | . | . | 2 | . | . | . | . | . | . | . | 2 | Washer M3 x 7mm x 0.5mm
. | 3 | . | . | . | . | . | . | . | . | . | . | 3 | Washer M4 x 9mm x 0.8mm
. | 2 | . | . | . | . | . | . | . | . | . | . | 2 | Ziptie 3.6mm x 178mm min length
2 | . | . | . | . | . | . | . | . | . | . | . | 2 | Ziptie 3.6mm x 197mm min length
2 | 11 | 2 | . | 9 | . | 1 | . | 1 | . | 1 | . | 27 | Total vitamins count
| | | | | | | | | | | | | 3D printed parts
. | . | . | . | . | . | . | 1 | . | . | . | . | 1 | SSNvD_antenna_part1.stl
. | . | . | . | . | . | . | 1 | . | . | . | . | 1 | SSNvD_antenna_part2.stl
. | . | . | . | . | . | . | . | 1 | . | . | . | 1 | SSNvD_antenna_top.stl
. | . | 1 | . | . | . | . | . | . | . | . | . | 1 | SSNvD_battery_cable_clamp.stl
. | . | . | 1 | . | . | . | . | . | . | . | . | 1 | SSNvD_battery_frame_part1.stl
. | . | . | 1 | . | . | . | . | . | . | . | . | 1 | SSNvD_battery_frame_part2.stl
. | . | . | . | . | . | . | . | . | . | . | 1 | 1 | SSNvD_end_cap.stl
. | . | . | . | . | . | . | . | . | . | 1 | . | 1 | SSNvD_end_cap_ring.stl
. | . | . | . | . | 1 | . | . | . | . | . | . | 1 | SSNvD_radio_frame_part1.stl
. | . | . | . | . | 1 | . | . | . | . | . | . | 1 | SSNvD_radio_frame_part2.stl
. | 1 | . | . | . | . | . | . | . | . | . | . | 1 | SSNvD_solar_mount.stl
2 | . | . | . | . | . | . | . | . | . | . | . | 2 | SSNvD_spacer.stl
2 | 1 | 1 | 2 | . | 2 | . | 2 | 1 | . | 1 | 1 | 13 | Total 3D printed parts count

## 2 x SSNvD Spacer Assembly

### Vitamins

Qty | Description
2 | Ziptie 3.6mm x 197mm min length

### 3D Printed parts

2 x SSNvD_spacer.stl

SSNvD_spacer.stl

### Assembly instructions

SSNvD_spacer_assembly

1. Insert spacer when mounting the router with zipties

SSNvD_spacer_assembled

## SSNvD Solar Mount Assembly

### Vitamins

Qty | Description
3 | Nut M4 x 3.2mm
3 | Screw M4 pan x 16mm
3 | Washer M4 x 9mm x 0.8mm
2 | Ziptie 3.6mm x 178mm min length

### 3D Printed parts

1 x SSNvD_solar_mount.stl

SSNvD_solar_mount.stl

### Assembly instructions

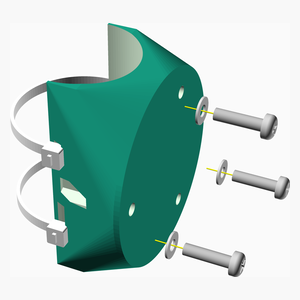
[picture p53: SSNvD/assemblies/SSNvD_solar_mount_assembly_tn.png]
SSNvD_solar_mount_assembly


1. Inset M4 nuts
2. Attach solar penel
3. Insert zipties

SSNvD_solar_mount_assembled

## SSNvD Battery Cable Clamp Assembly

### Vitamins

Qty | Description
2 | Nut M3 x 2.4mm

### 3D Printed parts

1 x SSNvD_battery_cable_clamp.stl

SSNvD_battery_cable_clamp.stl

### Assembly instructions

SSNvD_battery_cable_clamp_assembly

Insert two M3 waschers into the cable clamp

SSNvD_battery_cable_clamp_assembled

## SSNvD Battery Frame Assembly

### 3D Printed parts

1 x SSNvD_battery_frame_part1.stl | 1 x SSNvD_battery_frame_part2.stl
SSNvD_battery_frame_part1.stl | SSNvD_battery_frame_part2.stl

### Assembly instructions

SSNvD_battery_frame_assembly

Glue the two pieces of the frame together

SSNvD_battery_frame_assembled

## SSNvD Battery Assembly

### Vitamins

Qty | Description
1 | 1S 3.2V battery protection board
1 | Battery negative contact
1 | Battery positive contact
1 | Li-Ion/LiFePo4 32700 3.2v
1 | MPPT Solar Charge Controller
2 | Screw M3 pan x 10mm
2 | Washer M3 x 7mm x 0.5mm

### Sub-assemblies

1 x SSNvD_battery_cable_clamp_assembly | 1 x SSNvD_battery_frame_assembly
SSNvD_battery_cable_clamp_assembled | SSNvD_battery_frame_assembled

### Assembly instructions

SSNvD_battery_assembly

Solder and assemble components

SSNvD_battery_assembled

## SSNvD Radio Frame Assembly

### 3D Printed parts

1 x SSNvD_radio_frame_part1.stl | 1 x SSNvD_radio_frame_part2.stl
SSNvD_radio_frame_part1.stl | SSNvD_radio_frame_part2.stl

### Assembly instructions

SSNvD_radio_frame_assembly

1. Glue the two parts of the radio frame together

SSNvD_radio_frame_assembled

## SSNvD Radio Assembly

### Vitamins

Qty | Description
1 | Heltec T144

### Sub-assemblies

1 x SSNvD_radio_frame_assembly

SSNvD_radio_frame_assembled

### Assembly instructions

SSNvD_radio_assembly

1. Attach the cable clamp with two M3 screws
2. Insert the Heltec T114
3. Attach the power cable
4. Tighten cable clamp

SSNvD_radio_assembled

## SSNvD Antenna Frame Assembly

### 3D Printed parts

1 x SSNvD_antenna_part1.stl | 1 x SSNvD_antenna_part2.stl
SSNvD_antenna_part1.stl | SSNvD_antenna_part2.stl

### Assembly instructions

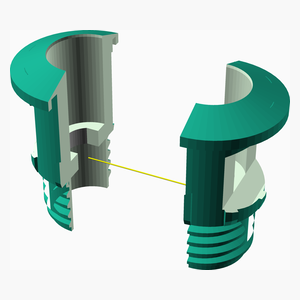
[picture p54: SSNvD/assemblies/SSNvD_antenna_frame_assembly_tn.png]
SSNvD_antenna_frame_assembly


1. Glue the two parts of the antenna frame together

SSNvD_antenna_frame_assembled

## SSNvD Antenna Assembly

### Vitamins

Qty | Description
1 | Antenna with N-connector

### 3D Printed parts

1 x SSNvD_antenna_top.stl

SSNvD_antenna_top.stl

### Sub-assemblies

1 x SSNvD_antenna_frame_assembly

SSNvD_antenna_frame_assembled

### Assembly instructions

SSNvD_antenna_assembly

1. Attach the antenna to the frame.
2. Wrap teflon tape around the bottom of the antenna rod.
3. Push the top cover over the antenna.

SSNvD_antenna_assembled

## SSNvD Top Assembly

### Sub-assemblies

1 x SSNvD_antenna_assembly | 1 x SSNvD_battery_assembly | 1 x SSNvD_radio_assembly
SSNvD_antenna_assembled | SSNvD_battery_assembled | SSNvD_radio_assembled

### Assembly instructions

SSNvD_top_assembly

SSNvD_top_assembled

## SSNvD Pole Assembly

### Vitamins

Qty | Description
1 | Conduit diameter 40mmlength 300mm

### 3D Printed parts

1 x SSNvD_end_cap_ring.stl

SSNvD_end_cap_ring.stl

### Assembly instructions

SSNvD_pole_assembly

1. Cut the M40 counduit to the desired length (mun. 30cm)
2. Glue the end cap ring into the bottom of the conduit

SSNvD_pole_assembled

## SSNvD Assembly

### 3D Printed parts

1 x SSNvD_end_cap.stl

SSNvD_end_cap.stl

### Sub-assemblies

1 x SSNvD_pole_assembly | 1 x SSNvD_solar_mount_assembly | 2 x SSNvD_spacer_assembly
SSNvD_pole_assembled | SSNvD_solar_mount_assembled | SSNvD_spacer_assembled

1 x SSNvD_top_assembly

SSNvD_top_assembled

### Assembly instructions

SSNvD_assembly

1. Slide the antenna and radio into the top end of the pole
2. Attach the power cable of the antenna to the battery assembly
3. Slide the battery assembly into the bottom end of the pole
4. Attach the solar panel to the MPPT controller
5. Attach the panel to the panel mount
6. Attach the panel mount to the pole with zipties

SSNvD_assembled

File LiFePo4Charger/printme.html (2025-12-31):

# LoRaMeshNodes

Main Assembly

## Table of Contents

1. Parts list
2. LiFePo4Charger Assembly

## Parts list

LiFePo4Charger | TOTALS
| | Vitamins
1 | 1 | Battery negative contact
1 | 1 | Battery positive contact
1 | 1 | Li-Ion/LiFePo4 32700 3.2v
1 | 1 | LiFePo4 USB Charger
2 | 2 | Nut M3 x 2.4mm
2 | 2 | Screw M3 dome x 20mm
8 | 8 | Total vitamins count
| | 3D printed parts
1 | 1 | LiFePoCharger_frame_part1.stl
1 | 1 | LiFePoCharger_frame_part2.stl
2 | 2 | Total 3D printed parts count

## LiFePo4Charger Assembly

### Vitamins

Qty | Description
1 | Battery negative contact
1 | Battery positive contact
1 | Li-Ion/LiFePo4 32700 3.2v
1 | LiFePo4 USB Charger
2 | Nut M3 x 2.4mm
2 | Screw M3 dome x 20mm

### 3D Printed parts

1 x LiFePoCharger_frame_part1.stl | 1 x LiFePoCharger_frame_part2.stl
LiFePoCharger_frame_part1.stl | LiFePoCharger_frame_part2.stl

### Assembly instructions

LiFePo4Charger_assembly

Assemble as shown

LiFePo4Charger_assembled

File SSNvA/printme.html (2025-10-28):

# LoRaMeshNodes

Main Assembly

## Table of Contents

1. Parts list
2. SSNvA Solar Mount Assembly
3. SSNvA Battery Cable Clamp Assembly
4. SSNvA Battery Frame Assembly
5. SSNvA Battery Assembly
6. SSNvA Radio Frame Assembly
7. SSNvA Radio Assembly
8. SSNvA Antenna Frame Assembly
9. SSNvA Antenna Assembly
10. SSNvA Top Assembly
11. SSNvA Pole Assembly
12. SSNvA Assembly

## Parts list

SSNvA Solar Mount | 2 x SSNvA Battery Cable Clamp | SSNvA Battery Frame | SSNvA Battery | SSNvA Radio Frame | SSNvA Radio | SSNvA Antenna Frame | SSNvA Antenna | SSNvA Top | SSNvA Pole | SSNvA | TOTALS
| | | | | | | | | | | | Vitamins
. | . | . | 1 | . | . | . | . | . | . | . | 1 | 1S 3.2V battery protection board
. | . | . | . | . | . | . | 1 | . | . | . | 1 | Antenna with N-connector
. | . | . | 1 | . | . | . | . | . | . | . | 1 | Battery negative contact
. | . | . | 1 | . | . | . | . | . | . | . | 1 | Battery positive contact
. | . | . | . | . | . | . | . | . | 1 | . | 1 | Conduit diameter 40mmlength 2000mm
. | . | . | . | . | 1 | . | . | . | . | . | 1 | Heltec T144
. | . | . | 1 | . | . | . | . | . | . | . | 1 | Li-Ion/LiFePo4 32700 3.2v
. | . | . | 1 | . | . | . | . | . | . | . | 1 | MPPT Solar Charge Controller
. | 4 | . | . | . | 2 | . | . | . | . | . | 6 | Nut M3 x 2.4mm
3 | . | . | . | . | . | . | . | . | . | . | 3 | Nut M4 x 3.2mm
. | . | . | 1 | . | . | . | . | . | . | . | 1 | Nut M6 x 5mm
. | . | . | 2 | . | . | . | . | . | . | . | 2 | Screw M3 pan x 12mm
. | . | . | . | . | 2 | . | . | . | . | . | 2 | Screw M3 pan x 16mm
. | . | . | 2 | . | . | . | . | . | . | . | 2 | Screw M3 pan x 18mm
3 | . | . | . | . | . | . | . | . | . | . | 3 | Screw M4 pan x 16mm
. | . | . | 1 | . | . | . | . | . | . | . | 1 | Screw M6 hex x 50mm
. | . | . | 4 | . | 2 | . | . | . | . | . | 6 | Washer M3 x 7mm x 0.5mm
3 | . | . | . | . | . | . | . | . | . | . | 3 | Washer M4 x 9mm x 0.8mm
2 | . | . | . | . | . | . | . | . | . | . | 2 | Ziptie 3.6mm x 178mm min length
11 | 4 | . | 15 | . | 7 | . | 1 | . | 1 | . | 39 | Total vitamins count
| | | | | | | | | | | | 3D printed parts
. | . | . | . | . | . | 1 | . | . | . | . | 1 | SSNvA_antenna_part1.stl
. | . | . | . | . | . | 1 | . | . | . | . | 1 | SSNvA_antenna_part2.stl
. | . | . | . | . | . | . | 1 | . | . | . | 1 | SSNvA_antenna_top.stl
. | 2 | . | . | . | . | . | . | . | . | . | 2 | SSNvA_battery_cable_clamp.stl
. | . | 1 | . | . | . | . | . | . | . | . | 1 | SSNvA_battery_frame_part1.stl
. | . | 1 | . | . | . | . | . | . | . | . | 1 | SSNvA_battery_frame_part2.stl
. | . | . | 2 | . | . | . | . | . | . | . | 2 | SSNvA_battery_screw_handle.stl
. | . | . | . | . | 1 | . | . | . | . | . | 1 | SSNvA_cable_clamp.stl
. | . | . | . | 1 | . | . | . | . | . | . | 1 | SSNvA_radio_frame_part1.stl
. | . | . | . | 1 | . | . | . | . | . | . | 1 | SSNvA_radio_frame_part2.stl
. | . | . | . | . | . | . | . | . | 2 | . | 2 | SSNvA_scrutonM40.stl
1 | . | . | . | . | . | . | . | . | . | . | 1 | SSNvA_solar_mount.stl
1 | 2 | 2 | 2 | 2 | 1 | 2 | 1 | . | 2 | . | 15 | Total 3D printed parts count

## SSNvA Solar Mount Assembly

### Vitamins

Qty | Description
3 | Nut M4 x 3.2mm
3 | Screw M4 pan x 16mm
3 | Washer M4 x 9mm x 0.8mm
2 | Ziptie 3.6mm x 178mm min length

### 3D Printed parts

1 x SSNvA_solar_mount.stl

SSNvA_solar_mount.stl

### Assembly instructions

SSNvA_solar_mount_assembly

1. Inset M4 nuts
2. Attach solar penel
3. Insert zipties

SSNvA_solar_mount_assembled

## 2 x SSNvA Battery Cable Clamp Assembly

### Vitamins

Qty | Description
4 | Nut M3 x 2.4mm

### 3D Printed parts

2 x SSNvA_battery_cable_clamp.stl

SSNvA_battery_cable_clamp.stl

### Assembly instructions

SSNvA_battery_cable_clamp_assembly

Insert two M3 waschers into the cable clamp

SSNvA_battery_cable_clamp_assembled

## SSNvA Battery Frame Assembly

### 3D Printed parts

1 x SSNvA_battery_frame_part1.stl | 1 x SSNvA_battery_frame_part2.stl
SSNvA_battery_frame_part1.stl | SSNvA_battery_frame_part2.stl

### Assembly instructions

SSNvA_battery_frame_assembly

Glue the two pieces of the frame together

SSNvA_battery_frame_assembled

## SSNvA Battery Assembly

### Vitamins

Qty | Description
1 | 1S 3.2V battery protection board
1 | Battery negative contact
1 | Battery positive contact
1 | Li-Ion/LiFePo4 32700 3.2v
1 | MPPT Solar Charge Controller
1 | Nut M6 x 5mm
2 | Screw M3 pan x 12mm
2 | Screw M3 pan x 18mm
1 | Screw M6 hex x 50mm
4 | Washer M3 x 7mm x 0.5mm

### 3D Printed parts

2 x SSNvA_battery_screw_handle.stl

SSNvA_battery_screw_handle.stl

### Sub-assemblies

2 x SSNvA_battery_cable_clamp_assembly | 1 x SSNvA_battery_frame_assembly
SSNvA_battery_cable_clamp_assembled | SSNvA_battery_frame_assembled

### Assembly instructions

SSNvA_battery_assembly

Solder and assemble components

SSNvA_battery_assembled

## SSNvA Radio Frame Assembly

### 3D Printed parts

1 x SSNvA_radio_frame_part1.stl | 1 x SSNvA_radio_frame_part2.stl
SSNvA_radio_frame_part1.stl | SSNvA_radio_frame_part2.stl

### Assembly instructions

SSNvA_radio_frame_assembly

1. Glue the two parts of the radio frame together

SSNvA_radio_frame_assembled

## SSNvA Radio Assembly

### Vitamins

Qty | Description
1 | Heltec T144
2 | Nut M3 x 2.4mm
2 | Screw M3 pan x 16mm
2 | Washer M3 x 7mm x 0.5mm

### 3D Printed parts

1 x SSNvA_cable_clamp.stl

SSNvA_cable_clamp.stl

### Sub-assemblies

1 x SSNvA_radio_frame_assembly

SSNvA_radio_frame_assembled

### Assembly instructions

SSNvA_radio_assembly

1. Attach the cable clamp with two M3 screws
2. Insert the Heltec T114
3. Attach the power cable
4. Tighten cable clamp

SSNvA_radio_assembled

## SSNvA Antenna Frame Assembly

### 3D Printed parts

1 x SSNvA_antenna_part1.stl | 1 x SSNvA_antenna_part2.stl
SSNvA_antenna_part1.stl | SSNvA_antenna_part2.stl

### Assembly instructions

SSNvA_antenna_frame_assembly

1. Glue the two parts of the antenna frame together

SSNvA_antenna_frame_assembled

## SSNvA Antenna Assembly

### Vitamins

Qty | Description
1 | Antenna with N-connector

### 3D Printed parts

1 x SSNvA_antenna_top.stl

SSNvA_antenna_top.stl

### Sub-assemblies

1 x SSNvA_antenna_frame_assembly

SSNvA_antenna_frame_assembled

### Assembly instructions

SSNvA_antenna_assembly

1. Attach the antenna to the frame.
2. Wrap teflon tape around the bottom of the antenna rod.
3. Push the top cover over the antenna.

SSNvA_antenna_assembled

## SSNvA Top Assembly

### Sub-assemblies

1 x SSNvA_antenna_assembly | 1 x SSNvA_radio_assembly
SSNvA_antenna_assembled | SSNvA_radio_assembled

### Assembly instructions

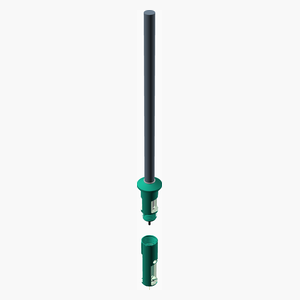
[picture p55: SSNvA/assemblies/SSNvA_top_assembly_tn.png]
SSNvA_top_assembly


SSNvA_top_assembled

## SSNvA Pole Assembly

### Vitamins

Qty | Description
1 | Conduit diameter 40mmlength 2000mm

### 3D Printed parts

2 x SSNvA_scrutonM40.stl

SSNvA_scrutonM40.stl

### Assembly instructions

SSNvA_pole_assembly

1. Cut the M40 counduit to the desired length
2. Drill a 6mm hole through the pole, approx. 10mm above the bottom end
3. Slide helix segments over the pole

SSNvA_pole_assembled

## SSNvA Assembly

### Sub-assemblies

1 x SSNvA_battery_assembly | 1 x SSNvA_pole_assembly | 1 x SSNvA_solar_mount_assembly
SSNvA_battery_assembled | SSNvA_pole_assembled | SSNvA_solar_mount_assembled

1 x SSNvA_top_assembly

SSNvA_top_assembled

### Assembly instructions

SSNvA_assembly

1. Slide the antenna and radio into the top end of the pole
2. Attach the power cable of the antenna to the battery assembly
3. Slide the battery assembly into the bottom end of the pole
4. Attach the solar panel to the MPPT controller
5. Attach the panel to the panel mount
6. Attach the panel mount to the pole with zipties

SSNvA_assembled

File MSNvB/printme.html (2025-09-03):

# LoRaMeshNodes

These are the assembly instructions for the Mobile Solar Node (Variant A) (MSNvB), a portable solar powered Meshtastic (https://meshtastic.org) or MeshCore (https://meshcore.co.uk) node.

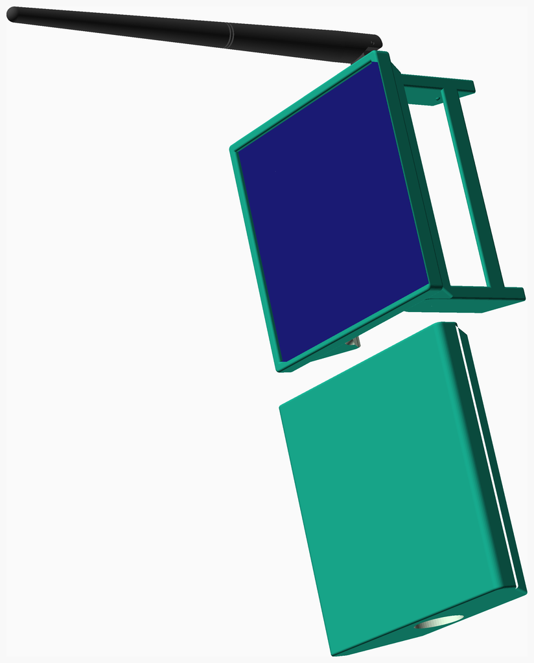
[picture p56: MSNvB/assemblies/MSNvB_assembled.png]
Main Assembly


## Table of Contents

1. Parts list
2. MSNvB LEnc Assembly
3. MSNvB Enc Assembly
4. MSNvB Assembly

## Parts list

MSNvB LEnc | MSNvB Enc | MSNvB | TOTALS
| | | | Vitamins
1 | . | . | 1 | 1S 3.7V battery protection board
1 | . | . | 1 | Antenna 20cm LoRa Antenna
1 | . | . | 1 | Battery negative contact
1 | . | . | 1 | Battery positive contact
1 | . | . | 1 | Cell Samsung 25R 18650 LION
1 | . | . | 1 | Heltec L76K_GNSS Module
1 | . | . | 1 | Heltec T144
1 | . | . | 1 | Nut M6.25 x 1.8mm
1 | 1 | . | 2 | Solar Panel 100x100mm² 5V 3W
1 | . | . | 1 | Washer star M6.4 x 0.6mm
10 | 1 | . | 11 | Total vitamins count
| | | | 3D printed parts
1 | . | . | 1 | MSNvB_buttons.stl
. | . | 1 | 1 | MSNvB_cov.stl
1 | . | . | 1 | MSNvB_lEnc.stl
1 | . | . | 1 | MSNvB_stand.stl
. | 1 | . | 1 | MSNvB_top.stl
3 | 1 | 1 | 5 | Total 3D printed parts count

## MSNvB LEnc Assembly

### Vitamins

Qty | Description
1 | 1S 3.7V battery protection board
1 | Antenna 20cm LoRa Antenna
1 | Battery negative contact
1 | Battery positive contact
1 | Cell Samsung 25R 18650 LION
1 | Heltec L76K_GNSS Module
1 | Heltec T144
1 | Nut M6.25 x 1.8mm
1 | Solar Panel 100x100mm² 5V 3W
1 | Washer star M6.4 x 0.6mm

### 3D Printed parts

1 x MSNvB_buttons.stl | 1 x MSNvB_lEnc.stl | 1 x MSNvB_stand.stl
MSNvB_buttons.stl | MSNvB_lEnc.stl | MSNvB_stand.stl

### Assembly instructions

MSNvB_lEnc_assembly

1. Clamp the stand on to the enclosure
2. Attach the antenna to the enclosure
3. Connect it to the Heltec T114 board
4. Insert buttons
5. Insert Heltec T114 board
6. Connect and insert the GNSS module (optional)
7. Attach the battery with two zip ties
8. Connect the battery to the Heltec T114 board

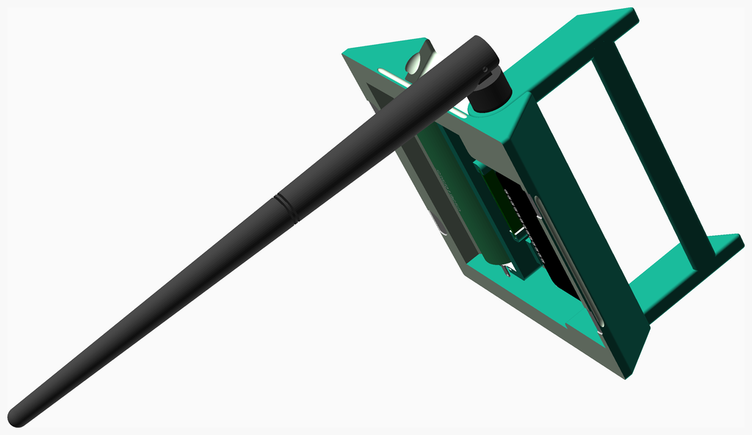
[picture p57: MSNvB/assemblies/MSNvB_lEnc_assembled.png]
MSNvB_lEnc_assembled


## MSNvB Enc Assembly

### Vitamins

Qty | Description
1 | Solar Panel 100x100mm² 5V 3W

### 3D Printed parts

1 x MSNvB_top.stl

MSNvB_top.stl

### Sub-assemblies

1 x MSNvB_lEnc_assembly

MSNvB_lEnc_assembled

### Assembly instructions

MSNvB_enc_assembly

1. Connect the solar panel to the Heltec T114 board
2. Place the solar panel on the enclosure
3. Attach the top frame

MSNvB_enc_assembled

## MSNvB Assembly

### 3D Printed parts

1 x MSNvB_cov.stl

MSNvB_cov.stl

### Sub-assemblies

1 x MSNvB_enc_assembly

MSNvB_enc_assembled

### Assembly instructions

MSNvB_assembly

Slide on the protective cover for transportation.

MSNvB_assembled

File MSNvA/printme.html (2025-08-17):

# LoRaMeshNodes

These are the assembly instructions for the Mobile Solar Node (Variant A) (MSNvA), a portable solar powered Meshtastic (https://meshtastic.org) or MeshCore (https://meshcore.co.uk) node.

Main Assembly

## Table of Contents

1. Parts list
2. MSNvA LEnc Assembly
3. MSNvA Enc Assembly
4. MSNvA Assembly

## Parts list

MSNvA LEnc | MSNvA Enc | MSNvA | TOTALS
| | | | Vitamins
1 | . | . | 1 | Antenna 20cm LoRa Antenna
1 | . | . | 1 | Heltec L76K_GNSS Module
1 | . | . | 1 | Heltec T144
1 | . | . | 1 | Lithium-Polymer-Akku 3,7V 2500mAh
1 | . | . | 1 | Nut M6.25 x 1.8mm
1 | 1 | . | 2 | Solar Panel 100x100mm² 5V 3W
1 | . | . | 1 | Washer star M6.4 x 0.6mm
7 | 1 | . | 8 | Total vitamins count
| | | | 3D printed parts
1 | . | . | 1 | MSNvA_buttons.stl
. | . | 1 | 1 | MSNvA_cov.stl
1 | . | . | 1 | MSNvA_lEnc.stl
1 | . | . | 1 | MSNvA_stand.stl
. | 1 | . | 1 | MSNvA_top.stl
3 | 1 | 1 | 5 | Total 3D printed parts count

## MSNvA LEnc Assembly

### Vitamins

Qty | Description
1 | Antenna 20cm LoRa Antenna
1 | Heltec L76K_GNSS Module
1 | Heltec T144
1 | Lithium-Polymer-Akku 3,7V 2500mAh
1 | Nut M6.25 x 1.8mm
1 | Solar Panel 100x100mm² 5V 3W
1 | Washer star M6.4 x 0.6mm

### 3D Printed parts

1 x MSNvA_buttons.stl | 1 x MSNvA_lEnc.stl | 1 x MSNvA_stand.stl
MSNvA_buttons.stl | MSNvA_lEnc.stl | MSNvA_stand.stl

### Assembly instructions

MSNvA_lEnc_assembly

1. Attach the antenna to the enclosure
2. Connect it to the Heltec T114 board
3. Insert buttons
4. Insert Heltec T114 board
5. Connect and insert the GNSS module (optional)
6. Attach the battery with two zip ties
7. Connect the battery to the Heltec T114 board

MSNvA_lEnc_assembled

## MSNvA Enc Assembly

### Vitamins

Qty | Description
1 | Solar Panel 100x100mm² 5V 3W

### 3D Printed parts

1 x MSNvA_top.stl

MSNvA_top.stl

### Sub-assemblies

1 x MSNvA_lEnc_assembly

MSNvA_lEnc_assembled

### Assembly instructions

MSNvA_enc_assembly

1. Connect the solar panel to the Heltec T114 board
2. Place the solar panel on the enclosure
3. Attach the top frame

MSNvA_enc_assembled

## MSNvA Assembly

### 3D Printed parts

1 x MSNvA_cov.stl

MSNvA_cov.stl

### Sub-assemblies

1 x MSNvA_enc_assembly

MSNvA_enc_assembled

### Assembly instructions

MSNvA_assembly

Slide on the protective cover for transportation.

MSNvA_assembled

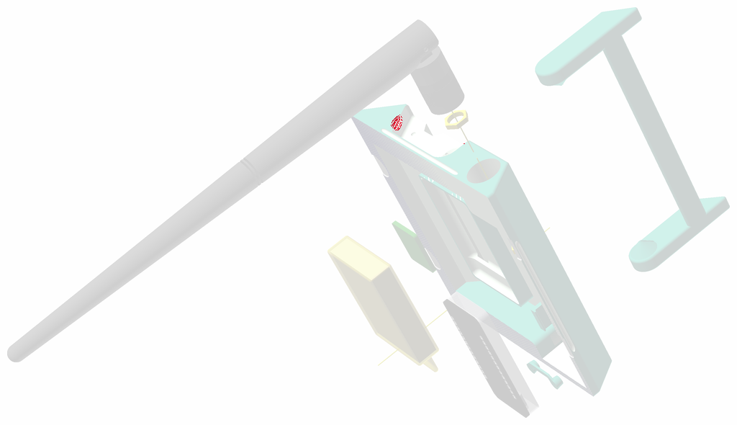
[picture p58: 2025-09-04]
MSNvA/assemblies/MSNvA_lEnc_assembly_diff.png

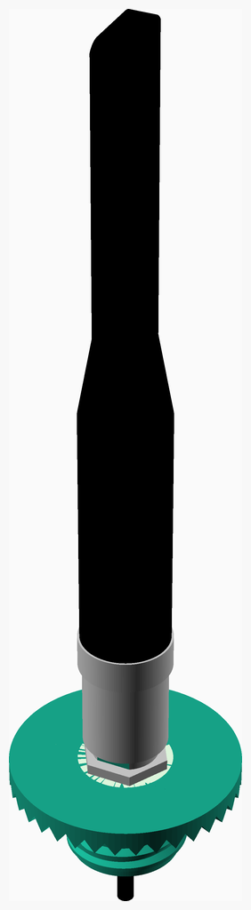
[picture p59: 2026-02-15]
SSNvB/assemblies/SSNvB_antenna_assembled.png

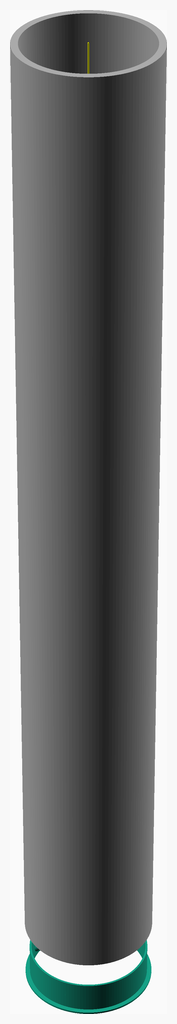
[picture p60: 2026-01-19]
SSNvD/assemblies/SSNvD_pole_assembly.png

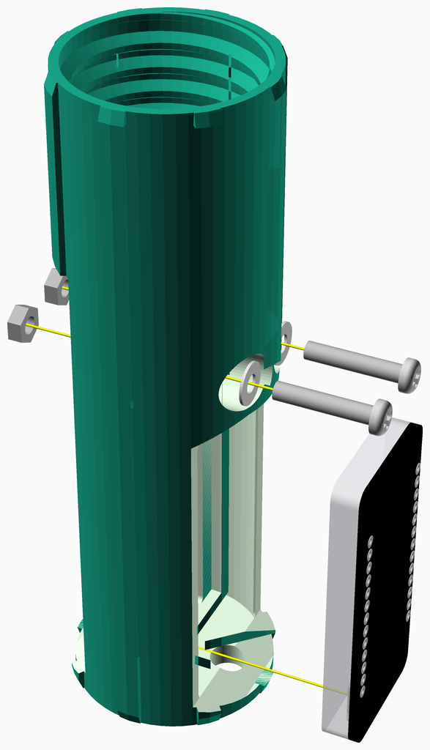
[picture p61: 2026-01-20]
SSNvA/assemblies/SSNvA_radio_assembly.png

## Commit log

2025-07-18 added initial SSNvA and MSNvA top level files
    [LMN_Config.scad, LMN_SSNvA.scad, config_MSNvA.scad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]
2025-07-28 work in progres
    [LMN_Heltec_T114.scad, LMN_MSNvA.scad, LMN_antenna.scad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]
2025-08-17 MSNvA finished
    [LMN_MSNvA.scad, MSNvA_buttons.stl, MSNvA_stand.stl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]
2025-08-17 added cover
    [LMN_MSNvA.scad, MSNvA_cov.stl]
2025-09-02 finished initial MSNvB design
    [LMN_BMS.scad, LMN_MSNvB.scad, config_MSNvB.scad]
2025-09-03 Processed MSNvB
    [LMN_MSNvB.scad, MSNvB_buttons.stl, MSNvB_cov.stl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]
2025-09-03 fixed documentation
    [LMN_MSNvB.scad, MSNvB_cov.stl, MSNvB_stand.stl]
2025-09-03 design fixes
    [LMN_MSNvA.scad, LMN_MSNvB.scad, MSNvA_stand.stl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]
2025-09-03 minor adjustments
    [LMN_MSNvA.scad, LMN_MSNvB.scad]
2025-10-06 work in progress
    [LMN_BMS.scad, LMN_Heltec_T114.scad, LMN_MSNvB.scad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]
2025-10-20 added SSNvA
    [LMN_SSNvA_antenna.scad, LMN_SSNvA_radio.scad, LMN_SSNvA_scruton.scad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]
2025-10-27 included missing battery frame STLs
    [LMN_Common.scad, LMN_Config.scad, LMN_SSNvA_battery.scad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]
2025-10-28 included screw handle
    [LMN_SSNvA_battery.scad, SSNvA_battery_screw_handle.stl]
2025-10-28 included battery cable clamp
    [LMN_SSNvA_battery.scad, SSNvA_battery_cable_clamp.stl]
2025-12-31 added LiFePo4Charger
    [LMN_Config.scad, LMN_LiFePo4Charger.scad, LMN_SSNvA.scad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]
2026-01-19 added SSNvD
    [LMN_SSNvD.scad, LMN_SSNvD_antenna.scad, LMN_SSNvD_battery.scad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]
2026-01-19 compiled SSNvD
    [SSNvD_antenna_part1.stl, SSNvD_antenna_part2.stl, SSNvD_antenna_top.stl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]
2026-01-19 put bajonet lock on end cap
    [LMN_SSNvD_mounts.scad]
2026-01-19 adjusted end cap
    [LMN_SSNvD_mounts.scad]
2026-01-20 updated solar mount
    [LMN_SSNvA_mounts.scad, LMN_SSNvD_mounts.scad, SSNvA_radio_frame_part1.stl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]
2026-01-20 fixed battery frame
    [LMN_SSNvD_battery.scad, LMN_antenna.scad, LMN_lipo.scad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]
2026-01-23 added MNvA
    [LMN_MNvA.scad, LMN_SSNvD_battery.scad, MNvA_buttons.stl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]
2026-01-23 fixed MNA setup
    [LMN_MNvA.scad]
2026-01-23 fixed MNA lid
    [LMN_MNvA.scad, MNvA_uEnc.stl]
2026-01-24 fixed T114 holder
    [LMN_MNvA.scad, MNvA_lEnc.stl]
2026-01-26 extended buttons
    [LMN_Heltec_T114.scad, LMN_MNvA.scad, MNvA_buttons.stl]
2026-01-26 changed screw type
    [LMN_Heltec_T114.scad, LMN_MNvA.scad, MNvA_lEnc.stl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]
2026-01-26 design fix
    [LMN_MNvA.scad, MNvA_lEnc.stl]
2026-01-26 adjustments after 1st MNvA build
    [LMN_MNvB.scad, MNvA_lEnc.stl, MNvA_uEnc.stl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]
2026-01-27 adjustments after 2nd MNvA build
    [LMN_MNvA.scad, LMN_MNvB.scad, MNvA_lEnc.stl]
2026-01-27 adjustments after 3rd MNvA build
    [LMN_MNvA.scad, MNvA_lEnc.stl, bom.csv]
2026-01-28 adjustments after 4th MNvA build
    [LMN_MNvA.scad, MNvA_lEnc.stl]
2026-01-28 adjustments after 5th MNvA build
    [LMN_MNvA.scad, MNvA_lEnc.stl]
2026-02-09 added MNvB
    [LMN_MNvB.scad, MNvA_uEnc.stl, MNvB_buttons.stl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]
2026-02-10 fixed MNvB
    [LMN_MNvB.scad, MNvB_lEnc.stl, MNvB_uEnc.stl]
2026-02-11 adjustments after first MNvB built
    [LMN_MNvA.scad, LMN_MNvB.scad, MNvA_lEnc.stl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]
2026-02-15 added SSNvB
    [LMN_MNvA.scad, LMN_SSNvB.scad, LMN_SSNvB_antenna.scad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]
2026-02-17 design adjustments for SSNvB
    [LMN_SSNvB.scad, LMN_SSNvB_mounts.scad, SSNvB_antennaMountFastener.stl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]
2026-02-28 new enclosure mount for SSNvD
    [LMN_SSNvB.scad, LMN_SSNvB_mounts.scad, SSNvB_LIEncMount.stl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]
